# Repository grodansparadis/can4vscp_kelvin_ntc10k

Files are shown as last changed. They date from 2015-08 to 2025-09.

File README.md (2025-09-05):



-----

This project is part of the <a href="http://www.vscp.org">VSCP (Very Simple Control Protocol) project</a>. 

<hr>

# Kelvin NTC10K

This module is part of the [VSCP project](https://www.vscp.org).  It is free to use, modify and sell. The only thing we kindly ask is that improvements and extensions are contributed back to the project (at your will). This to make the project better for everyone. All design files is licensed under the [MIT license](https://en.wikipedia.org/wiki/MIT_License).

The full documentation for the module can be found [here](http://grodansparadis.github.io/can4vscp_kelvin_ntc10k/#/).



In this repository you find all development files for the Kelvin NTC10K module. The project together with the [Paris Relay Module](https://github.com/grodansparadis/can4vscp_paris) is the main examples for a VSCP implemention on a Microchip 18F PIC device.

## Abstract

Kelvin NTC10K is a temperature module that can handle six temperature sensors. One internal and five external.

The Kelvin NTC10KA module measures temperature. It measures temperatures in a wide range (depending on what sensors are used) and can achieve 0.1C accuracy with calibration. It does so by allowing connection of up to five external NTC temperature sensors and by measuring the temperature on the surface of the module itself. The measured temperature can be reported to other CAN4VSCP modules or to one or several servers so it can be collected in a database or visualized and analyzed in a diagram. The accuracy of the sensors can be increase further by calibration.

Temperature data can be presented by the module in Kelvin, Celsius or Fahrenheit.

Temperatures is reported automatically and it is possible to set alarms for high/low levels. Absolute low and high temperatures are collected and it is easy to construct autonomous and reliable temperature regulation systems.

NTC sensors has the advantage of being low cost, possible to get high accuracy from and ease of use with long cable runs. No calibration is usually needed if +-1 degree accuracy is OK.

The module fully adopts to the CAN4VSCP specification and can be powered directly over the bus with a 9-28V DC power source. It has a rich register set for configuration and any information events defined. It also have a decision matrix for easy dynamic event handling.

VSCP CAN modules are designed to work on a CAN4CAN bus which use ordinary RJ-45 connectors and is powered with 9-28V DC over the same cable. This means there is no need for a separate power cable. All that is needed is a CAT5 or better twisted pair cable. Buss length can be a maximum of 500 meters with drops of maximum 24 meters length (up to a total of 120 meters). As for all CAN4VSCP modules the communication speed is fixed at 125 kbps.

All VSCP modules contains information of there own setup, manual, hardware version, manufacturer etc. You just ask the module for the information you need and you will get it. When they are started up they have a default functionality that often is all that is needed to get a working setup. If the module have something to report it will send you an event and if it is setup to react on a certain type of event it will do it's work when you send event(s) to it. 

---

## Project files

### User manual
  * [User Manual](https://grodansparadis.github.io/can4vscp_kelvin_ntc10k/#)

### Schematic, PCB, 3D files etc
  * [Schematics reversion A](https://raw.githubusercontent.com/grodansparadis/can4vscp_accra/refs/heads/master/eagle/accra_sch_rev_A.png)
 * Hardware design files is made in [KiCad](https://kicad.org) and can be found in the `kicad` directory. Valid from reversion B of the hardware.
   * Gerber files for PCB production can be found in the `gerber` directory (in the `kicad` folder).
 * Eagle schema and board files for reversion A and B can be found in the `eagle` directory. They are no longer actively updated.

 ### Firmware

 The firmware is developed in [MPLAB X IDE](https://www.microchip.com/mplab/mplab-x-ide) using the [XC8 compiler](https://www.microchip.com/mplab/compilers).

  * Binary release files is available [here](https://github.com/grodansparadis/can4vscp_kelvin_ntc10k/releases)

### MDF - Module Description File(s)
  * [MDF file version: 1.2.0 Release date: 2015-02-18](http://www.eurosource.se/ntc10KA_3.xml)
  * [MDF file version: 1.1.0 Release date: 2014-12-24](http://www.eurosource.se/ntc10KA_2.xml)
  * [MDF file version: 1.0.0 Release date: 2012-02-24](http://www.eurosource.se/ntc10KA_1.xml)

### Support
If you need support, please open an issue in the [GitHub repository](https://github.com/grodansparadis/can4vscp_kelvin_ntc10k/issues).

### Buy a ready made modules
You can buy a ready made module from [Grodans Paradis](http://www.grodansparadis.com).

### Project related links
  * [VSCP project](https://www.vscp.org)
  * [VSCP Documentation site](https://docs.vscp.org/)
  * [VSCP Wiki](https://github.com/grodansparadis/vscp/wiki)

## Steps you should go through to adopt this file for your own VSCP project.

  * The frequency for your system may be different. This will affect the CAN bit rate settings which are defined in the biginning of the can18f.c file. Here you also find the filter/mask  defines if you need to change these. Timer0 is used as a 1 ms timer for the VSCP functionality. You should adopt the timer reload value in the main.h file to your system.

  * The GUID (Glocal Unique ID) is defined in the beginning of vscp.c This number should be different for each piece of equiment you produce. Regard it is as the device serial number. It can be moved to EEPROM if that is found more convinient. In that case the vscp_rcv_readreg  procedure in vscp.c also has to be changed.

  * The device URL is defined in the beginning of the vscp.c file. This is an URL without the initial "http://" that should point to a XML file that give information about your piece of equipment.

  * The manufacturer id is also defined in the beginning of the vscp.c file. You can use this id in any way you like.

In addition to this you may use different pins for the INIT button (RC0 today) and the status LED (RC1) today. Changes affect the main interrupt vector.

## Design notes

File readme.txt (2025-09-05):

This is the readme file for the Kelvin NTC10KA project. This project is also the base for a VSCP 
implementation on a Microchip 18F PIC device. This is a commercial module that can bought from 
Grodans Paradis ( see http://www.auto.grodansparadis.com/kelvinntc10k/kelvin_ntc10ka.html)

The processor used is the Microchip PIC18F2580 or PIC18F25K80

MPLAB X is used to build the project. Some files

eprom.h - VSCP root/firmware/pic/common)
eprom.c - (VSCP root/firmware/pic/common)
vscp_firmware.h - (VSCP root/firmware/common)
vscp_firmware.c - (VSCP root/firmware/common)
vscp_class.h - (VSCP root/src/vscp/common)
vscp_type.h - (VSCP root/src/vscp/common)

Where "VSCP Root" is the location where you installed the VSCP source tree.  Go to project page for the 
VSCP project (http://www,vscp,org) and download the sourcetree to get access to the file. 

"_reloc" projects are built for use with the bootloader. The bootloader occupies space between 0x000 and 0x1ff. 
Vectors are relocated to 0x200. This is managed in the linker scripts. Also the C initialization code has 
been changed to start code at the relocated vector. This also means that the bootloader has to be programmed
into the chip before the working with the project. It also means that the environment must be configured 
*not* to erase the chip before programming it.

If no bootloader is required it is OK to use the standard C startup code, a standard linker description. In this 
case the absolute vector address for the low priority interrupt in main.c  must be changed back from 0x218 to 0x18.

Steps you should go through to adopt this file for your own VSCP project.
=========================================================================

1.) The frequency for your system may be different. This will affect the CAN bit rate settings
which are defined in the beginning of the can18f.c file. Here you also find the filter/mask 
defines if you need to change these.

Timer0 is used as a 1 ms timer for the VSCP functionality. You should adopt the timer reload value 
in the main.h file to your system.

2.) The GUID (Global Unique ID) is defined in the beginning of vscp.c This number should be 
different for each piece of equipment you produce. Regard it is as the device serial number. It
can be moved to EEPROM if that is found more convenient. In that case the vscp_rcv_readreg 
procedure in vscp.c also has to be changed.

3.) The device URL is defined in the beginning of the vscp.c file. This is an URL without the
initial "http://" that should point to a XML file that give information about your piece of 
equipment.

4.) The manufacturer id is also defined in the beginning of the vscp.c file. You can use this
id in any way you like.

In addition to this you may use different pins for the INIT button (RC0 today) and the 
status LED (RC1) today. Changes affect the main interrupt vector.

Ake Hedman
Grodans Paradis AB
info@grodansparadis.com
http://www.grodansparadis.com

VSCP (Very Simple Control Protocol) 
http://www.vscp.org

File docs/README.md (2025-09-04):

# Manual for the Kelvin NTC10K module

**Document version:** ${/var/document-version} - ${/var/creation-time}
[HISTORY](./history.md)

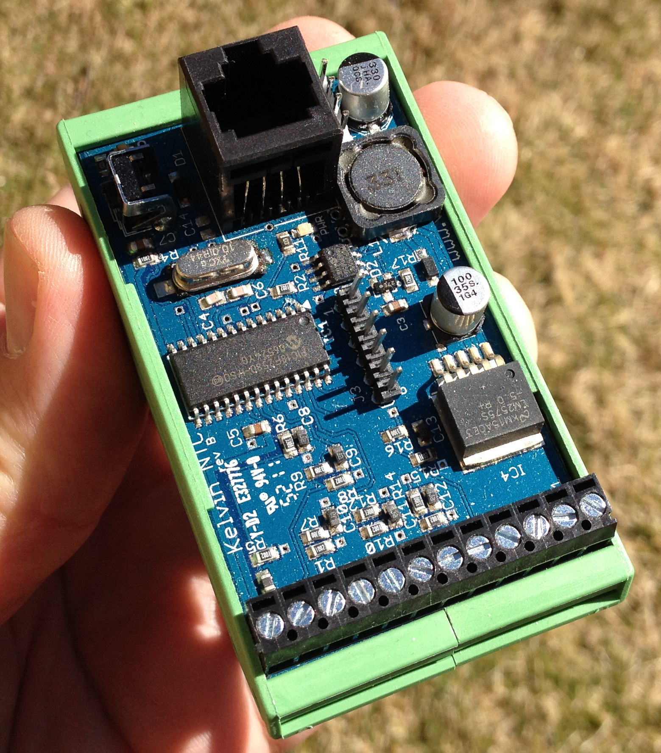
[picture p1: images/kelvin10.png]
Paris


The Kelvin NTC10KA module measures temperature. It measures temperatures in a wide range (depending on what sensors are used) and can achieve 0.1C accuracy with calibration. It does so by allowing connection of up to five external NTC temperature sensors and by measuring the temperature on the surface of the module itself. The measured temperature can be reported to other CAN4VSCP modules or to one or several servers so it can be collected in a database or visualized and analyzed in a diagram. The accuracy of the sensors can be increase further by calibration.

Temperature data can be presented by the module in Kelvin, Celsius or Fahrenheit.

Temperatures is reported automatically and it is possible to set alarms for high/low levels. Absolute low and high temperatures are collected and it is easy to construct autonomous and reliable temperature regulation systems.

NTC sensors has the advantage of being low cost, possible to get high accuracy from and ease of use with long cable runs. No calibration is usually needed if +-1 degree accuracy is OK.

The module fully adopts to the CAN4VSCP specification and can be powered directly over the bus with a 9-28V DC power source. It has a rich register set for configuration and any information events defined. It also have a decision matrix for easy dynamic event handling.

VSCP CAN modules are designed to work on a CAN4CAN bus which use ordinary RJ-45 connectors and is powered with 9-28V DC over the same cable. This means there is no need for a separate power cable. All that is needed is a CAT5 or better twisted pair cable. Buss length can be a maximum of 500 meters with drops of maximum 24 meters length (up to a total of 120 meters). As for all CAN4VSCP modules the communication speed is fixed at 125 kbps.

All VSCP modules contains information of there own setup, manual, hardware version, manufacturer etc. You just ask the module for the information you need and you will get it. When they are started up they have a default functionality that often is all that is needed to get a working setup. If the module have something to report it will send you an event and if it is setup to react on a certain type of event it will do it's work when you send event(s) to it. 

  * [GitHub repository for the module](https://github.com/grodansparadis/can4vscp_kelvin_ntc10k)
  * This manual is available [here](https://grodansparadis.github.io/can4vscp_kelvin_ntc10k/)
  * Latest KiCad schema for the module is available [here](https://github.com/grodansparadis/can4vscp_kelvin_ntc10k/tree/master/kicad)
  * Latest firmware for the module is available [here](https://github.com/grodansparadis/can4vscp_kelvin_ntc10k/tree/master/firmware)
  * [MDF for the module](https://github.com/grodansparadis/can4vscp_kelvin_ntc10k/tree/master/mdf)

## VSCP

VSCP logo

VSCP is a free and open automation protocol for IoT and m2m devices. Visit [the VSCP site](https://www.vscp.org) for more information.

**VSCP is free.** Placed in the **public domain**. Free to use. Free to change. Free to do whatever you want to do with it. VSCP is not owned by anyone. VSCP will stay free and gratis forever.

The specification for the VSCP protocol is [here](https://docs.vscp.org) 

VSCP documentation for various parts can be found [here](https://docs.vscp.org/).

If you use VSCP please consider contributing resources or time to the project ([https://vscp.org/support.php](https://vscp.org/support.php)).

## Document license

This document is licensed under [Creative Commons BY 4.0](https://creativecommons.org/licenses/by/4.0/) and can be freely copied, redistributed, remixed, transformed, built upon as long as you give credits to the author.

[filename](./bottom-copyright.md ':include')

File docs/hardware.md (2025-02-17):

# Hardware

## Most current information

You can find the most current information about the Kelvin NTC10K module [here](https://github.com/grodansparadis/can4vscp_kelvin_ntc10k). On the site you can also find links to the latest firmware, drivers and schematics etc for its use.

## Installing the module

Connect the module to the CAN4VSCP bus. The red LED on the module should light up indicating that the device is powered. If this is the first time you start up the module the green lamp next to the initializing button will start to blink. This means that the module is trying to negotiate a nickname address with the rest of the modules on the bus. When it found a free nickname the green LED will light steady. If the green led does not start to blink press the initialization button until it does.

Remember that you need at least two devices (a CAN interface count as one) on the bus for it to work. If you only have one device on the bus it will not work. A single device can't talk to itself on a bus. It's an error.

Now your module is ready to use. 

## The raw facts

| Parameter | Value |
| --- | ----- |
| Current hardware reversion | B |
| Current firmware version | 1.2.7 |
| Supply voltage | +9-+28 VDC |
| PCB Size | 42mm x 72mm |
| Mounting options | DIN or wall |
| Power requirements | 0.1W |
| Communication: CAN4VSCP (CAN) | 125 kbps |
| Number of sensors supported | 6 (one internal) |

## Schematics

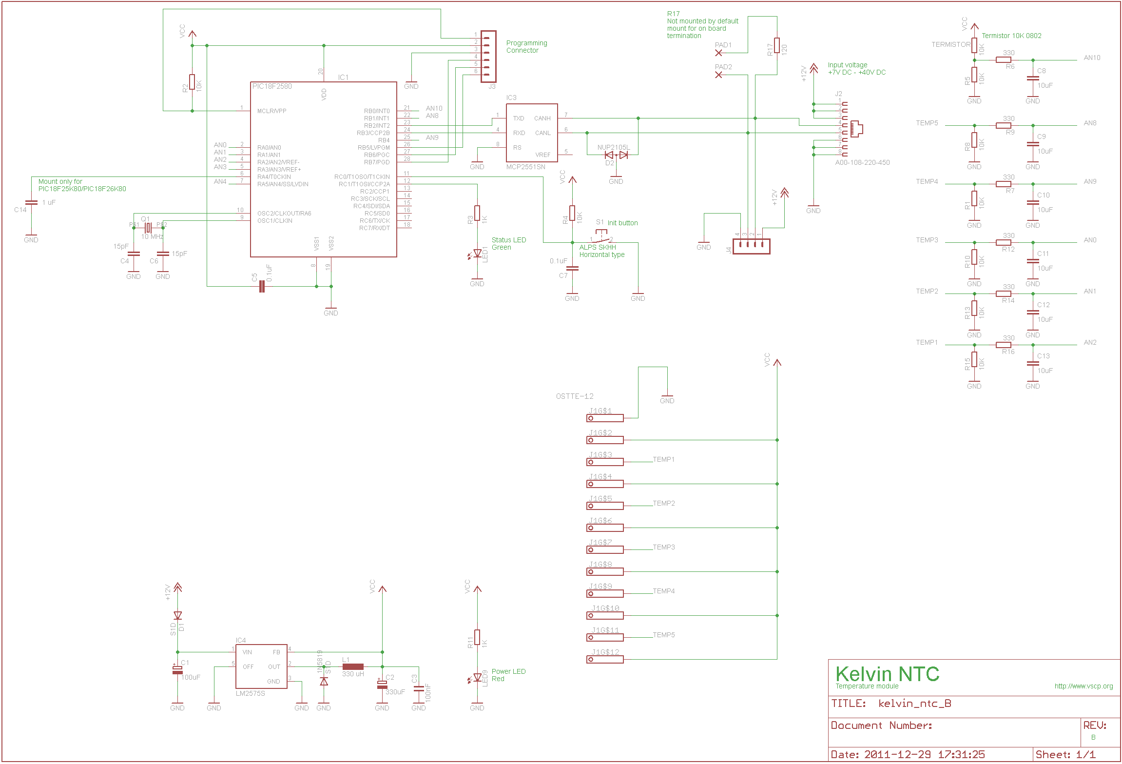
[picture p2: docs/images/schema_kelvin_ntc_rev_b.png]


Schematics: Rev B  (right click and select view image to see it in full size)

## Components

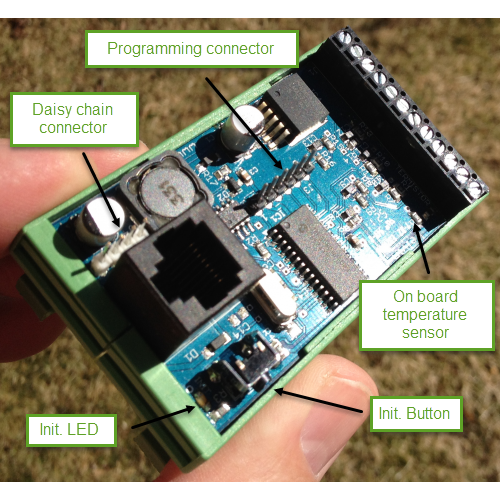
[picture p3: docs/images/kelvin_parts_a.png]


The green **Init LED** show operational status. It blinks during initialization process and lights steady under normal operation.

Press the **init. button** to initiate the node id discovery process. The green led will start to blink and do so until a new nickname id is found. If the LED never stops blinking that is an indication of some bus fault of some kind. Typically the module does not get an answer from another module on the bus.

The **daisy chain** connector is described below.

The firmware of a circuit equipped with a Microchip microprocessor usually can be programmed in circuit. That is when it is mounted on a printed circuit board. This is also true for the Paris relay module which have the programming connector on-board (J3). The **programming
connector** is used to reprogram the module. This is more convenient to do using the bootloader software but in debugging or if the bootloader has gotten corrupt connecting a standard Microchip PIC programmer to this connector is the only way to reprogram the module. If you have a programmer for Microchip processors (Real ICE, ICD-2, ICD-3, PICKIT-2, PICKIT3 or other) you can program your own firmware or the latest official firmware into the module using MPLABX or similar tools. You can always find a link to the latest firmware on the [Kelvin NTC10K module
home page](https://www.grodansparadis.com/kelvinntc10k/kelvin_ntc10ka.html).

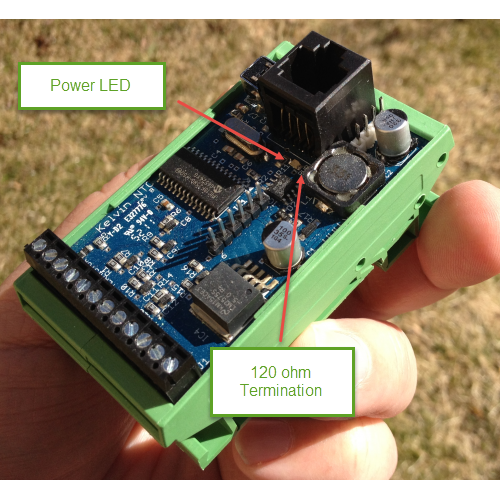
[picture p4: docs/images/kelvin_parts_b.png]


The **power LED** (red) will light when the board is powered.

The **termination jumper** is used to activate the 120 ohm termination resistor between CANH and CANL if present. This is convenient if the module is the first or last module on a bus.

## Connectors

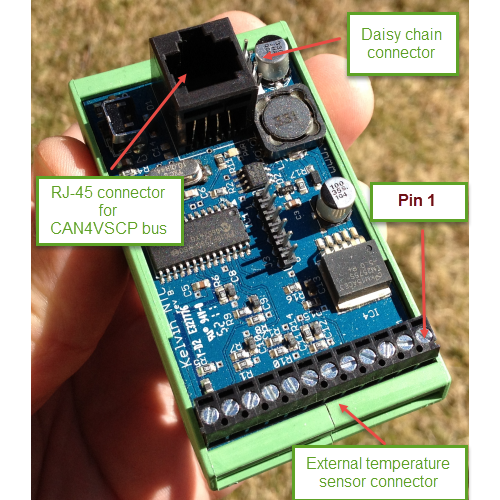
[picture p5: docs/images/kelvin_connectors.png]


To activate the **termination** solder a cable between holes. This will activate the 120 ohm resistor between CANH and CANL.

### Terminal block

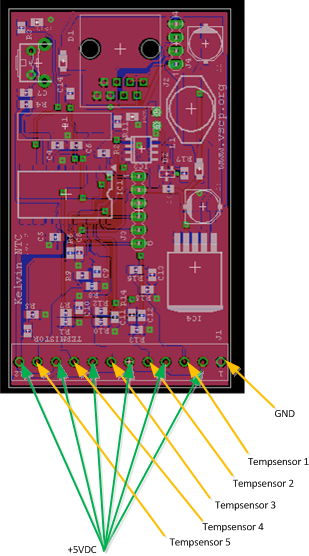
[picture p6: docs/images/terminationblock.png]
  

The individual positions for the twelve position termination block is numbered from the right (looking into it) as in the figure below.



| Pin | Description |
| --- | --- |
| 1 | Ground (GND) |
| 2 | +5V |
| 3 | Temperature sensor 1 |
| 4 | +5V|
| 5 | Temperature sensor 2|
| 6 | +5V|
| 7 | Temperature sensor 3 |
| 8 | +5V |
| 9 | Temperature sensor 4 |
| 10 | +5V |
| 11 | Temperature sensor 5 |
| 12 | +5V |

where all temperature sensor inputs looks like this

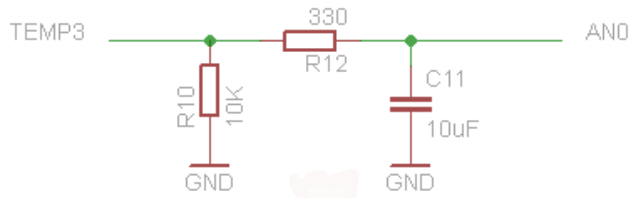
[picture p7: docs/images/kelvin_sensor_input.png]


## Internal temperature sensor

The internal temperature sensor used on the Kelvin NTC10KA is the [Murata NCP21XV103J03RA](https://www.google.se/url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). Data for this sensor is as follows

| Description | Value |
| --- | ----- |
| Time constant | 10 s |
| B[25/100]- value | 3944K |
| Temperature range |-40...+125ºC |
| Resistance tolerance | 5% |
| Resistance @ 25ºC | 10 Kohm |
| Max effect | 210 @ 25ºC mW |
| B[25/50]- value | 3900 |
| B[25/85]- value | 3934 |
| B[25/100]- value | 3944K 3% |
| Max error (B[25/100])	| 2.8 (%/C) |

As stated elsewhere this sensor will show a temperature value that is to high due to the fact that it is heated by the processor and other components on the board. You can calibrate this away if you want. The sensor is used to show the temperature of the board and is not intended to be used for high precision measurements.

### RJ-XX pin-out

The unit is powered over the CAN4VSCP bus. The CAN4VSCP normally uses CAT5 or better twisted pair cable. You can use other cables if you which. The important thing is that the CANH and CANL signals uses a twisted cable. For connectors you can use RJ10, RJ11, RJ12 or the most common RJ45 connectors.

Recommended connector is RJ-34/RJ-12 or RJ-11 with pin out as in this table.

| Pin | Used for  | RJ-11  | RJ-12 | RJ-45 |  Patch Cable wire color T568B |
|:---:|:---:|:---:|:-----:|:-----:| --- |
|  1 | +9-28V DC | | | RJ-45 | Orange/White |
|  2 1 | +9-28V DC | | RJ-12 | RJ-45 | Orange |
|  3 2 1  | +9-28V DC | RJ-11  | RJ-12 | RJ-45 | Green/White |
|  4 3 2  | CANH | RJ-11  | RJ-12 | RJ-45 | Blue |
|  5 4 3  | CANL | RJ-11  | RJ-12 | RJ-45 | Blue/White |
|  6 5 4  | GND | RJ-11  | RJ-12 | RJ-45 | Green |
|  7 6 | GND | | RJ-12 | RJ-45 | Brown/White |
|  8 | GND | | | RJ-45 | Brown |

RJ-11/12/45 pin-out

Always use a pair of twisted wires for CANH/CANL for best noise immunity. If the EIA/TIA 56B standard is used this condition will be satisfied. This is good as most Ethernet networks already is wired this way.

### Inter module connector

The inter module connector can be used to connect modules that are physically close to each other together in an easy way. Remember that the minimum length of a connection cable is 30 cm.

The **daisy chain connector** is an alternative to the RJ-45 connector and can be a very convenient way to connect boards together that are mounter close to each other, in the same cabinet for example. The [power injector board](http://www.grodansparadis.com/pwrinjectcan/pwrinjectcan.html) is a perfect companion for this use.

| Pin | Description |
| :---: | --- |
| 1 | Power from CAN4VSCP bus (+9V-24V) |
| 2 | CANH |
| 3 | CANL |
| 4 | GND |

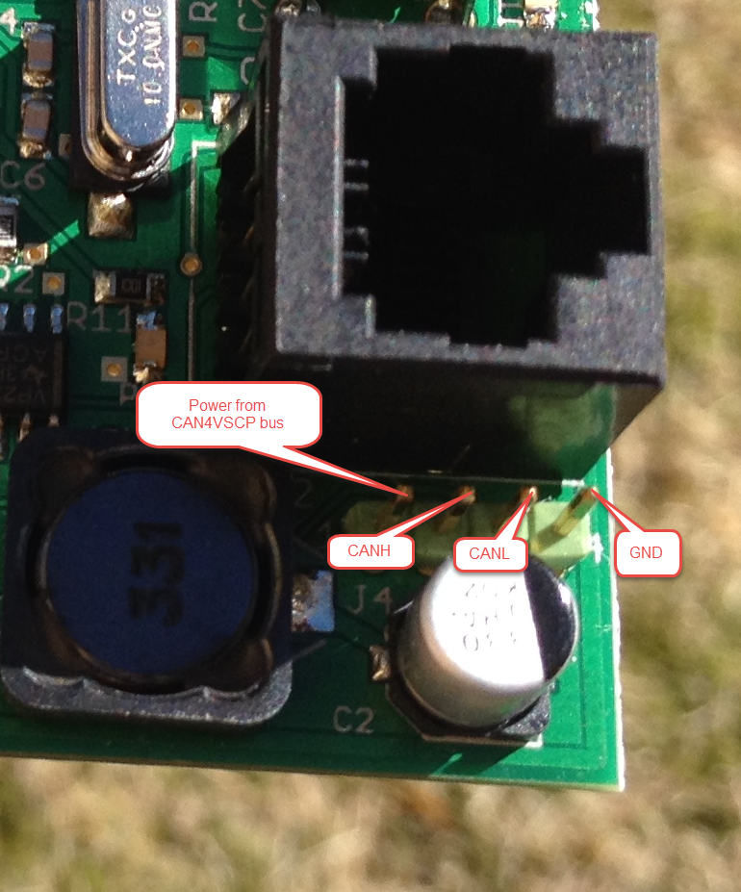
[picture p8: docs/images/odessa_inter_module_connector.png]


### PIC programming Connector

| pin | Description |
| :---: | --- |
| 1 | Reset |
| 2 | VCC |
| 3 | GND |
| 4 | PGD (RX of second serial port is here to) |
| 5 | PGC (TX of second serial port is here to) |
| 6 | LWPGM |

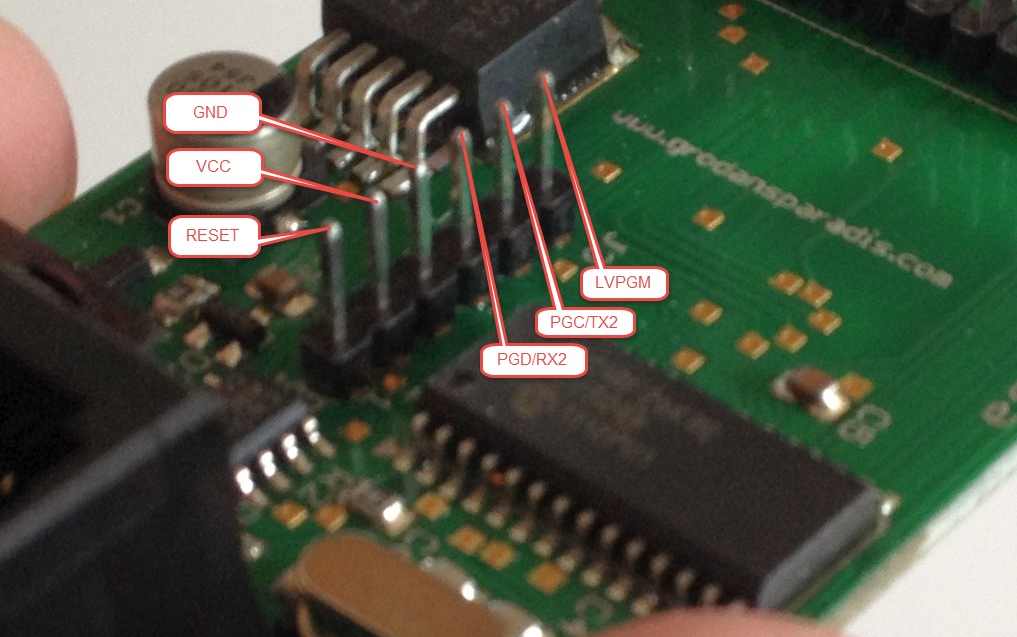
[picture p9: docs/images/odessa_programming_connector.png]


### Functionality of the status LED

The LED is used to indicate the status of the module. It will light steady when the firmware is running and will blink when the module is in the nickname discovery process.

| LED | Description |
| :---: | --- |
| Steady | No error. Firmware running. |
| Blinking | Module is going through the [nickname discovery process](https://grodansparadis.github.io/vscp-doc-spec/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). |

### CAN

CAN4VSCP is a CAN based bus running at 125 kbps with the addition of DC power. If you are interested in how CAN works you have a pretty good intro [here](http://www.eeherald.com/section/design-guide/esmod9.html).

CAN is known to be robust and is there for used in vehicles and in the industry for that reason.

[filename](./bottom-copyright.md ':include')

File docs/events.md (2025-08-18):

# Events

Here the events sent by the module is described.

 ====== Events ======

Here the events sent by the module is described.

===== Temperature Event =====

^ Event ^ Description ^
|  [[http://www.vscp.org/docs/vscpspec/doku.php?id=class1.measurement#type_6_0x06_temperature|CLASS1.MEASUREMENT (10) Type=6, Temperature]]  | If enabled this event is sent periodically for each sensor. The temperature is reported as a normalized integer value by this event. The event frequency is set in register 20-25 (default is one event per 30 seconds) and must be set to a non zero value for it to be sent.\\ \\ Temperature can be reported in one of three units. Kelvin, Celsius (default) or Fahrenheit as set in register 2-7. \\ \\ __**Data**__\\ **Byte 0** - Data coding byte. See description below.\\ **Byte 1** - Always 130 (0x82). Decimal point should be shifted two steps to the left = divide with hundred.\\ **Byte 2** - MSB of normalized integer. Two complement number.\\ **Byte 3** - LSB of normalized integer. Two complement number.\\ \\  |

The data coding byte is the measurement data coding format described in [[http://www.vscp.org/docs/vscpspec/doku.php?id=data_coding|the VSCP specification]].

The normalized integer is stored as a two complement 16-bit integer. To convert

1. Calculate the 16-bit twos complement as MSB byte * 256 + LSB byte.

2. If the most significant bit is not set (Equal or less then 32767) this is a positive temperature. Divide by 100 and you have the temperature. 

3. If the most significant bit is set (Greater than 32767) this is a negative temperature. Now invert the result (the bits are inverted; 0 becomes 1, and 1 becomes 0) and add one to the result. Dive by 100 and you have the temperature.

==== Example: A negative temperature in Celsius from sensor 1 ====

The data part of the event will be

^ Byte ^ Description ^
| Byte 0 | 130 (0x82) |
| Byte 1 | 2 (0x02) |
| Byte 2 | 255 (0xF0) |
| Byte 3 | 216 (0x60) |

  - **Byte 0**: Normalized integer, Celsius, Sensor 1
  - **Byte 1**: Decimal point should be shifted two steps to the left.
  - **Byte 2/3**: Bit 16 is a one meaning it's a negative number. Temperature is a two complement number. 0xF060 = 0b1111000001100000. Invert which give 0b0000111110011111 add one which give 0b0000111110100000 = 4000. Divide by 100 gives 40.00 The read temperature is -40.00 ºC.

==== Example: A positive temperature in Celsius from sensor 1 ====

The data part of the event will be

^ Byte ^ Description ^
| Byte 0 | 130 (0x82) |
| Byte 1 | 2 (0x02) |
| Byte 2 | 46 (0x2E) |
| Byte 3 | 224 (0xE0) |

  - **Byte 0**: Normalized integer, Celsius, Sensor 1
  - **Byte 1**: Decimal point should be shifted two steps to the left.
  - **Byte 2/3**: Bit 16 is zero meaning it's a positive number. 0x2EE0 = 12000. Divide by 100 gives 120.00. The temperature is 120.00 ºC. 

==== Example: A negative temperature in Fahrenheit from sensor 5 ====

The data part of the event will be

^ Byte ^ Description ^
| Byte 0 | 249 (0xF9) |
| Byte 1 | 2 (0x02) |
| Byte 2 | 255 (0xFF) |
| Byte 3 | 118 (0x76) |

  - **Byte 0**: Normalized integer, Fahrenheit, Sensor 5
  - **Byte 1**: Decimal point should be shifted two steps to the left.
  - **Byte 2/3**: Bit 16 is a one meaning it's a negative number. Temperature is a two complement number. 0xFF76 = 0b1111111101110110. Invert which give 0b0000000010001001 add one which give 0b0000000010001010 = 138. Divide by 100 gives 1.38 The read temperature is -1.38 ºF.

==== Data coding byte for Kelvin ====

^ Bits ^ Description ^
| 5,6,7	| Always set to 4 (0b100) - Normalized integer format. |
| 3,4 | __**Unit**:__\\ **0 (0b00)** - Kelvin.\\  **1 (0b01)** – Celsius.\\  **2 (0b10)** – Fahrenheit. |
| 0,1,2	| __**Sensor Index**:__\\ **0 (0b000)** - Sensor 0.\\ **1 (0b001)** - Sensor 1.\\ **2 (0b010)** - Sensor 2.\\ **3 (0b011)** - Sensor 3.\\ **4 (0b100)** - Sensor 4.\\ **5 (0b101)** - Sensor 5. |

To help to interpret data the three tables below list the datacoding bytes for Kelvin, Celsius and Fahrenheit temperature presentation.

=== Kelvin data coding table ===

^ Sensor ^ Value for data coding byte ^
| Sensor 0 | 129 (0x81) |
| Sensor 1 | 130(0x82) |
| Sensor 2 | 131(0x83) |
| Sensor 3 | 132(0x84) |
| Sensor 4 | 133(0x85) |
| Sensor 5 | 134(0x86) |

=== Celsius data coding table ===

^ Sensor ^ Value for data coding byte ^
| Sensor 0 | 136(0x88) |
| Sensor 1 | 137(0x89) |
| Sensor 2 | 138(0x8A) |
| Sensor 3 | 139(0x8B) |
| Sensor 4 | 140(0x8C) |
| Sensor 5 | 141(0x8D) |

=== Fahrenheit Vdata coding table ===
^ Sensor ^ Value for data coding byte ^
| Sensor 0 | 244 (0xF4) |
| Sensor 1 | 245 (0xF5) |
| Sensor 2 | 246 (0xF6) |
| Sensor 3 | 247 (0xF7) |
| Sensor 4 | 248 (0xF8) |
| Sensor 5 | 249 (0xF9) |

===== Alarm Event =====

If enabled the event is sent when a temperature sensor goes below a low alarm set point (see [[http://www.grodansparadis.com/kelvinntc10k/manual/doku.php?id=registers|Low-alarm-registers]]) or above a high alarm set point (see [[http://www.grodansparadis.com/kelvinntc10k/manual/doku.php?id=registers|High-alarm-registers]]). The hysteresis registers is used so that after an alarm event has been sent a new alarm event is not sent until the temperature goes below/above the value set in the set point plus(low)/minus(high) signed content of hysteresis register. 

A read of the alarm register will reset the alarm status and alarm events will not be sent out again until the the temperature changed with the hysteresis amount.

^ Event ^ Description ^
|  [[http://www.vscp.org/docs/vscpspec/doku.php?id=class1.alarm#type_2_0x02_alarm_occurred|CLASS1.ALARM, Type=2, Alarm occurred]]  | __**Data**__\\ **Byte 0** - Index. Index is 0 for Sensor 0. 1 for Sensor 1, 2 for Sensor 2. 3 for Sensor 3. 4 for Sensor 4. 5 for Sensor 5. \\ **Byte 1** - Zone.\\ **Byte 2** - Sub zone. |

Zone and sub-zone are the modules settings for the sensor generating the alarm. See [[http://www.grodansparadis.com/kelvinntc10k/manual/doku.php?id=registers|register 74-85]]

===== TurnOn/TurnOff Event =====

If enabled, the event [[http://www.vscp.org/docs/vscpspec/doku.php?id=class1.control#type_5_0x05_turnon|CLASS1.CONTROL, Type=5, TurnOn]] or [[http://www.vscp.org/docs/vscpspec/doku.php?id=class1.control#type_6_0x06_turnoff|CLASS1.CONTROL, Type=6, TurnOff]] (Bit 5 in control register must be set (see [[registers#sensor_control_ registers|Control-registers]]])) is sent when the temperature goes below or above the low(see [[registers#low_ alarm_registers|Low-alarm-registers]]/high(see [[registers#high_ alarm_registers|High-alarm-registers]] alarm set points. Settings in the control register bit 6 (see [sub:Control-registers]) decides which of the **TurnOn/TurnOff** event that is sent. The hysteresis setting (see [sub:Sensor-hysteresis-registers]) tells how much a temperature must raise or fall below the alarm set point before a new event will be sent.

^ Event ^ Description ^
|  [[http://www.vscp.org/docs/vscpspec/doku.php?id=class1.control#type_5_0x05_turnon|CLASS1.CONTROL, Type=5, TurnOn]]  | __**Data**:__\\ **0** Index,\\ **1** Zone.\\ **2** Sub zone. |

^ Event ^ Description ^
|  [[http://www.vscp.org/docs/vscpspec/doku.php?id=class1.control#type_6_0x06_turnoff|CLASS1.CONTROL, Type=6, TurnOff]] | __**Data**:__\\ **0** Index,\\ **1** Zone.\\ **2** Sub zone. |

__**Index**__ is 0 for Sensor 0, 1 for Sensor 1, 2 for Sensor 2. 3 for Sensor 3. 4 for Sensor 4. 5 for Sensor 5. 

__**Zone**__ information is fetched from sensor zone register (see [[http://www.grodansparadis.com/kelvinntc10k/manual/doku.php?id=registers#sensor_zone_information_registers|sensor zone information registers]]). 

__**Sub zone**__ information is fetched from sensor sub-zone register (see [[http://www.grodansparadis.com/kelvinntc10k/manual/doku.php?id=registers#sensor_zone_information_registers|sensor zone information registers]]).

===== Sync. Event (incoming) =====

If a SYNC event is received by the module it will check the zone/subzone parameters of the event and send out [[http://www.grodansparadis.com/kelvinntc10k/manual/doku.php?id=events#temperature_event|temperature measurement event(s)]] for all sensors that match. This can be a handy feature to use of one want synchronized data from several sources.

^ Event ^ Description ^
|  [[http://www.vscp.org/docs/vscpspec/doku.php?id=class1.control#type_26_0x1a_sync|CLASS1.CONTROL, Type=26, Sync]]  | __**Data**:__\\ **0** Index,\\ **1** Zone.\\ **2** Sub zone. |

[filename](./bottom-copyright.md ':include')

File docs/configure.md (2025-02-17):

# Configure the module

You configure a VSCP module by writing content into the modules registers. You can do this manually or with the wizard available in VSCP works. Using the wizard is absolutely the easiest way to accomplish different things.

## Sensor calibration

Thermistors are very accurate but non linear devices. Still you may find that Kelvin NTC10K show you the wrong value of the measured temperature. This is because the sensor often need calibration or that registers need to be set to correct values. With calibration you can get very accurate results. For the best result you typically calibrate at three points, in ice + water mix, at 25 degrees Celsius and in boiling water. For most cases one calibration point will do but it all depends on what needs you have.

There is several registers that affect the reported temperature value. First of all there is the(Beta value registers)[registers.md?id=B2_constant_registers]. The value in these registers should be the Beta value for the sensor (and the range you use). Alternatively a value you get form calibration as of above.

The next value is the [[registers#voltage_calibration_registers|voltage calibration value]]. This value is ten thousand times the voltage of the Kelvin NTC board. This is thus normally 50000 (for 5V) which is 0xC350 in hexadecimal. If the voltage of your board is not 5.00 volts you can enter the correct value here. This value seldom need a change.

The last and most important place are the  [[registers#sensor_calibration_registers|sensor calibration registers]] which can be used to set up a calibration value for each sensor that will be added or subtracted from the read value before it is reported. 

Values are stored as [twos complement numbers](https://www.cs.cornell.edu/~tomf/notes/cps104/twoscomp.html) and is as usual 100 times the actual value.

For example your sensor shows a temperature that is 1.4 degrees to low. 1.4 time 100 is 140 which is 0x008C in hexadecimal. So store 0x00 in the MSB byte and 0x8C in the LSB byte of the calibration value for that sensor. Now 1.4 degrees will be added to the measured value before it is reported and used in calculations.

Another sample is if your sensor measure a value that is 1.9 degrees to high. We therefore need to subtract 1.9. 100 * -1.9 = -190. This is  0xFF42 as a twos complement number  (190 =   0x00BE (0000 0000 1011 1110), Invert which give 0xFF41 (1111 1111 0100 0001), add one which gives 0cxFF42).

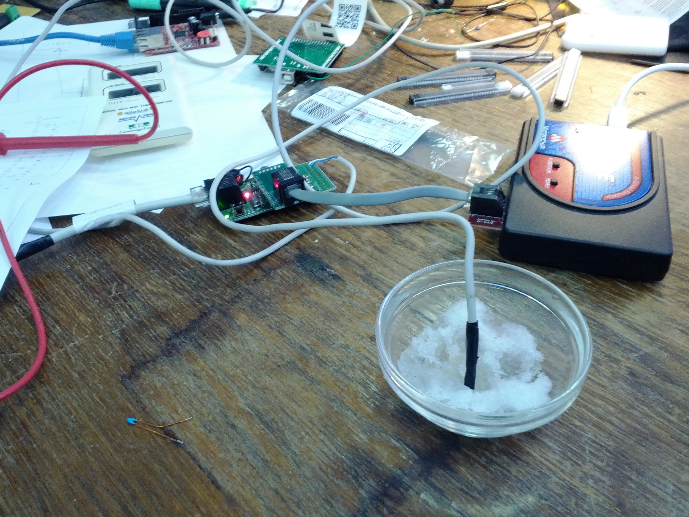
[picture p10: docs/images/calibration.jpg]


A good method to use to calibrate sensors is to mix ice and water and put the sensor in the mix. This will be zero degrees Celsius. To get another point boil some water and measure the temperature in the middle of the container without touching the walls.

A good tool for calibration is available on [this page](http://www.thinksrs.com/downloads/programs/Therm%20Calc/NTCCalibrator/NTCcalculator.htm) where you can calculate the Beta value for a sensor from two calibration points.

## Zones and sub zones

Zones and sub zones are used to group things together. Normally you don't address events to a certain receiver in VSCP ([CLASS1.PROTOCOL](http://www.vscp.org/docs/vscpspec/doku.php?id=class1.protocol) being the exception that prove this rule). Instead you report/send things to a group of modules defined by a zone and a sub zone. The sender have no knowledge of how many units this zone/sub zone consist of. Well it does not even care.

Zone and sub zone for the module can be set in the  (module zone registers)[./registers?id=module-zone-registers]. But more useful than the module zone sub zone is the zone information for each individual sensor that is available in the (sensor zone registers)[./registers?id=sensor-zone-information-registers]. Here you can specify the zone/sub zone units you think is interested in this event. You can also set them both (or one of them) to 0xff meaning all zones, sub zones.

Think of a zone as a house, floor plan or similar and sub-zone as a room or a location.  Or let the MSB bits of the zone be the floor plan, the LSB bits of the zone be the room on that floor plan and the sub zone be a group of functionality for that room. Note again that this is not an address. It's just a way to group functionality together.

It is good to think this through before you start to configure a system with VSCP modules.

## β constants 

In registers (β constants)[./registers?id=β-constant-registers] you have registers that hold β (beta) values for each sensor. To get correct temperature readings it is important that you enter the correct value here for the sensor you use. You find this information in the data sheet for the sensor.

## Sensor Control Registers 
In registers [[registers#description_of_control_register_bits|0:2 - 0:7]] you can configure how sensor data is reported and acted up on. You can set the unit you want temperatures to be reported in. You can enable alarms. You can define that TurnOn/TurnOff events should be sent when levels have been reached or data has been found to be below a certain level. And other things. 

## Temperature measurements 
If you have gone through the steps above you can now read temperature data in [[registers#temperature_registers|registers 0:8 - 0:19]]. The temperature is shown in the selected unit as an integer which is temperature * 100. 

The temperature registers is located in pairs (Most significant byte followed my the least significant byte) and they can be read to get the current temperature for each sensor. The temperature is stored as a 16-bit two complement of a normalized temperature. This means you have to divide the read temperature by 100 to get the temperature value. 

To get the temperature and calculate the temperature for a specific sensor. 

* Read MSB register. Read LSB register.
* Calculate the 16-bit twos complement as MSB reading * 256 + LSB reading.
* If the most significant bit is not set (Equal or less then 32767) this is a positive temperature. Divide by 100 and you have the temperature. 
* If the most significant bit is set (Greater than 32767) this is a negative temperature. Now invert the result (the bits are inverted; 0 becomes 1, and 1 becomes 0) and add one to the result. Dive by 100 and you have the temperature.

However usually this is not the way to get temperature readings. Instead you set a report interval for a sensor expressed in seconds in the [report interval register](./registers#report_interval_registers) (or set to zero to turn of reporting) and get temperature readings automatically delivered/reported.

After entering a value here [temperature events](./events#temperature_event) will be sent with the configured interval. The receiver of this information can be another module, a routine that writes them to a database or a websocket widget that diagram them live on a screen or on a web page.

## Alarms

In the [low alarm register](registers#low_alarm_registers) and in the [high alarm registers](registers#high_alarm_registers) registers you can set the levels at which [alarm events](events#alarm_event) are sent.

An activated low alarm event (activated by setting bit 3 in the [control register](registers#description_of_control_register_bits)) is sent when the temperature is going below the low alarm value. When this happens the low alarm bit in the `standard alarm register` is set. This bit will only be rested by reading the alarm register. The alarm is considered active as long as the temperature is below the low alarm set point + the hysteresis value set in [sensor hysteresis registers](registers#sensor_hysteresis_registers). So if temperature moves above this point a new alarm event will be sent again when temperature again is moving below the set point.

An activated high alarm event (activated by setting bit 4 in the [control register](registers#description_of_control_register_bits)) is sent when the temperature is going above the high alarm value. When this happens the high alarm bit in the `standard alarm register` is set. This bit will only be rested by reading the alarm register. The alarm is considered active as long as the temperature is above the low alarm set point - the hysteresis value set in [sensor hysteresis registers](registers#sensor_hysteresis_registers). So if temperature moves below this point a new alarm event will be sent again when temperature again is moving above the set point.

It is possible to have continuous alarms events sent by setting bit 7 in the [control register](registers#description_of_control_register_bits). An alarm event will be sent every second while the alarm condition persist.

## Controlling things 

Instead of alarms [CLASS1.CONTROL, TurnOn](https://grodansparadis.github.io/vscp-doc-spec/#/./class1.control?id=type5) and [CLASS1.CONTROL, TurnOff](https://grodansparadis.github.io/vscp-doc-spec/#/./class1.control?id=type6) events can be sent.  This functionality is activated by setting **bit 5** in the [control registers](./registers?id=sensor-control-registers). 

Another bit, bit 6, in the control register decides when the TurnOff/TurnOn events are sent. If set to zero TurnOff is sent when the high point is reached and TurnOn when the low point is reached. Suitable for control of a heating system for example. If the bit is set the TurnOn event is sent at the high set point and the TurnOff is sent on the low set point. Suitable for a cooling system.

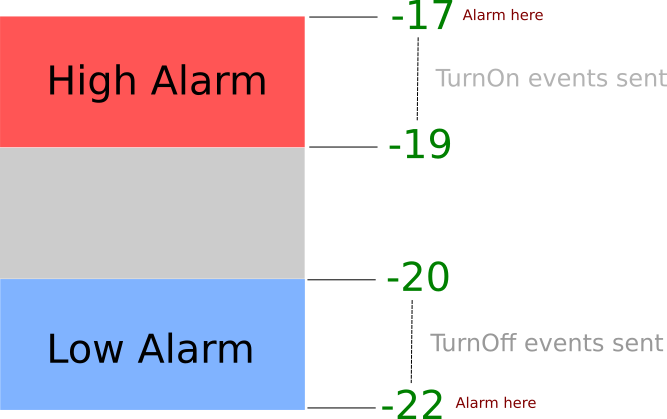
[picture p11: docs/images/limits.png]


The picture shows a real world example where a Kelvin NTC10K module measures temperature in a fridge which have its compressor controlled by a [[http://www.grodansparadis.com/paris/paris.html|Paris relay module]]. The [Paris decision matrix](http://grodansparadis.github.io/can4vscp_paris/#/./decisionmatrix) is programmed to turn on the compressor when TurnOn events is received from the the zone/subzone programmed into the Kelvin NTC10K module sensor that measure the fridge temperature.

So here TurnOff events are sent by the Kelvin NTC10K module when the temperature go below -22 degrees Celsius. This event is received by the Paris module and it turn of the relay that controls the fridge compressor. Continuous mode is activated so the TurnOff events are sent until the temperature reach -20 degrees Celsius. A function to protect against events not being delivered.

When the temperature goes up above -20 degrees Celsius no events will be sent until the temperature go above -17 degrees Celsius. At this point TurnOn events will be sent which are received by the Paris module which turn on the relay that control the Fridge compressor. TurnOn events are sent continuously until the temperature go down to -19 degrees Celsius and again there will be a dead zone until the temperature falls to -22 degrees Celsius.

## Some samples

<html>
<iframe width="420" height="315" src="https://www.youtube.com/embed/37PQomplUVE" frameborder="0" allowfullscreen></iframe>
</html>

<html>
<iframe width="420" height="315" src="https://www.youtube.com/embed/L17d1SSyBc0" frameborder="0" allowfullscreen></iframe>
</html>

<html>
<iframe width="560" height="315" src="https://www.youtube.com/embed/qV41vWt5toE" frameborder="0" allowfullscreen></iframe>
</html>

[filename](./bottom-copyright.md ':include')

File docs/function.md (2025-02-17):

# Functional Description 

## Configure the module

You configure a VSCP module by writing content into the modules
registers. You can do this manually or with the wizard available in
[VSCP Works+](https://grodansparadis.github.io/vscp-works-qt/#/).
Using the wizard is absolutely the easiest way to set up functionality.

## Zone/sub-zone

You should always plan your overall structure. The zone and the sub-zone registers found in the first two register positions can help you here. Think of a zone as a (logical) house,floor plan or similar and sub-zone as a room or a location.

Note that this is not an address. It\'s a way to group functionality together.

Each temperature sensor can belong to it\'s own sub-zone or to a common sub-zone.

## Logging temperature

The module can automatically log temperature data and send it to other modules or to a remote server for further processing. This is easy to setup, you just set the interval you want and temperature eventes will be delevered periodically from the module. See the [register section](./registers.md?id=report-interval-registers).

## Alarm when temperature is out of range
To protect sensitive equipment or to control heating or cooling you can set up alarms for high and low temperature. When a temperature sensor goes above or below a set value an alarm event is sent. You can set the alarm limits in the [low alarm registers](./registers.md?id=low-alarm-registers) and in the [high alarm registers](./registers.md?id=high-alarm-registers).

Now activating high or low or both in the [control register](http://localhost:3000/#/./registers?id=sensor-control-registers) for the sensor will make the module send out alarm events when the temperature goes above or below the set value.

The [hysteresis](./registers?id=sensor-hysteresis-registers) registers can be used to set a hysteresis value for the alarm. This is the value the temperature must go below or above the set value before the alarm is cleared.

The module can even send events that turn och heatingcontrollers instead of alarm events. Just set bit 5 of the [control register](./registers?id=sensor-control-registers) and CLASS1_CONTROL, Turn ON  will be sent when the low set point is reached (minus hysteresis) and CLASS1_CONTROL, Turn OFF events will be sent when the high setpoint is reached. Setting bit 7 will make theese events continious.

## Cooling

If you want to control a cooling system. Just set the cooling bit in the [control register](./registers?id=sensor-control-registers) and the module will send out [CLASS1_CONTROL, Turn ON events](https://grodansparadis.github.io/vscp-doc-spec/#/./class1.control?id=type5) when the high setpoint is reached and [CLASS1_CONTROL, Turn OFF events](https://grodansparadis.github.io/vscp-doc-spec/#/./class1.control?id=type6) when the low setpoint is reached. Setting bit 7 will make theese events continious, and events will be sent out every second.

Typically the sent events are feed to the [decision matrix](https://grodansparadis.github.io/vscp-doc-spec/#/./vscp_decision_matrix) of another module (or several) that do the action of turning on or off cooling equipment and thereby creating a self contained control system.

## Alarm

The module can send alarm events if the temperatur for a sensor goes above or below a set temperature value. When an alarm occurs a bit is set in the alarm register which is located in standard register position 128/0x80. You can read this register to see if the module have sent out any alarm events. When you read the register the alarm bits in the alarm register will be cleared.

[filename](./bottom-copyright.md ':include')

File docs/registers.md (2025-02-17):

# Introduction

All VSCP modules have a set of 8-bit registers defined to export it's functionality in a common way. Some of them (register 128-255) are predefined and the information in them are the same for all VSCP modules. See the [VSCP specification](https://grodansparadis.github.io/vscp-doc-spec/#/./vscp_register_abstraction_model) for a description of their content.

The lower 128 register space is used for module specific registers. It is also here you find registers with which you configure your module. Also registers where you typically can read status information such as measurement data from the module is here.

The lower register space is further expanded in register pages (0-65535).

The registers of the Kelvin NTC10K module control the behaviour of the module. You write to the registers to configure the module and read from the registers to get status information from the module.

With the registers you can set the unit in which the temperature measureent will be reported. You can read sensor values. Set periods for sensor value reporting. set high and low alarm points. Set hysteresis for the alarms. Set the B value for the NTC sensor. Set the zone and subzone for the sensor. Set absolute high and low values for the sensor. Set calibration values for the sensor. Set the voltage used for the sensor. Read raw A/D values from the sensor. An more.

Below is a description of the registers available for the Kelvin NTC10KA module.

# Register page 0

## Module zone registers

| Register | Page | Description |
| :---: | :----: | --- |
|  0  |  0  | The zone this module belongs to. |
|  1  |  0  | The sub zone this module belongs to. |

## Sensor Control Registers

It is possible to configure which data is reported in the sensor control registers and how the data is reported.

| Register | Page | Description |
| :---: | :----: | --- |
|  2  |  0  | Control byte for sensor 0. |
|  3  |  0  | Control byte for sensor 1. |
|  4  |  0  | Control byte for sensor 2. |
|  5  |  0  | Control byte for sensor 3. |
|  6  |  0  | Control byte for sensor 4. |
|  7  |  0  | Control byte for sensor 5. |

### Description of control register bits

| Bit | Description |
| :--: | --- |
|  0,1  | Temperature `unit` to use <br />  **00** - Kelvin. <br /> **01** - Celsius (default). <br />  **10** - Fahrenheit. <br /> **11** - Reserved. |
|  2  | Reserved. |
|  3  | Set to one to enable `low alarm`. |
|  4  | Set to one to enable `high alarm`. |
|  5  | Send `**TurnOn/TurnOff` events instead of `Alarm` if set to one. |
|  6  | Controls when `**TurnOn/TurnOff` events will be sent. <br /><br /> **If set to zero**:<br />  **TurnOn** event is sent when low temperature is reached as set in `low temperature alarm register`.<br />  **TurnOff** event is sent when high temperature is reached as set in `high temperature alarm register`.<br /> <br />**If set to one**:<br />  **TurnOff** event is sent when low temperature is reached a temperature as set in `low temperature alarm register`.<br />  **TurnOn** event is sent when high temperature is reached as set in `high temperature alarm register`.<br /> <br /> The hysteresis value in the [`see sensor hysteresis registers`](./registers?id=sensor-hysteresis-registers) will effect `**TurnOn/TurnOff` events. The temperature must go above or below the hysteresis value before a new event will be sent out. |
|  7  | **If this bit is set** `Alarm events` (or TurnOff/TurnOn events) will be sent continuous with a one second interval until the alarm register is read or the temperature goes to a non alarm state (with hysteresis taken into account) [`see low alarm registers`](#low-alarm-registers). `TurnOn/TurnOff` events will not be affected by a cleared [alarm register (0x80)](https://grodansparadis.github.io/vscp-doc-spec/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) (alarm events will) and will be sent until this bit is cleared or the temperature goes to a non alarm state (with hysteresis taken into account). |

  * `ClASS1.ALARM, Alarm occured event` is documented [here](https://grodansparadis.github.io/vscp-doc-spec/#/./class1.alarm?id=type2).
  * `CLASS1.CONTROL, TurnOff event` is documented [here](https://grodansparadis.github.io/vscp-doc-spec/#/./class1.control?id=type6).
  * `CLASS1.CONTROL, TurnOn event` is documented [here](https://grodansparadis.github.io/vscp-doc-spec/#/./class1.control?id=type5).

## Temperature registers

| Register | Page | Description |
| :---: | :----: | --- |
|  8  |  0  | Temperature sensor 0 MSB (on board sensor). |
|  9  |  0  | Temperature sensor 0 LSB (on board sensor). |
|  10  |  0  | Temperature sensor 1 MSB. |
|  11  |  0  | Temperature sensor 1 LSB. |
|  12  |  0  | Temperature sensor 2 MSB. |
|  13  |  0  | Temperature sensor 2 LSB. |
|  14  |  0  | Temperature sensor 3 MSB. |
|  15  |  0  | Temperature sensor 3 LSB. |
|  16  |  0  | Temperature sensor 4 MSB. |
|  17  |  0  | Temperature sensor 4 LSB. |
|  18  |  0  | Temperature sensor 5 MSB. |
|  19  |  0  | Temperature sensor 5 LSB. |

All values stored as a twos complement number as temperature * 100.

## Report interval registers

| Register | Page | Description |
| :---: | :----: | --- |
|  20  |  0  | Report interval for sensor 0 in seconds (Set to zero for no report). |
|  21  |  0  | Report interval for sensor 1 in seconds (Set to zero for no report). |
|  22  |  0  | Report interval for sensor 2 in seconds (Set to zero for no report). |
|  23  |  0  | Report interval for sensor 3 in seconds (Set to zero for no report). |
|  24  |  0  | Report interval for sensor 4 in seconds (Set to zero for no report). |
|  25  |  0  | Report interval for sensor 5 in seconds (Set to zero for no report). |

## β constant registers

| Register | Page | Description |
| :---: | :----: | --- |
|  38  |  0  | B constant for sensor 0 MSB. |
|  39  |  0  | B constant for sensor 0 LSB. |
|  40  |  1  | B constant for sensor 1 MSB. |
|  41  |  1  | B constant for sensor 1 LSB. |
|  42  |  2  | B constant for sensor 2 MSB. |
|  43  |  2  | B constant for sensor 2 LSB. |
|  44  |  3  | B constant for sensor 3 MSB. |
|  45  |  3  | B constant for sensor 3 LSB. |
|  46  |  4  | B constant for sensor 4 MSB. |
|  47  |  4  | B constant for sensor 4 LSB. |
|  48  |  5  | B constant for sensor 5 MSB. |
|  49  |  5  | B constant for sensor 5 LSB. |

You find the B value for a specific NTC temperature sensor in it's datasheet. The correct B value set here is essential for the temperature calculations to be correct.

You can us [this web-page](http://www.thinksrs.com/downloads/programs/Therm%20Calc/NTCCalibrator/NTCcalculator.htm) for a 10K thermistor if you have a sensor with an unknown beta value. The tool is also useful if yuu want to calibrate your sensor over a sspecific temperature range.

## Low alarm registers

| Register | Page | Description |
| :---: | :----: | --- |
|  50  |  0  | Low alarm set point for sensor 0 MSB. |
|  51  |  0  | Low alarm set point for sensor 0 LSB. |
|  52  |  0  | Low alarm set point for sensor 1 MSB. |
|  53  |  0  | Low alarm set point for sensor 1 LSB. |
|  54  |  0  | Low alarm set point for sensor 2 MSB. |
|  55  |  0  | Low alarm set point for sensor 2 LSB. |
|  56  |  0  | Low alarm set point for sensor 3 MSB. |
|  57  |  0  | Low alarm set point for sensor 3 LSB. |
|  58  |  0  | Low alarm set point for sensor 4 MSB. |
|  59  |  0  | Low alarm set point for sensor 4 LSB. |
|  60  |  0  | Low alarm set point for sensor 5 MSB. |
|  61  |  0  | Low alarm set point for sensor 5 LSB. |

Writing any of these registers will reset high/low alarm conditions for that sensor.

The value is stored as a twos complement number representing the temperature. **Note** note that the value is not stored as temperature times 100 as for some other registers.

The hysteresis value affects the low alarm after a low alarm condition has been set. The temperature must increase with `hysteresis degrees` before the low alarm condition is resetted.

## High alarm registers

| Register | Page | Description |
| :---: | :----: | --- |
|  62  |  0  | High alarm set point for sensor 0 MSB. |
|  63  |  0  | High alarm set point for sensor 0 LSB. |
|  64  |  0  | High alarm set point for sensor 1 MSB. |
|  65  |  0  | High alarm set point for sensor 1 LSB. |
|  66  |  0  | High alarm set point for sensor 2 MSB. |
|  67  |  0  | High alarm set point for sensor 2 LSB. |
|  68  |  0  | High alarm set point for sensor 3 MSB. |
|  69  |  0  | High alarm set point for sensor 3 LSB. |
|  70  |  0  | High alarm set point for sensor 4 MSB. |
|  71  |  0  | High alarm set point for sensor 4 LSB. |
|  72  |  0  | High alarm set point for sensor 5 MSB. |
|  73  |  0  | High alarm set point for sensor 5 LSB. |

Writing any of these registers will reset high/low alarm conditions for that sensor.

The value is stored as a twos complement number representing the temperature. **Note** note that the value is not stored as temperature times 100 as for some other registers.

The hysteresis value affects the high alarm after a high alarm condition has been set. The temperature must decrease with `hysteresis degrees` before the high alarm condition is resetted.

## Sensor zone information registers

Zone and subzone is used to identify the sensor that originated an event. For measurements the [senoridex](https://grodansparadis.github.io/vscp-doc-spec/#/./vscp_measurements?id=datacoding) is used to identify the sensor. The zone and subzone can also be used to identify the location of the sensor.

| Register | Page | Description |
| :---: | :--: | --- |
|  74  |  0  | Zone for sensor 0 alarms. |
|  75  |  0  | Sub zone for sensor 0 alarms. |
|  76  |  0  | Zone for sensor 1 alarms. |
|  77  |  0  | Sub zone for sensor 1 alarms. |
|  78  |  0  | Zone for sensor 2 alarms. |
|  79  |  0  | Sub zone for sensor 2 alarms. |
|  80  |  0  | Zone for sensor 3 alarms. |
|  81  |  0  | Sub zone for sensor 3 alarms. |
|  82  |  0  | Zone for sensor 4 alarms. |
|  83  |  0  | Sub zone for sensor 4 alarms. |
|  84  |  0  | Zone for sensor 5 alarms. |
|  85  |  0  | Sub zone for sensor 5 alarms. |

## Sensor absolute low temperature registers

| Register | Page | Description |
| :---: | :--: | --- |
|  86  |  0  | Absolute low for sensor 0 MSB (Write to reset). |
|  87  |  0  | Absolute low for sensor 0 LSB (Write to reset). |
|  88  |  0  | Absolute low for sensor 1 MSB (Write to reset). |
|  89  |  0  | Absolute low for sensor 1 LSB (Write to reset). |
|  90  |  0  | Absolute low for sensor 2 MSB (Write to reset). |
|  91  |  0  | Absolute low for sensor 2 LSB (Write to reset). |
|  92  |  0  | Absolute low for sensor 3 MSB (Write to reset). |
|  93  |  0  | Absolute low for sensor 3 LSB (Write to reset). |
|  94  |  0  | Absolute low for sensor 4 MSB (Write to reset). |
|  95  |  0  | Absolute low for sensor 4 LSB (Write to reset). |
|  96  |  0  | Absolute low for sensor 5 MSB (Write to reset). |
|  97  |  0  | Absolute low for sensor 5 LSB (Write to reset). |

The value is stored as a twos complement number as temperature * 100.  Writing any of the registers will reset the value.

## Sensor absolute high temperature registers

| Register | Page | Description |
| :---: | :--: | --- |
|  98  |  0  | Absolute high for sensor 0 MSB (Write to reset). |
|  99  |  0  | Absolute high for sensor 0 LSB (Write to reset). |
|  100  |  0  | Absolute high for sensor 1 MSB (Write to reset). |
|  101  |  0  | Absolute high for sensor 1 LSB (Write to reset). |
|  102  |  0  | Absolute high for sensor 2 MSB (Write to reset). |
|  103  |  0  | Absolute high for sensor 2 LSB (Write to reset). |
|  104  |  0  | Absolute high for sensor 3 MSB (Write to reset). |
|  105  |  0  | Absolute high for sensor 3 LSB (Write to reset). |
|  106  |  0  | Absolute high for sensor 4 MSB (Write to reset). |
|  107  |  0  | Absolute high for sensor 4 LSB (Write to reset). |
|  108  |  0  | Absolute high for sensor 5 MSB (Write to reset). |
|  109  |  0  | Absolute high for sensor 5 LSB (Write to reset). |

The value is stored as a twos complement number as temperature * 100.  Writing any of the registers will reset the stored value.

## Sensor hysteresis registers

| Register | Page | Description |
| :---: | :--: | --- |
|  110  |  0  | Hysteresis in degrees Celsius for sensor 0 (default is 5 degrees). |
|  111  |  0  | Hysteresis in degrees Celsius for sensor 1 (default is 5 degrees). |
|  112  |  0  | Hysteresis in degrees Celsius for sensor 2 (default is 5 degrees). |
|  113  |  0  | Hysteresis in degrees Celsius for sensor 3 (default is 5 degrees). |
|  114  |  0  | Hysteresis in degrees Celsius for sensor 4 (default is 5 degrees). |
|  115  |  0  | Hysteresis in degrees Celsius for sensor 5 (default is 5 degrees). |

The value here will affect the high and low alarms

### Voltage calibration registers

The Voltage used to calculate the temperature for a sensor have effect on the error. The voltage is theoretically 5V but will in reality be something else but still close to 5V. These register can be used to set a calibrated voltage obtained from actual measurements. The value stored in the two registers is the voltage times 10000 so 5V for example should be stored as 50000.

| Register | Page | Description |
| :---: | :--: | --- |
|  118  |  0  | MSB of Voltage (Default is 0xC3). |
|  119  |  0  | MSB of Voltage (Default is 0x50). |

# Register page 1

## Raw A/D values

Raw A/D values from the temperature sensor network can be read if it is a need for that. This can be useful for special nonstandard setups. The A/D converter is a 10-bit converter so the value can be 0-1023 and is stored MSB first in the registers (not in the converter itself though) as all values are stored in VSCP. The registers can only be read, a write is ignored.

| Register | Page | Description |
| :---: | :--: | --- |
|  72  |  1  | MSB of A/D converter value for sensor 0. |
|  73  |  1  | LSB of A/D converter value for sensor 0. |
|  74  |  1  | MSB of A/D converter value for sensor 1. |
|  75  |  1  | LSB of A/D converter value for sensor 1. |
|  76  |  1  | MSB of A/D converter value for sensor 2. |
|  77  |  1  | LSB of A/D converter value for sensor 2. |
|  78  |  1  | MSB of A/D converter value for sensor 3. |
|  79  |  1  | LSB of A/D converter value for sensor 3. |
|  80  |  1  | MSB of A/D converter value for sensor 4. |
|  81  |  1  | LSB of A/D converter value for sensor 4. |
|  82  |  1  | MSB of A/D converter value for sensor 5. |
|  83  |  1  | LSB of A/D converter value for sensor 5. |

## Sensor calibration registers

The value in the calibration register is added to the measured sensor value before it's reported. The calibration value is stored as a two's complement temperature * 100 to allow for both positive and negative numbers. So 24.23 degrees is stored as 2423 and so on. This means that 100 will add one degree to the measured value while 65436 (0xFF9c) is -100 and will subtract one degree form the measured value. If you are unsecure on how two complement numbers work there is a guide [here](https://www.cs.cornell.edu/~tomf/notes/cps104/twoscomp.html)

| Register | Page | Description |
| :---: | :--: | --- |
|  84  |  1  | MSB of calibration value for sensor 0. |
|  85  |  1  | LSB of calibration value for sensor 0. |
|  86  |  1  | MSB of calibration value for sensor 1. |
|  87  |  1  | LSB of calibration value for sensor 1. |
|  88  |  1  | MSB of calibration value for sensor 2. |
|  89  |  1  | LSB of calibration value for sensor 2. |
|  90  |  1  | MSB of calibration value for sensor 3. |
|  91  |  1  | LSB of calibration value for sensor 3. |
|  92  |  1  | MSB of calibration value for sensor 4. |
|  93  |  1  | LSB of calibration value for sensor 4. |
|  94  |  1  | MSB of calibration value for sensor 5. |
|  95  |  1  | LSB of calibration value for sensor 5. |

[filename](./bottom-copyright.md ':include')

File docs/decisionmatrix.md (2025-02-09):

# Decision Matrix

The full functionality of the decision matrix is explained [in the
specification](https://grodansparadis.github.io/vscp-doc-spec/#/./vscp_decision_matrix).

Paris have a decision matrix consisting of eight entries. This matrix
can be used to control the relays. Possible actions are listed in the
table below.

| Action | Action code | Parameter | Description |
| --- | --- | --- | --- |
| **NOOP** | 0 (0x00) | Not used | No operation. Will do absolutely nothing.| 
| **ACTIVATE** | 1 (0x01) | Relays to activate (bit array) | Activate relay(s) given by argument. The argument is a bit array where bit 0 is relay 1 and so on. That is a position with a set bit will activate the corresponding relay. Byte 1 is Zone and byte 2 is sub-zone and must be equal to register content to trigger action. | 
| **DEACTICATE** | 2 (0x02) | Relays to deactivate (bit array) | Deactivate relay(s) given by argument. The argument is a bit array where bit 0 is relay 1 and so on. That is a position with a set bit will inactivate the corresponding relay. Byte 1 is Zone and byte 2 is sub-zone and must be equal to register content to trigger action.| 
| **PULSEON** | 3 (0x03) | Relays to pulse (bit array) | Pulse relay(s) given by argument. The argument is a bit array where bit 0 is relay 1 and so on. That is a position with a set bit will toggle the corresponding relay. Byte 1 is Zone and byte 2 is sub-zone and must be equal to register content to trigger action.| 
| |  4 (0x04) | | Reserved.| 
| | 5 (0x05) | | Reserved.| 
| |  6 (0x06) | | Reserved.| 
| | 7 (0x07) | | Reserved.| 
| | 8 (0x08) | | Reserved.| 
| | 9 (0x09) | | Reserved.| 
| **STATUS** | 10 (0x0a) | Relays to send status for (bit array) |  Send relay status. The argument is a bit array where bit 0 is relay 1 and so on. That is a position with a set bit will have a status event sent for the corresponding relay.| 
| | 11 (0x0b) | | Reserved.| 
| | 12 (0x0c) | | Reserved.| 
| | 13 (0x0d) | | Reserved.| 
| | 14 (0x0e) | | Reserved.| 
| | 15 (0x0f) | | Reserved.| 
| **DISABLE** | 16 (0x10)  | Relays to disable (bit array) | Disable relay(s) given by argument. The argument is a bit array where bit 0 is relay 1 and so on. That is a position with a set bit will disable the corresponding relay. Byte 1 is Zone and byte 2 is zone page and must be equal to register content to trigger action. | 

[filename](./bottom-copyright.md ':include')

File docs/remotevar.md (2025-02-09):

# Remote variables

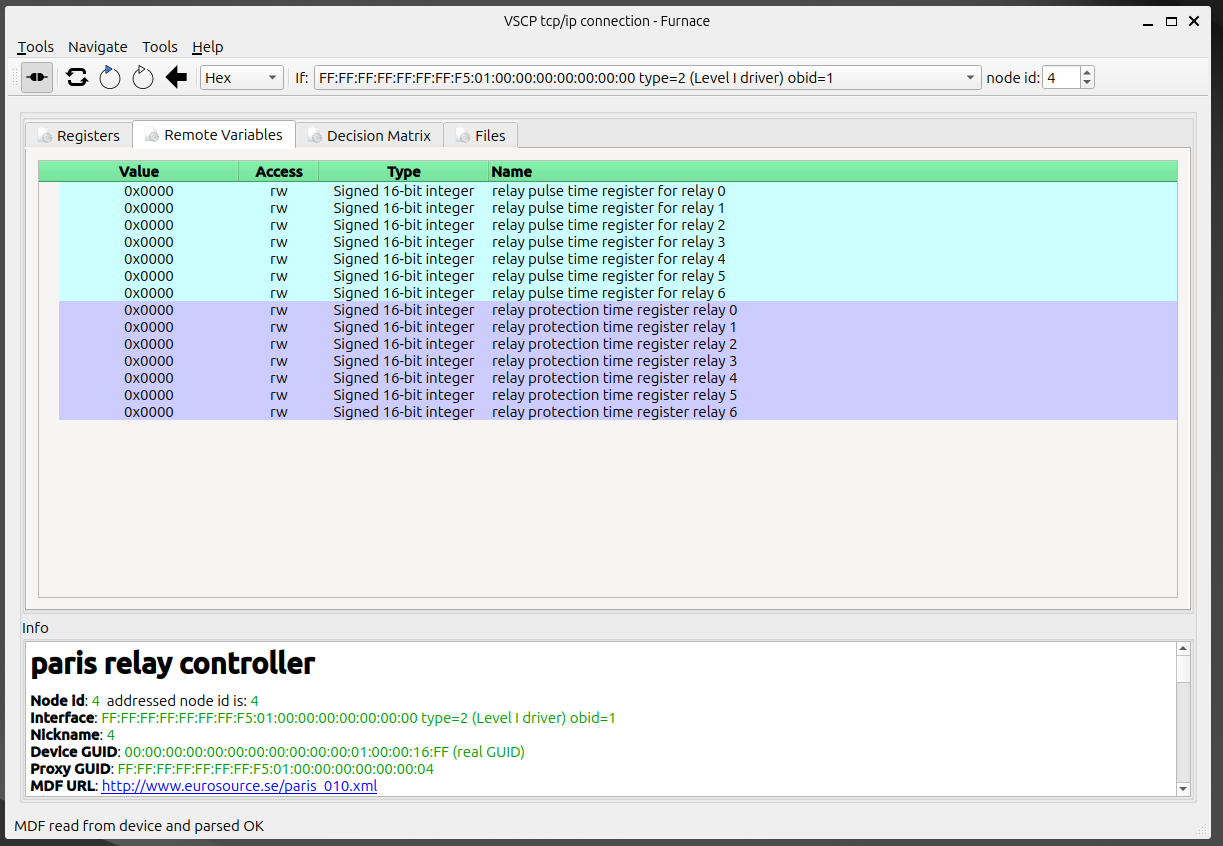
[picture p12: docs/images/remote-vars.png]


Remote variables are used - just as registers - to read and write data from a remote device.  The remote device can be a sensor, an actuator, or any other device that can be read from or written to. You can read mote about remote variables in the [VSCP specification](https://grodansparadis.github.io/vscp-doc-spec/#/./vscp_register_abstraction_model?id=remote-variables). Remote variables relay on registers bit present content in registers on a higher abstraction level.

The following remote variables are available for the Paris module:
| Variable | Access | Type | Note |
| --- | :---: | :----: | --- |
| relay pulse time register for relay 0 | r/w |  Signed 16-bit integer | Time in seconds. |
| relay pulse time register for relay 1 | r/w |  Signed 16-bit integer | Time in seconds. |
| relay pulse time register for relay 2 | r/w |  Signed 16-bit integer | Time in seconds. |
| relay pulse time register for relay 3 | r/w |  Signed 16-bit integer | Time in seconds. |
| relay pulse time register for relay 4 | r/w |  Signed 16-bit integer | Time in seconds. |
| relay pulse time register for relay 5 | r/w |  Signed 16-bit integer | Time in seconds. |
| relay pulse time register for relay 6 | r/w |  Signed 16-bit integer | Time in seconds. |
| relay protection time for relay 0 | r/w |  Signed 16-bit integer | Active relay will be turned off if not commanded to do so before time set here. Time in seconds. |
| relay protection time for relay 1 | r/w |  Signed 16-bit integer | Active relay will be turned off if not commanded to do so before time set here. Time in seconds.  |
| relay protection time for relay 2 | r/w |  Signed 16-bit integer | Active relay will be turned off if not commanded to do so before time set here. Time in seconds. |
| relay protection time for relay 3 | r/w |  Signed 16-bit integer | Active relay will be turned off if not commanded to do so before time set here. Time in seconds. |
| relay protection time for relay 4 | r/w |  Signed 16-bit integer | Active relay will be turned off if not commanded to do so before time set here. Time in seconds. |
| relay protection time for relay 5 | r/w |  Signed 16-bit integer | Active relay will be turned off if not commanded to do so before time set here. Time in seconds. |
| relay protection time for relay 6 | r/w |  Signed 16-bit integer | Active relay will be turned off if not commanded to do so before time set here. Time in seconds.|

[filename](./bottom-copyright.md ':include')

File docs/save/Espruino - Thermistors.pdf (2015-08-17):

## ESPRUINO

About (http://www.espruino.com/About)
Video (http://www.espruino.com/Video)
Blog (http://www.espruino.com/Blog)

Get it (http://www.espruino.com/Get+it)
Tutorials & Projects (http://www.espruino.com/Tutorials)
Code Examples (http://www.espruino.com/Code+Examples)
Reference (http://www.espruino.com/Reference)
Search (http://www.espruino.com/Search)

FAQ (http://www.espruino.com/FAQ)
Forum (http://www.espruino.com/Forum)
Contact Us (http://www.espruino.com/Contact+Us)

Press (http://www.espruino.com/Press)

Sponsored by:

Like Share 146

Share:

Or follow us on (http://twitter.com/Espruino) or
for new s and
updates!

## THERMISTORS

This Tutorial assumes that you are able to enter code in Espruino. If you can't do that yet, please follow the steps on the Quick Start (http://www.espruino.com/Quick+Start) page.

## INTRODUCTION

One of the most useful parts of modern Microcontrollers is the analog input. On the STM32 chips that Espruino uses you have 12 bit analog inputs on some pins and I'll show you how to use these to w ork out the temperature using a Thermistor. (http://en.wikipedia.org/wiki/Thermistor)

Thermistors are relatively cheap electronic components. They have 2 w ires, and a resistance that changes depending on their Temperature. These are available as small components, but they are also used in virtually all cars in order to determine air pressure and w ater temperature and w hen used in cars they are packaged up in to strong, w eatherproof modules. I'll be using one of these that I got froma scrap heap.

There are several different types of thermistor, and their resistance varies in different w ays. Most manufacturers provide tables of values (linking temperature to resistance) but you can also w ork out temperature fromresistance using a formula called the Steinharthart (http://en.wikipedia.org/wiki/Thermistor#Steinhart.E2.80.93Hart_equation) equation.

To w ork out w hich type of thermistor you have, the first step is to measure the resistance of it, and guess w hat temperature it is currently at. Then simply search online for 'thermistor table' and figure out w hich thermistor type most closely matches (thermistor types are generally named by their resistance at 25 degrees C). It should be really obvious mine measured 6k Ohms at around 20 degrees C so it w as rated as a 5k Ohmthermistor at 25 degrees C.

Once you know that, search online for the equation, for instance "5k thermistor equation". For mine, I got the steinhart equation and coefficients:

W = log(R)
T = 1 / (A + B*W + C*W3)
A: 1.2874E-03
B: 2.3573E-04
C: 9.5052E-08

Note that T is in Kelvin, so w e have to subtract 273.15 fromit to get degrees C!

## WIRING UP

Disclaimer: This is not the most accurate w ay to w ire a thermistor up how ever it w orks, and is very simple!

Try and find a resistor that is roughly the same resistance as your thermistor's rating. I chose 5.6 kOhms as this is a standard value (and my thermistor is 5 kOhms).

Choose 3 pins next to each other, the middle one of the pins must be able to read analog values. Just type analogRead() in to Espruino to get a list of pins that support analog inputs. I'll be using an Olimexino, so amusing D0,D1 and D2 if you use different pins, change the names in the softw are below .

Then, connect the pins up as follow s:

Pin Name | Connection
C0 | One of the 2 thermistor w ires
C1 | The other thermistor w ire, AND one of the resistor's w ires
C2 | The other resistor w ire

We'll be making the first pin 0v, the third pin 3.3v (the chip's voltage), and reading the voltage off of the middle pin.

## SOFTWARE

Now our w iring is done, to the softw are! First off, w e'll make the tw o pins either side of the middle 0 and 3.3v volts respectively:

digitalWrite(C0, 0);
digitalWrite(C2, 0);

And w e can read off the voltage:

analogRead(C1)

This should display something a bit like 0.543 (it is a value betw een 0 and 1)

We can use this to w ork out the resistance in Ohms. Because w e have made a potential divider, the value w e expect is | V = Rt /
(Rt + Rr)(Where Rt is our thermistor's resistance, and Rr is our resistor's resistance). Fiddling around w ith the algebra gives | Rt

# Espruino

Thermistors

= Rr*V / (1-V).

So now , let's put this all into a function:

function getTemp() {
digitalWrite(C0,0); // set voltage either side digitalWrite(C2,1);
var val = analogRead(C1); // read voltage var ohms = 5600*val/(1-val); // work out ohms var A = 0.0012874; // Steinhart equation var B = 0.00023573;
var C = 0.000000095052;
var W = Math.log(ohms);
var temp = 1 / (A + W * (B+C * W*W)) 273.15; return temp; // and return the temperature
}

All you have to do now is type:

getTemp()

And the temperature in degrees C w ill be displayed!

So now , maybe you w ant to make a fan that comes on w hen it gets too hot. I w on't cover w iring up a fan here, so let's just light an LED up.

All w e'll do, is every second w e w ill check the temperature, and if it is above 25 degrees C (it is England here...) w e'll light the LED!

function checkTemp() {
var temp = getTemp();
digitalWrite(LED1, temp > 25); }
setInterval(checkTemp, 1000);

Sorted!

## EXTRA SOFTWARE

Maybe that's not enough... You might w ant to display the temperature on a display. For this, w e'll use the LCD Driver code fromthis w ebsite.

Just go to the LCD Driver page, and copy in the first section of code. See the documentation on the page for how to w ire up the LCD.

After that, initialise the LCD, and print some text to make sure it's w orking!

var lcd = new LCD(A4,A5,A0,A1,A2,A3);
lcd.print("Hello World");

Now , if that w orks, w e can print the temperature every second. Note that w e're just overw riting the function that w e made before:

function checkTemp() {
var temp = getTemp();
digitalWrite(LED1, temp > 25); lcd.clear();
lcd.print("Temp is "+temp);
}

But that's a bit small so let's add big numbers. Go back to the LCD Driver page, and copy and pase the code immediately under the title 'Big Number Library'.

We need to initialise it:

lcd.bigInit();

And now w e can modify our function to draw big characters. This time, w e can only draw the numbers 0-9, so w e need to use a bit of maths to extract these and then draw themone at a time. Finally, w e just print a decimal point and a 'degrees C' mark.

function checkTemp() {
var temp = getTemp();
digitalWrite(LED1, temp > 25);

lcd.clear();
lcd.bigNum(0, Math.floor(temp/10)%10); lcd.bigNum(3, Math.floor(temp)%10); lcd.bigNum(9, Math.floor(temp*10)%10); lcd.bigNum(12,Math.floor(temp*100)%10); lcd.setCursor(7,3);lcd.print("2"); lcd.setCursor(16,0);lcd.print("'C"); }

That's it!

Note, if you w ant to save this and have it start automatically, you need to initialise the LCD and set up the special characters needed for the large numbers. To do this, add:

function onInit() {
var lcd = new LCD(A4,A5,A0,A1,A2,A3); lcd.bigInit();
}

You can now type save(), and w hen the pow er goes off and back on, onInit w ill be called and the LCD w ill be initialised.

This page is autogenerated f rom GitHub. (https://github.com/espruino/EspruinoDocs/blob/master/tutorials/Thermistors.md) If y ou see any mistakes or hav e suggestions, please let us know. (https://github.com/espruino/EspruinoDocs/issues/new?title=./tutorials/Thermistors.md)

© 2012 Pur3 Ltd π (http://www.espruino.com/edit.php?page=Thermistors)

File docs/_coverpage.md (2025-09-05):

VSCP logo

# Manual for the Kelvin NTC10K module

Scroll down to view docs.

[Homepage](https://www.vscp.org)
[Docs](https://docs.vscp.org/)
[Get Started](./README)

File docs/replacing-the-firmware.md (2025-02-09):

New firmware is released from time to time for all our modules. We
expect this to be true also for the module as it is an active
project. The process of updating the firmware of the module is a simple
one. Just follow the steps outlined in the [VSCP Works
documentation](https://grodansparadis.github.io/vscp-works-qt/#/bootload_window).

## Where is the firmware?

Firmware is available in the Github repository
<https://github.com/grodansparadis/can4vscp_paris/releases> and the [MDF of the module](https://github.com/grodansparadis/can4vscp_paris/tree/master/mdf) contains a list of available firmware files and a pointer to there location. This file is loaded by the firmware updating software of VSCP Works+ and you can select the file you need from there.

### Device firmware code
The standard registers of a module contains a register that holds the firmware code for the module. This is a 16-bit value that can be read by the VSCP firmware update software. The value is a code for the specific hardware the board uses. Typically hardware has been changed and processors have been updated to later versions as time goes. The VSCP firmware update software can use this code to find the correct firmware for the module. It is **VERY** important that the correct firmware is used for the module. If the wrong firmware is used the module will not work as expected and may even be damaged. So make sure this code is the same as the code in the firmware file you use.

Older firmware files may not have this code in the standard registers as it is a pretty late addition to the standard. In that case you should use the latest firmware file for the module for the type of processor you have.

## Where is the source for the firmware?

You can find the latest source for the firmware
[here](https://github.com/grodansparadis/can4vscp_paris).

## Replacing/updating the bootloader on the module

If you need to update the bootloader on this module you can find firmware files for it [here](https://github.com/grodansparadis/vscp-pic1-bootloader/releases). Select the hex files for your board and use the bootloader application to update the bootloader. When the bootloader is loaded you can use [VSCP Works+](https://grodansparadis.github.io/vscp-works-qt/#/bootload_window) to update the application firmware of the module.

You will need a PICkit3 or similar programmer to update the bootloader.

[filename](./bottom-copyright.md ':include')

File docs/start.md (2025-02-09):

# Accra - General counter module

**Document reversion**: 1.0.0 2015-07-07

Copyright © 2000-2020 Åke Hedman, [Grodans Paradis
AB](http://www.grodansparadis.com),
\<[akhe@grodansparadis.com](akhe@grodansparadis.com)\>

Accra

This documentation is for the [Accra
module](http://www.grodansparadis.com/accra/accra.html). The module is
available for international purchase from the
[FrogShop](http://www.frogshop.se).

  - [Introduction](Introduction)
  - [Getting Started](Getting%20Started)
  - [Hardware](Hardware)
  - [CAN4VSCP cabling](CAN4VSCP%20cabling)
  - [Updating the firmware](Replacing%20the%20firmware)
  - [Registers](registers)
  - [Abstractions](Abstractions)
  - [Alarms](Alarms)
  - [Decision Matrix](decisionmatrix)
  - [Events](Events)
  - [Recipes](Recipes)
  - [faq](faq)

//**Disclaimer:** © 2011-2015 Grodans Paradis AB. All rights reserved.
Grodans Paradis AB®, logo and combinations thereof, are registered
trademarks of Grodans Paradis AB. Other terms and product names may be
trademarks of others. The information in this document is provided in
connection with Grodans Paradis AB products. No license, express or
implied or otherwise, to any intellectual property right is granted by
this document or in connection with the sale of Grodans Paradis AB
products. Neither the whole nor any part of the information contained in
or the product described in this document may be adapted or reproduced
in any material from except with the prior written permission of the
copyright holder. The product described in this document is subject to
continuous development and improvements. All particulars of the product
and its use contained in this document are given by Grodans Paradis AB
in good faith. However all warranties implied or expressed including but
not limited to implied warranties of merchantability or fitness for
purpose are excluded. This document is intended only to assist the
reader in the use of the product. Grodans Paradis AB. shall not be
liable for any loss or damage arising from the use of any information in
this document or any error or omission in such information or any
incorrect use of the product. //

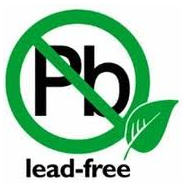
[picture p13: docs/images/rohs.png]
 All boards produced by Grodans Paradis AB are ROHS
compliant.

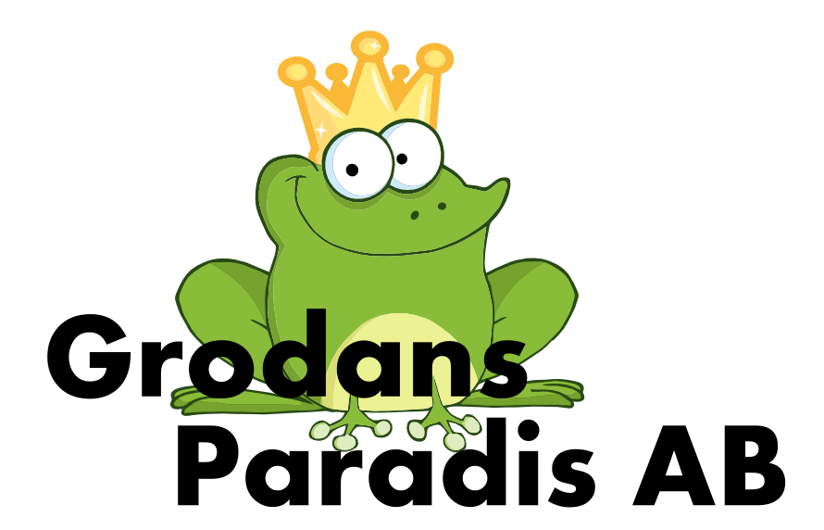
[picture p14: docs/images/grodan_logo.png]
\----   
<center> **Grodans Paradis AB** Brattbergavägen 17, 827 70 LOS SWEDEN  
**email:** [info@grodansparadis.com](info@grodansparadis.com) **phone:**
+46 (0)8 40011835  
**web:**<https://www.grodansparadis.com>  
</center>

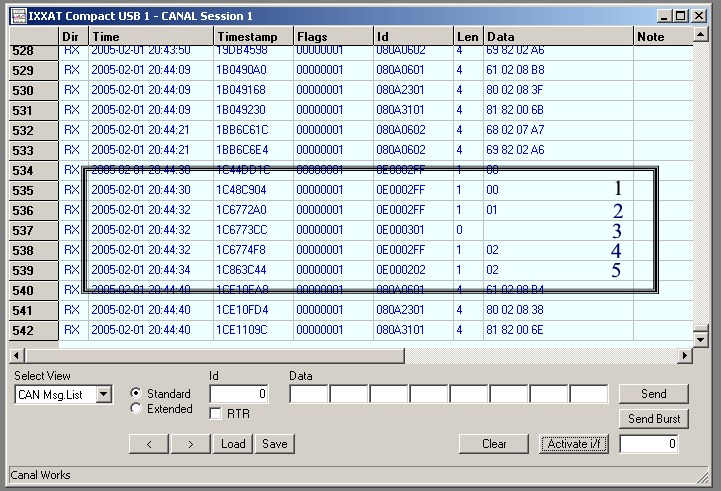
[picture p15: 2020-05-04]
docs/images/1_home_akhe_vscp_spec_images_nickname_seq.jpg

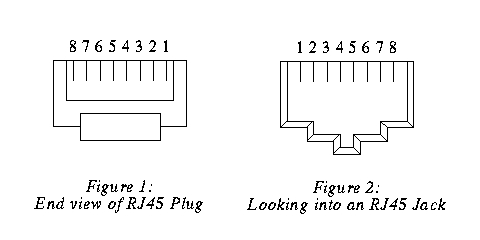
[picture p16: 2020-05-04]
docs/images/0_home_akhe_vscp_spec_images_rj45.jpg

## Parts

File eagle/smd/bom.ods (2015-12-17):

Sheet: eagle
Part | Value | Device | Package | Description | Description | Supplier | Partnumber | Price
C1 | 100uF | CPOL-EUD | PANASONIC_D | POLARIZED CAPACITOR, European symbol | Elektrolytkondensator | Digikey | PCE3951CT-ND | 5,04
C2 | 330uF | CPOL-EUD | PANASONIC_D | POLARIZED CAPACITOR, European symbol | Elektrolytkondensator | Digikey | PCE4164CT-ND | 4,4
C3 | 0.1uF | CNP-0805 | C0805 | NON-POLARIZED CAP | Avstörningskondensator | Bejoken | 522526 | 0,07
C4 | 15pF | C-EUC0805 | C0805 | CAPACITOR, European symbol | Kondensator | Bejoken | 522419 | 0,11
C5 | 0.1uF | C-EUC0805 | C0805 | CAPACITOR, European symbol | Avstörningskondensator | Bejoken | 522526 | 0,07
C6 | 15pF | C-EUC0805 | C0805 | CAPACITOR, European symbol | Kondensator | Bejoken | 522419 | 0,11
C7 | 0.1uF | C-EUC0805 | C0805 | CAPACITOR, European symbol | Avstörningskondensator | Bejoken | 522526 | 0,07
C8 | 10uF | C-EUC0805 | C0805 | CAPACITOR, European symbol
C9 | 10uF | C-EUC0805 | C0805 | CAPACITOR, European symbol
C10 | 10uF | C-EUC0805 | C0805 | CAPACITOR, European symbol
C11 | 10uF | C-EUC0805 | C0805 | CAPACITOR, European symbol
C12 | 10uF | C-EUC0805 | C0805 | CAPACITOR, European symbol
C13 | 10uF | C-EUC0805 | C0805 | CAPACITOR, European symbol
D1 | S1D | DIODE-SMB | SMB | DIODE | Protection diod | Digikey | 1N5819HW-FDICT-ND | 3,84
D2 | NUP2105L | DIODE-2CA|ACSOT23 | SOT23 | Dual DIODE Cathode-Anode|Anode-Cathode | Tansient protection | Digikey | NUP2105LT1GOSCT-ND | 4
1N5819 | S1D | DIODE-SMB | SMB | DIODE | Protection diod | Digikey | 1N5819HW-FDICT-ND | 3,84
LED1 |  | LEDCHIP-LED0805 | CHIP-LED0805 | LED | Green LED | Digikey | 475-1410-1-nd | 0,88
LED9 |  | LEDCHIP-LED0805 | CHIP-LED0805 | LED | Green LED | Digikey | 475-1410-1-nd | 0,88
IC1 | PIC18F2580 | PIC18LF252-I/SO | SO28 | 18F252, 28 pin, 32Kb prog, 1536 data, 256 EEPROM | Processor | Digikey | PIC18F2580-I/SO-ND | 15,77 | 100
IC3 | MCP2551SN | MCP2551SN | SO-08 | High Speed CAN tranceiver | CAN tranceiver | Digikey | MCP2551-I/SN-ND | 8,96
IC4 | LM2575S | LM2575S | TO263-5 | National Semiconductor 1.0A "Simple Switcher"(c) | Simpleswitcher | Digikey | LM2575S-3.3/NOPB-ND | 23,76
J1 | OSTTE-12 | OSTTE-12 | PINHEAD-12 |  | Terminal Block ' 12 | Digikey | ED2737-nd | 11,68
J2 | A00-108-220-450 | A00-108-220-450 | RJ-45 |  | RJ-45 connector | Digikey | 151-1099-nd | 5,6
J3 |  | MA06-1 | MA06-1 | PIN HEADER | Enkel stiftlist | Digikey | SAM1035-50-ND | 0,33
J4 |  | MA04-1 | MA04-1 | PIN HEADER | Enkel stiftlist | Digikey | SAM1035-50-ND | 0,33
L1 | 330 uH | DO3316P | DO3316P | COILCRAFT | Drossel 330u | Digikey | SRR1240-331KCT-ND | 7,3
Q1 | 10 MHz | HC-49S | 9C | Digikey 887-1050-1-nd | 10 MHz Crystal | Digikey | 887-1050-1-d | 4,24
R1 | 10K | R-EU_R0805 | R0805 | RESISTOR, European symbol | Resistor | Bejoken | 454676 | 0,01
R2 | 10K | R-EU_R0805 | R0805 | RESISTOR, European symbol | Resistor | Bejoken | 454676 | 0,01
R3 | 1K | R-EU_R0805 | R0805 | RESISTOR, European symbol | Resistor | Bejoken | 454650 | 0,01
R4 | 10K | R-EU_R0805 | R0805 | RESISTOR, European symbol | Resistor | Bejoken | 454676 | 0,01
R5 | 10K | R-EU_R0805 | R0805 | RESISTOR, European symbol | Resistor | Bejoken | 454676 | 0,01
R6 | 330 | R-EU_R0805 | R0805 | RESISTOR, European symbol | Resistor | Bejoken | 454636 | 0,01
R7 | 330 | R-EU_R0805 | R0805 | RESISTOR, European symbol | Resistor | Bejoken | 454636 | 0,01
R8 | 10K | R-EU_R0805 | R0805 | RESISTOR, European symbol | Resistor | Bejoken | 454676 | 0,01
R9 | 330 | R-EU_R0805 | R0805 | RESISTOR, European symbol | Resistor | Bejoken | 454636 | 0,01
R10 | 10K | R-EU_R0805 | R0805 | RESISTOR, European symbol | Resistor | Bejoken | 454676 | 0,01
R11 | 1K | R-EU_R0805 | R0805 | RESISTOR, European symbol | Resistor | Bejoken | 454650 | 0,01
R12 | 330 | R-EU_R0805 | R0805 | RESISTOR, European symbol | Resistor | Bejoken | 454636 | 0,01
R13 | 10K | R-EU_R0805 | R0805 | RESISTOR, European symbol | Resistor | Bejoken | 454676 | 0,01
R14 | 330 | R-EU_R0805 | R0805 | RESISTOR, European symbol | Resistor | Bejoken | 454636 | 0,01
R15 | 10K | R-EU_R0805 | R0805 | RESISTOR, European symbol | Resistor | Bejoken | 454676 | 0,01
R16 | 330 | R-EU_R0805 | R0805 | RESISTOR, European symbol | Resistor | Bejoken | 454636 | 0,01
S1 |  | 31-XX | B3F-31XX | OMRON SWITCH | Init switch | Elfa | 35-677-65 | 1,49 | 100
TERMISTOR | 10K | R-EU_R0805 | R0805 | RESISTOR, European symbol | Resistor | Bejoken | 454676 | 0,01
 |  |  |  |  |  |  |  | 102,94

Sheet: batch 1
Count | Part id's | Value | Package | Description | Supplier | supplier id | Price | Extended
1 | C1 | 100uF | PANASONIC_D | Capacitor | Digikey | PCE3951CT-ND | 0,87 kr | 0,87 kr | 900 minsta beställning
1 | C2 | 330uF | PANASONIC_D | Capacitor | Digikey | PCE4164TR-ND | 0,99 kr | 0,99 kr | 900 minsta beställning
3 | C3,C5,C7 | 100nF | C0805 | Capacitor | Bejoken | 522526 | 0,07 kr | 0,21 kr | 276,56 kr för rulle om 4000
2 | C4,C6 | 15pF | C0805 | Capacitor | Bejoken | 522419 | 0,11 kr | 0,22 kr | 447,76 för rulle om 4000
6 | C8,C9,C10,C11,C12,C13 | 10uF | C0805 | Capacitor | Digikey | ocksp | 0,18 kr | 1,07 kr | 357,1 kr för rulle om 2000
8 | R1,R2,R4,R5,R8,R10,R13,R15 | 10K | R0805 | Resistor | Bejoken | 454676 | 0,01 kr | 0,10 kr | 65,16 kr för rulle om 5000
2 | R3,R11 | 1K | R0805 | Resistor | Bejoken | 454650 | 0,01 kr | 0,03 kr | 65,16 kr för rulle om 5000
6 | R6,R7,R9,R12,R14,R16 | 330 | R0805 | Resistor | Bejoken | 454636 | 0,01 kr | 0,08 kr | 65,16 kr för rulle om 5000
1 | R17 | 120 | R0805 | Resistor | Bejoken | 454626 | 0,01 kr | 0,01 kr | 65,16 kr för rulle om 5000
1 | TERMISTOR | 10K | R0805 | Thermistor | Digikey | 490-2456-2-ND | 0,69 kr | 0,69 kr | 2.749,68 kr i rulle om 4000
2 | D1,D3 | 1N5819 | SMB | Diod | Digikey | 1N5819HW-FDICT-ND | 0,59 kr | 1,17 kr | 1.758,35 i rulle om 3000
1 | D2 | NUP2105L | SOT23 | Diod | Digikey | NUP2105LT1GOSTR-ND | 1,01 kr | 1,01 kr | 3.039,12 kr i rulle om 3000
1 | LED1 | Green LED | L0805 | LED | Digikey | 475-1410-1-nd | 0,52 kr | 0,52 kr | 2.061,10 kr i rulle om 4000
1 | LED2 | Red LED | L0805 | LED | Digikey | 475-1415-1-ND | 0,52 kr | 0,52 kr | 2.061,10 kr i rulle om 4000
1 | IC1 | PIC18F25K80 | SO28 | Microprocessor | Digikey | PIC18F25K80-I/SS-ND | 15,77 kr | 15,77 kr | 1577,45 för 100 st
1 | IC3 | MCP2551SN | SO-08 | CAN Tranceiver | Digikey | MCP2551-I/SN-ND | 6,21 kr | 6,21 kr | 18.625,54 för 3000 enheter
1 | IC4 | LM2575S | TO263-5 | Swicth regulator 5V | Digikey | LM2575S-3.3/NOPB-ND | 9,13 kr | 9,13 kr | 9.128,21 kr för 1000 enheter
1 | Q1 | 10 Mhz HC-49S | HC-49S/9C | Kristall 10MHz | Digikey | 887-1050-1-ND | 1,42 kr | 1,42 kr | 1.418,26 kr i rulle om 1000
1 | L1 | 330 uH | DO3316P | Inductance | Digikey | SRR1240-331KCT-ND | 3,36 kr | 3,36 kr | 2.691,79 i rullar om 800
1 | S1 | 31-XX | B3F-31XX | Omron Switch | Digikey | 35-677-65 | 1,49 kr | 1,49 kr
1 | J1 | OSTTE-12 | PINHEAD-12 | TERMINAL BLOCK 3.5MM 12POS PCB | Digikey | ED2737-nd | 6,46 kr | 6,46 kr
1 | J2 | A00-108-220-450 | A00-108-220-450 | RJ-45 connector (ej vinklad) | Digikey | 151-1099-ND | 3,93 kr | 3,93 kr
1 | J3 | MA06-1 | MA06-1 | Stiftlist 6 positioner | Digikey | SAM1035-50-ND | 0,97 kr | 0,97 kr | 8.056,17 kr för 50 pos i tusental
1 | J4 | MA04-1 | MA04-1 | Stiftlist 4 positioner | Digikey | SAM1035-50-ND | 0,64 kr | 0,64 kr
1 | Kretskort |  |  |  |  | PCB-CART | 4,82 kr | 4,82 kr
1 | C14 | 1uF
 |  |  |  |  |  |  |  | 0
 |  |  |  |  |  |  |  | 0
 |  |  |  |  |  |  |  | 0
 |  |  |  |  |  |  |  | 61,70 kr

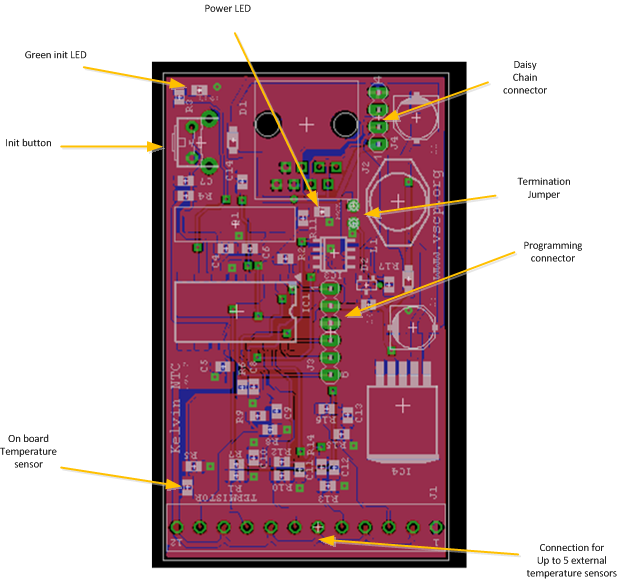
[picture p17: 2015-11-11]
docs/images/kelvin_components.png

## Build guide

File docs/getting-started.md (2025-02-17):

You need

  * RJ-45 patch cables or similar.
  * A stable +9V - +28V DC power source.
  * A host computer with a serial or USB interface.

The Kelvin module is powered from the CAN4VSCP bus. [This
article](https://github.com/grodansparadis/vscp/wiki/Connecting-CAN4VSCP-devices-together)
have information on how the bus is powered and set up. Follow it for a
reliable setup. Don't forget the 120 ohm terminators at each end of the
bus. `They are important` You can
activate the on board terminator on the Paris module if it is located at
one end of your bus.

When you power the module by inserting the RJ-45 cable the red LED on
the board should light up to indicate it is powered. This is just a
power indicator LED. When you power the board for the first time the
green led starts to blink to indicate that the module search for a
nickname. During normal operation this LED should light steady.

Remember that there should be `at least two` CAN4VSCP (or other CAN device set to 125kbps) devices (one additional). If you use the [Frankfurt RS-232](https://grodansparadis.github.io/can4vscp-frankfurt-rs232) or some other bus interface one additional module is needed. A single device can't talk by itself on a bus. It's an error.

# Connecting temperature sensor(s)

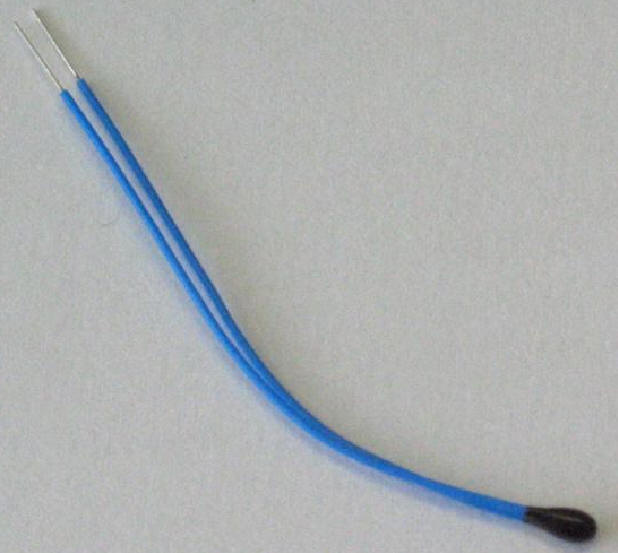
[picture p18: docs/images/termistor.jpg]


To just test that communication works you don't need to install any external temperature sensors. You can work with the internal sensor. By default it will send the board temperature in degrees Celsius every 30 seconds. You can view VSCP traffic on the CAN4VSCP bus with all CAN tools set to 125kbit/s but (VSCP Works+)(https://grodansparadis.github.io/vscp-works-qt/#/) makes handling, configuring, diagnosing VSCP stuff a lot more easy. So this may be the time to get to know this piece of software that works on both Linux and Window.

The internal temperature sensor does not show the room temperature, it is heated by the processor and other things on the PCB so it will always give a bit of a high value. You can calibrate away this error if you want. See the [configuration section](./configure.md).

Eventually you probably want to connect external temperature sensors to the module. You can connect any 10 Kohm NTC temperature sensor (thermistor) to the Kelvin NTC10K module. It helps if you know the β value of it for the temperature range you want to work in. You can get sensors and sensors on cables of different length from most electronics suppliers.

A maximum of five external NTC sensor can be connected to the Kelvin NTC10KA module. It is recommended to use NTC thermistors with 10K @ 25 °C types for best result. There are sensors available for all kinds of temperature measurement needs. As noted above you need the β constant value from the sensors datasheet or to be able to use it with the Kelvin NTC10KA module.You set this value in the [β-register for the sensor](./registers?id=%ce%b2-constant-registers).

The main advantage for a NTC sensor is that it is low cost and still is both fast and gives good readings. You can get it from anywhere and you can get it in any type and dimension. NTC resistor is also not sensitive to cable length. Using a CAT-5e cable (4 pairs with AWG 24) we will experience something like 9.38 ohms/100m which will not effect a 10K NTC thermistor that much.

Connect the thermistor to the Kelvin NTC10KA by connecting one end of it to +5VDC and the other end to one of the temperature inputs. A thermistor is not subject to polarity considerations so you can connect it in any way you want. You need to setup the β constant value for the sensor to get correct temperature measurements. The pinout for the terminal block is in the [hardware section](./hardware?id=terminal-block).

===== To measure temperature =====

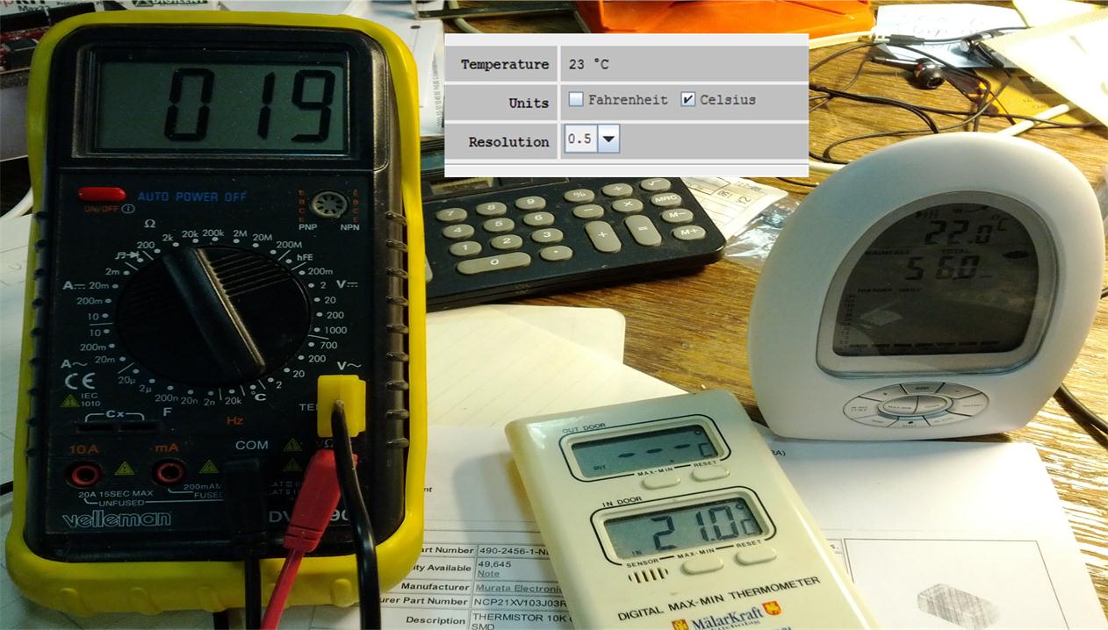
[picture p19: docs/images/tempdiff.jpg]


If you want to measure a temperature, for a room for example, you will soon realize that temperature measurements has more to it then just hook up a sensor and measure the temperature. Look at the picture above.

Each of the sensors shows a different temperature even when the sensor are on the same desk. If you walk around in the room things will be even more complex. Three sensors of the same type but on different height will show different results.

The readings from the sensors of the Kelvin NTC module is given with two decimals. Does that mean we have 0.01°C precision? Unfortunately not! The thermistor has error and the analog reading circuitry (ADC) has error.

We can approximate the expected error by first taking into account the thermistor resistance error. The thermistor is correct to 1%, which means that at 25°C it can read 10,100 to 9900 ohms. At around 25°C a difference of 450 ohms represents 1°C so 1% error means about +-0.25°C (you may be able to calibrate this away by determining the resistance of the thermistor in a 0°C ice bath and removing any offset). You can also go for a 0.1% thermistor which will reduce the possible resistance error down to +-0.03°C

Then there is the error of the ADC, for every bit that it is wrong the resistance (around 25°C) can be off by about 50 ohms. This isn't too bad, and is a smaller error than the thermistor error itself +-(0.1°C) but there is no way to calibrate it 'away' - just a higher precision ADC (12-16 bits instead of 10) will give you more precise readings

In general, we think thermistors are higher precision than thermocouples, or most low cost digital sensors, but you will not get better than +-0.1°C accuracy on it with a 1% thermistor and we would suggest assuming no better than +-0.5°C.

You will in addition to this notice that the on-board sensor (sensor 6) will show a temperature that is higher then what you should expect, The same is true if you connect a sensor directly to the board. This is due to the fact that the electronics on the board generate heat. This heat flows very well through the copper of the board giving faulty readings. The solution is to take away a degree or two from the reading.

[filename](./bottom-copyright.md ':include')

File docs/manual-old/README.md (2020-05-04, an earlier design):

# CAN4VSCP Kelvin NTC10K module

Document reversion: 2020-05-04
Copyright © 2000-2020 Grodans Paradis AB, <info@grodansparadis.com>

Kelvin NTC10K

This documentation is for the [Kelvin NTC10K module](https://www.grodansparadis.com/kelvinntc10k/kelvin_ntc10ka.html).

Disclaimer: © 2010-2020 Grodans Paradis AB. All rights reserved. Grodans Paradis AB®, logo and combinations thereof, are registered trademarks of Grodans Paradis AB. Other terms and product names may be trademarks of others. The information in this document is provided in connection with Grodans Paradis AB products. No license, express or implied or otherwise, to any intellectual property right is granted by this document or in connection with the sale of Grodans Paradis AB products. Neither the whole nor any part of the information contained in or the product described in this document may be adapted or reproduced in any material from except with the prior written permission of the copyright holder. The product described in this document is subject to continuous development and improvements. All particulars of the product and its use contained in this document are given by Grodans Paradis AB in good faith. However all warranties implied or expressed including but not limited to implied warranties of merchantability or fitness for purpose are excluded. This document is intended only to assist the reader in the use of the product. Grodans Paradis AB. shall not be liable for any loss or damage arising from the use of any information in this document or any error or omission in such information or any incorrect use of the product. 

# Introduction

Kelvin NTC10K

 Kelvin NTC10K is a temperature module that can handle six temperature sensing elements of which one is internal. The module can be attached to a standard DIN Rail or be mounted directly on a wall (ordered as separate versions).

The module fully adopts to the CAN4VSCP specification and can be powered directly over the bus with a 9-30V DC power source. It has a rich register set for configuration and any information events defined. It also have a decision matrix for easy dynamic event handling.

VSCP CAN modules are designed to work on a CAN4VSCP bus which use ordinary RJ-45 connectors and is powered with a 9 - 28VDC power source where power is provided over the communication cable. This means there is no need for a separate power cable. All that is needed is a CAT5 or better twisted pair cable. Buss length can be a maximum of 500 meters with drops of maximum 24 meters length (up to a total of 120 meters). As for all CAN4VSCP modules the communication speed is fixed at 125 kbps.

All VSCP modules contains information of there own setup, manual, hardware version, manufacturer etc. You just ask the module for the information you need and you will get it. When they are started up they have a default functionality that often is all that is needed to get a working setup. If the module have something to report it will send you an event and if it is setup to react on a certain type of event it will do it's work when you send event(s) to it.

The module comes with a GUID (global unique id) and is programmed with a bootloader and VSCP module functionality that works right out of the box.

You can control things with the module, such as intelligent relay control for heating and cooling that our Paris module have, or set channel individual high and low alarm levels to safely monitor temperatures, possibly in remote locations.

# Geting started

 You need

* RJ-45 patch cables or similar.
* A stable +9V - +28V DC power source.
* A host computer with a serial or USB interface.

The Kelvin NTC10K module is powered from the CAN4VSCP bus. This article have information on how the bus is powered and set up. Follow it for a reliable setup. Don't forget the two 120 ohm terminators at each end of the bus. They are important! You can activate the on board terminator on the module if it is located at one end of your bus (see the [hardware section](#Hardware)).

When you power the module by inserting the RJ-45 cable the red LED on the board should light up to indicate it is powered. This is just a power indicator LED. When you power the board for the first time the green led starts to blink to indicate that the module search for a nickname. During normal operation this LED should light steady.

Remember that there need to be at least two CAN4VSCP (or other CAN device set to 125kbps) devices (one additional if you have the [Frankfurt RS-232](http://www.grodansparadis.com/frankfurt/rs232/frankfurt-rs232.html)) on the bus to be able to communicate. A single device can't talk by itself on a bus. It's an error. 

Kelvin NTC10K

As an alternative to power the Kelvin NTC module from the CAN4VSCP bus you can power it over the daisy chain connector. The [CAN4VSCP Power Injector](http://www.grodansparadis.com/powerinjector/can4vscp_big/powerinjector.html) is needed (or similar) for this. 

## Installing the module

Connect the module to the CAN4VSCP bus. The red led led on the module should light up indicating that the device is powered. If this is the first time you start up the module the green lamp next to the initializing button will start to blink. This means that the module is trying to negotiate a nickname address with the rest of the modules on the bus. When it found a free nickname the green led will light steady. If the green led does not start to blink press the initialization button until it does. Now your module is ready to use.

If the green led never stops blinking you have a problem with your bus as the typically mean that the module dos not find any other module on the bus. Remember there must always be at least two active modules. Also check cables and that you have 120 ohm terminators installed on both ends of the bus.

When your module is installed it's time to configure it.

## Connecting temperature sensor(s)

Thermistor

To just test that communication works you don't need to install any external temperature sensors. You can work with the internal sensor. By default it will send the board temperature in degrees Celsius every 30 seconds. You can view VSCP traffic on the CAN4VSCP bus with all CAN tools set to 125kbit/s but VSCP Works makes handling, configuring, diagnosing VSCP stuff a lot more easy. So this may be the time to get to know this piece of software that works on both Linux and Window. 

The internal temperature sensor is heated by the processor and other things on the PCB so it will always give a bit of a high value. You can calibrate away this error if you want. See the [configuration section](#Configuration). 

 Eventually you probably want to connect external temperature sensors to the module. You can connect any 10 Kohm NTC temperature sensor to the Kelvin NTC10K module. It helps if you know the B value of it for the temperature range you want to work in. You can get sensors and sensors on cables of different length from the FrogShop.

Five external NTC sensor can be connected to the Kelvin NTC10KA module. It is recommended to use NTC thermistors with 10K @ 25 °C types for best result. There are sensors available for all kinds of temperature measurement needs. As noted above you need the B value from the sensors data sheet or to be able to use it with the Kelvin NTC10KA module.

The main advantage for a NTC sensor is that it is low cost. You can get it from anywhere and you can get it in any type and dimension. NTC resistor is also not sensitive to cable length. Using a CAT-5e cable (4 pairs with AWG 24) we will experience something like 9.38 ohms/100m which will not effect a 10K NTC thermistor that much.

Connect the thermistor to the Kelvin NTC10KA by connecting it to +5VDC and to one of the temperature inputs. A thermistor is not subject to polarity considerations so you can connect it in any way you want. You need to setup the B value for the sensor to get correct temperature measurements. The pin out for the terminal block is in the hardware section. 

## To measure temperature

Temperature measurements

 If you want to measure a temperature, for a room for example you will soon realize that temperature measurements has more to it then just hook up a sensor and measure the temperature. Look at the picture above.

Each of the sensors shows a different temperature even when the sensor are on the same desk. If you walk around in the room things will be even more complex. Three sensors of the same type but on different height will show different results.

The readings from the sensors of the Kelvin NTC module is given with two decimals. Does that mean we have 0.01°C precision? Unfortunately no! The thermistor has error and the analog reading circuitry (ADC) has error.

We can approximate the expected error by first taking into account the thermistor resistance error. The thermistor is correct to 1%, which means that at 25°C it can read 10,100 to 9900 ohms. At around 25°C a difference of 450 ohms represents 1°C so 1% error means about +-0.25°C (you may be able to calibrate this away by determining the resistance of the thermistor in a 0°C ice bath and removing any offset). You can also spring for a 0.1% thermistor which will reduce the possible resistance error down to +-0.03°C

Then there is the error of the ADC, for every bit that it is wrong the resistance (around 25°C) can be off by about 50 ohms. This isn't too bad, and is a smaller error than the thermistor error itself +-(0.1°C) but there is no way to calibrate it 'away' - just a higher precision ADC (12-16 bits instead of 10) will give you more precise readings

In general, we think thermistors are higher precision than thermocouples, or most low cost digital sensors, but you will not get better than +-0.1°C accuracy on with a 1% thermistor and we would suggest assuming no better than +-0.5°C.

You will in addition to this notice that the on-oard sensor will show a temperature that is higher then what you should expect, The same is if you connect a sensor directly to the board. This is due to the fact that the electronics on the board generate heat. This heat flows very well through the copper of the board giving faulty readings. The solution is to take away a degree or two from the reading. 

# Hardware

## Most current information
You can find the most current information about the Kelvin NTC10K module at
https://www.grodansparadis.com/products.html. On the site you can also find links to the latest firmware, drivers and schematics etc for its use. 

##   The raw facts
| Parameter | Value | 
| --- | ----- |
 | Current hardware reversion | B | 
 | Current firmware version | See [firmware release page](https///github.com/grodansparadis/can4vscp_kelvinntc10k/releases) | 
 | Supply voltage | +9-+28 VDC | 
 | PCB Size | 42mm x 72mm | 
 | Mounting | DIN or wall | 
 | Power requirements | 0.1W | 
 | Communication: CAN4VSCP (CAN) | 125 kbps | 
 | Number of sensors supported  | 6 | 

## Schematics

Schema for Kelvin NTC10K

Schematics: Rev B (click picture to enlarge) 

## Components

### Internal temperature sensor

The internal temperature sensor used on the Kelvin NTC10KA is the Murata [NCP21XV103J03RA](https///www.google.se/url?sa=t&rct=j&q=&esrc=s&source=web&cd=1&cad=rja&uact=8&ved=0ahUKEwiu-ujjlrnJAhWDjiwKHY9aCQQQFggiMAA&url=http%3A%2F%2Fwww.murata.com%2F~%2Fmedia%2Fwebrenewal%2Fsupport%2Flibrary%2Fcatalog%2Fproducts%2Fthermistor%2Fntc%2Fr44e.ashx&usg=AFQjCNE0U3R9tCH8Mm3JbRtiqhAN5yqOaQ&sig2=3Ga5yx9Fc6e15Gvr6YVbPg). Data for this sensor is as follows

 | Description | Value | 
 | ----------- | ----- | 
 | Time constant | 10 s | 
 | B[25/100]- value | 3944K | 
 | Temperature range | -40...+125ºC  | 
 | Resistance tolerance  | 5% | 
 | Resistance @ 25ºC | 10 Kohm | 
 | Max effect | 210 @ 25ºC mW | 
 | B[25/50]- value | 3900 | 
 | B[25/85]- value | 3934 | 
 | B[25/100]- value| 3944K 3% | 
 | Max error (B[25/100]) | 2.8 (%/C) | 





## Connectors



### Terminal block



 | Pin | Description  | 
 | --- | -----------  | 
 | 1   | Ground (GND) | 
 | 2   | I/O 9        | 
 | 3   | I/O 8        | 
 | 4   | I/O 7        | 
 | 5   | I/O 6        | 
 | 6   | I/O 5        | 
 | 7   | I/O 4        | 
 | 8   | I/O 3        | 
 | 9   | I/O 2        | 
 | 10  | I/O 1        | 
 | 11  | I/O 0        | 
 | 12  | +5V (VCC)    | 

### RJ-XX pin-out

The unit is powered over the CAN4VSCP bus. The CAN4VSCP normally uses CAT5 or better twisted pair cable. You can use other cables if you which. The important thing is that the CANH and CANL signals uses a twisted cable. For connectors you can use RJ10, RJ11, RJ12 or the most common RJ45 connectors.

Recommended connector is RJ-34/RJ-12 or RJ-11 with pin out as in this table.

 | Pin   | Use  | RJ-11 | RJ-12 | RJ-45 | Patch Cable wire color T568B | 
 | ---   | ---  | ----- | ----- | ----- | ---------------------------- | 
 | 1     | +9-28V DC |       |       | RJ-45 | Orange/White                 | 
 | 2 1   | +9-28V DC |       | RJ-12 | RJ-45 | Orange                       | 
 | 3 2 1 | +9-28V DC | RJ-11 | RJ-12 | RJ-45 | Green/White                  | 
 | 4 3 2 | CANH      | RJ-11 | RJ-12 | RJ-45 | Blue                         | 
 | 5 4 3 | CANL      | RJ-11 | RJ-12 | RJ-45 | Blue/White                   | 
 | 6 5 4 | GND       | RJ-11 | RJ-12 | RJ-45 | Green                        | 
 | 7 6   | GND       |       | RJ-12 | RJ-45 | Brown/White                  | 
 | 8     | GND       |       |       | RJ-45 | Brown                        | 

RJ-11/12/45 pin-out

**RJ-11/12/45 pin-out**

:!: Always use a pair of twisted wires for CANH/CANL for best noise immunity. If the EIA/TIA 56B standard is used this condition will be satisfied. This is good as most Ethernet networks already is wired this way. 

### Inter module connector

The inter module connector can be used to connect modules that are physically close to each other together in an easy way. Remember that the minimum length of a connection cable is 30 cm.

 | Pin | Description | 
 | --- | ----------- | 
 | 1   | Power from CAN4VSCP bus | 
 | 2   | CANH | 
 | 3   | CANL | 
 | 4   | GND  | 

Inter module connector

### PIC programming Connector

 | pin | Description | 
 | --- | ----------- | 
 | 1   | Reset       | 
 | 2   | VCC         | 
 | 3   | GND         | 
 | 4   | PGD (RX of second serial port is here to) | 
 | 5   | PGC (TX of second serial port is here to) | 
 | 6   | LWPGM  | 

Programming connector

### Functionality of the status LED

The LED is used to indicate the status of the module. It will light steady when the firmware is running and will blink when the module is in the nickname discovery process.

 | LED | Description | 
 | --- | ----------- | 
 | Steady  | No error. Firmware running. | 
 | Blinking | Module is going through the [nickname discovery process](http://www.vscp.org/docs/vscpspec/doku.php?id=vscp_level_i_specifics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). | 

### CAN

CAN4VSCP is a CAN based bus running at 125 kbps with the addition of DC power. If you are interested in how CAN works you have a pretty good intro [here](http://www.eeherald.com/section/design-guide/esmod9.html).

CAN is known to be robust and is there for used in vehicles and in the industry.

# Cabling

##   Cable length

CAN4VSCP always communicate with 125kbps. This means that if you use a good quality cable it can be up to a maximum of 500 meters using AWG24 or similar (CAT5) . Actual length depend on the environment and other parameters. Drops with a maximum length of 24 meters can be taken from this cable and the sum of all drops must not exceed a total of 120 meters. 

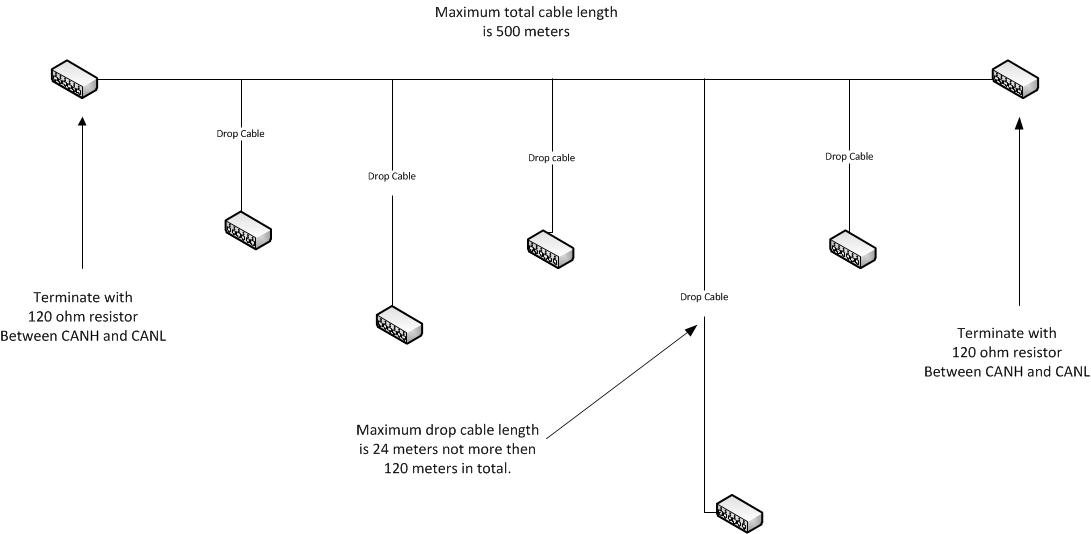
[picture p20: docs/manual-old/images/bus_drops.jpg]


CAN4VSCP bus with drops and terminations

## Termination

The CAN4VSCP bus, as all CAN based networks, should be terminated with a 120 ohms resistor between CANH and CANL at both ends of the cable. 

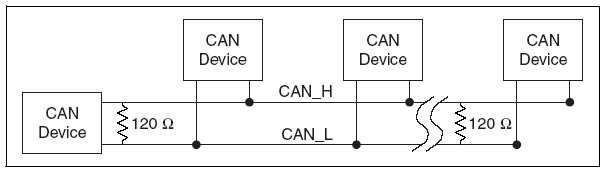
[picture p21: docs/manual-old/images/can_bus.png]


If you use CAT5 this termination should be placed between the blue - blue/white cables at both end of your bus.

On the board there is a jumper for an on-board terminator.

**Why is terminators required?**

Terminators are needed to cancel signal echos in the cable. In short you get less noise in the cable if you use them. It is recommended to use them even if at 125 kbit it is possible that your bus will work anyway as CAN is pretty forgiving at this transmission speed.

## Power the module

You normally power the module through the RJ45 connector over the CAN4VSCP bus. The voltage range is +9VDC - 28VDC.

It is possible to power the module on the TTL connector or to take power from this connector if power is available on the CAN4VSCP bus.  

## Best practice

Even if it is possible to have cable lengths up to 500 meters it is better to stay at shorter distances to have some margins. Here are some guidelines for a reliable set up

* Total cable length of 300m, stub cables count double their length in that total.

* Nodes count as 6m in that total. 

* Never less than 30cm of cable between nodes, nor between a stub connection and a node. 

* No more than 50 nodes connected.

Following this best practice you will have a setup that will work reliable even in harsh environments.

# Updating the firmware

New firmware is released from time to time for all our modules. We expect this to be true also for the Odessa module as it is an active project. The process of updating the firmware of the module is a simple one. Just follow the steps outlined in the [VSCP Works documentation](http://www.vscp.org/docs/vscpworks/doku.php?id=start).

## Where is the source for the firmware?

You can find the latest source for the firmware [here](https///github.com/grodansparadis/can4vscp_kelvin_ntc10k/releases). **You should use the relocated version of the firmware.**

## Step by step update process

Enter the bootloader in the menu



Select the interface the device is on





Select the nickname for the device to update firmware on. Make sure this is the correct id.  If this is the first time you update a node and only the bootloader is present use **0xfe**



On a node with working firmware the bootloader will be discovered automatically. If not select the algorithm (Microchip pic 1) for the device,



Load the firmware file using "local file". **You should use the relocated version of the firmware.**



Program the device





Due to a bug in VSCP Works restart VSCP works after the bootloader process is ready. 

Your device should now be available with the same id as you entered previously.

# Configure the module

You configure a VSCP module by writing content into the modules registers. You can do this manually or with the wizard available in VSCP works. Using the wizard is absolutely the easiest way to accomplish different things.

## Sensor calibration

Thermistors are very accurate but non linear devices. Still you may find that Kelvin NTC10K show you the wrong value of the measured temperature. This is because the sensor often need calibration or that registers need to be set to correct values. With calibration you can get very accurate results. For the best result you typically calibrate at three points, in ice + water mix, at 25 degrees Celsius and in boiling water. For most cases one calibration point will do but it all depends on what needs you have.

There is several registers that affect the reported temperature value. First of all there is the [Beta value registers](registers#%CE%B2_constant_registers). The value in these registers should be the Beta value for the sensor (and the range you use). Alternatively a value you get form calibration as of above.

The next value is the [voltage calibration value](registers#voltage_calibration_registers). This value is ten thousand times the voltage of the Kelvin NTC board. This is thus normally 50000 (for 5V) which is 0xC350 in hexadecimal. If the voltage of your board is not 5.00 volts you can enter the correct value here. This value seldom need a change.

The last and most important place are the  [sensor calibration registers](registers#sensor_calibration_registers) which can be used to set up a calibration value for each sensor that will be added or subtracted from the read value before it is reported. 

Values are stored as [twos complement numbers](https///www.cs.cornell.edu/~tomf/notes/cps104/twoscomp.html) and is as usual 100 times the actual value.

For example your sensor shows a temperature that is 1.4 degrees to low. 1.4 time 100 is 140 which is 0x008C in hexadecimal. So store 0x00 in the MSB byte and 0x8C in the LSB byte of the calibration value for that sensor. Now 1.4 degrees will be added to the measured value before it is reported and used in calculations.

Another sample is if your sensor measure a value that is 1.9 degrees to high. We therefore need to subtract 1.9. 100 * -1.9 = -190. This is  0xFF42 as a twos complement number  (190 =   0x00BE (0000 0000 1011 1110), Invert which give 0xFF41 (1111 1111 0100 0001), add one which gives 0cxFF42).



A good method to use to calibrate sensors is to mix ice and water and put the sensor in the mix. This will be zero degrees Celsius. To get another point boil some water and measure the temperature in the middle of the container without touching the walls.

A good tool for calibration is 

[http://www.thinksrs.com/downloads/programs/Therm%20Calc/NTCCalibrator/NTCcalculator.htm](http://www.thinksrs.com/downloads/programs/Therm%20Calc/NTCCalibrator/NTCcalculator.htm)

## Zones and sub zones

Zones and sub zones are used to group things together. Normally you don't address events to a certain receiver in VSCP ([CLASS1.PROTOCOL](http://www.vscp.org/docs/vscpspec/doku.php?id=class1.protocol) being the exception that prove this rule). Instead you report/send things to a group of modules defined by a zone and a sub zone. The sender have no knowledge of how many units this zone/sub zone consist of. Well it does not even care.

Zone and sub zone for the module can be set in register [0:0 (page:register) and register 0:1](http://www.grodansparadis.com/kelvinntc10k/manual/doku.php?id=registers#module_zone_registers). But more useful than the module zone sub zone is the zone information for each individual sensor that is available in register [0:74 - 0:85](http://www.grodansparadis.com/kelvinntc10k/manual/doku.php?id=registers#sensor_zone_information_registers). Here you can specify the zone/sub zone units you think is interested in this event. You can also set them both (or one of them) to 0xff meaning all zones or all sub zones.

Think of a zone as a house, floor plan or similar and sub-zone as a room or a location. Note again that this is not an address. It's just a way to group functionality together. Or let the MSB bits of the zone be the floor plan, the LSB bits of the zone be the room on that floor plan and the sub zone be a group of functionality for that room.

It is good to think this through before you start to configure a system with VSCP modules.

## β values

In registers [0:38 - 0:49](http://www.grodansparadis.com/kelvinntc10k/manual/doku.php?id=registers#%CE%B2_constant_registers) you have registers that hold β (beta) values for each sensor. To get correct temperature readings it is important that you enter the correct value here for the sensor you use. You find this information in the data sheet for the sensor.

## Sensor Control Registers

In registers [0:2 - 0:7](registers#description_of_control_register_bits) you can configure how sensor data is reported and acted up on. You can set the unit you want temperatures to be reported in. You can enable alarms. You can define that TurnOn/TurnOff events should be sent when levels have been reached or data has been found to be below a certain level. And other things. 

## Temperature measurements

If you have gone through the steps above you can now read temperature data in [registers 0:8 - 0:19](registers#temperature_registers). The temperature is shown in the selected unit as an integer which is temperature * 100. 

The temperature registers is located in pairs (Most significant byte followed my the least significant byte) and they can be read to get the current temperature for each sensor. The temperature is stored as a 16-bit two complement of a normalized temperature. This means you have to divide the read temperature by 100 to get the temperature value.

To get the temperature and calculate the temperature for a specific sensor.

 1.  Read MSB register. Read LSB register.
 2.  Calculate the 16-bit twos complement as MSB reading * 256 + LSB reading.
 3.  If the most significant bit is not set (Equal or less then 32767) this is a positive temperature. Divide by 100 and you have the temperature. 
 4.  If the most significant bit is set (Greater than 32767) this is a negative temperature. Now invert the result (the bits are inverted; 0 becomes 1, and 1 becomes 0) and add one to the result. Dive by 100 and you have the temperature.

However usually this is not the way to get temperature readings. Instead you set a report interval for a sensor expressed in seconds in [register 0:20 - 0:25](registers#report_interval_registers) (or set to zero to turn of reporting) and get temperature readings automatically delivered/reported.

After entering a value here [temperature events](events#temperature_event) will be sent with the configured interval. The receiver of this information can be another module, a routine that writes them to a database or a websocket widget that diagram them live on a screen or on a web page.

Some samples

* https://www.youtube.com/embed/37PQomplUVE`

* https://www.youtube.com/embed/L17d1SSyBc0`

* https://www.youtube.com/embed/qV41vWt5toE

## Alarms

In the [Low Alarm](registers#low_alarm_registers) and in the [High Alarm](registers#high_alarm_registers) registers you can set the level at which [alarm events](events#alarm_event) are sent.

An activated low alarm event (activated by setting bit 3 in the [control register](registers#description_of_control_register_bits)) is sent when the temperature is going below the low alarm value. When this happens the low alarm bit in the [standard alarm register](alarms) is set. This bit will only be rested by reading the alarm register. The alarm is considered active as long as the temperature is below the low alarm set point + the hysteresis value set in [register 0:110 - 0:115](registers#sensor_hysteresis_registers). So if temperature moves above this point a new alarm event will be sent again when temperature again is moving below the set point.

An activated high alarm event (activated by setting bit 4 in the [control register](registers#description_of_control_register_bits)) is sent when the temperature is going above the high alarm value. When this happens the high alarm bit in the [standard alarm register](alarms) is set. This bit will only be rested by reading the alarm register. The alarm is considered active as long as the temperature is above the low alarm set point - the hysteresis value set in [register 0:110 - 0:115](registers#sensor_hysteresis_registers). So if temperature moves below this point a new alarm event will be sent again when temperature again is moving above the set point.

It is possible to have continuous alarms events sent by setting bit 7 in the [control register](registers#description_of_control_register_bits). An alarm event will be sent every second while the alarm condition persist.

## Controlling things

Instead of alarms [CLASS1.CONTROL, Type=5, TurnOn events](http://www.vscp.org/docs/vscpspec/doku.php?id=class1.control#type_5_0x05_turnon) and [CLASS1.CONTROL, Type=6, TurnOn](http://www.vscp.org/docs/vscpspec/doku.php?id=class1.control#type_6_0x06_turnoff) events can be sent.  This functionality is activated by setting **bit 5** in the [control register](http://www.grodansparadis.com/kelvinntc10k/manual/doku.php?id=registers#description_of_control_register_bits). 

Another bit, bit 6, in the control register decides when the TurnOff/TurnOn events are sent. If set to zero TurnOff is sent when the high point is reached and TurnOn when the low point is reached. Suitable for control of a heating system for example. If the bit is set the TurnOn event is sent at the high set point and the TurnOff is sent on the low set point. Suitable for a cooling system.



The picture shows a real world example where a Kelvin NTC10K module measures temperature in a fridge which have its compressor controlled by a [Paris relay module](http://www.grodansparadis.com/paris/paris.html). The Paris [decision matrix](http://www.vscp.org/docs/vscpspec/doku.php?id=decision_matrix) is programmed to turn on the compressor when TurnOn events is received from the the zone/subzone programmed into the Kelvin NTC10K module sensor that measure the fridge temperature.

So here TurnOff events are sent by the Kelvin NTC10K module when the temperature go below -22 degrees Celsius. This event is received by the Paris module and it turn of the relay that controls the fridge compressor. Continuous mode is activated so the TurnOff events are sent until the temperature reach -20 degrees Celsius. A function to protect against events not being delivered.

When the temperature goes up above -20 degrees Celsius no events will be sent until the temperature go above -17 degrees Celsius. At this point TurnOn events will be sent which are received by the Paris module which turn on the relay that control the Fridge compressor. TurnOn events are sent continuously until the temperature go down to -19 degrees Celsius and again there will be a dead zone until the temperature falls to -22 degrees Celsius.

# Registers

All VSCP modules have a set of 8-bit registers defined to export it's functionality in a common way. Some of them (register 128-255) are predefined and the information in them are the same for all VSCP modules. See the [VSCP specification](http://www.vscp.org/docs/vscpspec/doku.php?id=register_abstraction_model) for a description of their content. 

The lower 128 register space is used for module specific registers. It is also here you find registers with which you configure your module. Also registers where you typically can read status information such as measurement data from the module is here.

The lower register space is further expanded in register pages.

Below is a description of the registers of the Kelvin NTC10KA module.

## Page 0

### Module zone registers

 | Register | Page | Description | 
 | -------- | ---- | ----------- | 
 | 0        | 0    | The zone this module belongs to. | 
 | 1        | 0    | The sub zone this module belongs to. | 

### Sensor Control Registers

Configure which data is reported here and how it is reported.

 | Register | Page | Description | 
 | -------- | ---- | ----------- | 
 | 2        | 0    | Control byte for sensor 0. | 
 | 3        | 0    | Control byte for sensor 1. | 
 | 4        | 0    | Control byte for sensor 2. | 
 | 5        | 0    | Control byte for sensor 3. | 
 | 6        | 0    | Control byte for sensor 4. | 
 | 7        | 0    | Control byte for sensor 5. | 

#### Description of control register bits

 | Bit | Description | 
 | --- | ----------- | 
 | 0,1 | Temperature unit \\ \\ **00** - Kelvin. \\ **01** - Celsius (default). \\  **10** - Fahrenheit. \\ **11** - Reserved. | 
 | 2   | Reserved. | 
 | 3   | Enable low alarm if set to one. | 
 | 4   | Enable high alarm if set to one. | 
 | 5   | Send **TurnOn/TurnOff** events instead of Alarm if set to one. | 
 | 6   | Controls when **TurnOn/TurnOff** events will be sent if activated. **0** - **TurnOn** event is sent when low temperature is reached as set in low temperature alarm register (see [sub:Low-alarm-registers]). **TurnOff** event is sent when high temperature is reached as set in high temperature alarm register (see [sub:High-alarm-registers]). **1** - **TurnOff** event is sent when low temperature is reached as set in low temperature alarm register (see [Registers]([registers)]). **TurnOn** event is sent when high temperature is reached as set in high temperature alarm register (see [sub:High-alarm-registers]). The hysteresis value (see [sub:Sensor-hysteresis-registers]) will effect **TurnOn/TurnOff** events The temperature must go above or below the hysteresis value before a new event will be sent out. | 
 | 7   | If this bit is set Alarm events will be sent continuous with a one second interval until the alarm register is read or the temperature goes to a non alarm state (with hysteresis taken into account see [[sub:Low-temperature-alarm]). **TurnOn/TurnOff** events will not be affected by a cleared alarm register and will be sent until this bit is cleared or the temperature goes to a non alarm state (with hysteresis taken into account. | 

###  Temperature registers

 | Register | Page | Description | 
 | -------- | ---- | -----------  | 
 | 8        | 0    | Temperature sensor 0 MSB (on board sensor). | 
 | 9        | 0    | Temperature sensor 0 LSB (on board sensor). | 
 | 10       | 0    | Temperature sensor 1 MSB.                   | 
 | 11       | 0    | Temperature sensor 1 LSB.                   | 
 | 12       | 0    | Temperature sensor 2 MSB.                   | 
 | 13       | 0    | Temperature sensor 2 LSB.                   | 
 | 14       | 0    | Temperature sensor 3 MSB.                   | 
 | 15       | 0    | Temperature sensor 3 LSB.                   | 
 | 16       | 0    | Temperature sensor 4 MSB.                   | 
 | 17       | 0    | Temperature sensor 4 LSB.                   | 
 | 18       | 0    | Temperature sensor 5 MSB.                   | 
 | 19       | 0    | Temperature sensor 5 LSB.                   | 

All values stored as a twos complement number as temperature * 100.

###  Report interval registers

 | Register | Page | Description | 
 | -------- | ---- | ----------- | 
 | 20       | 0    | Report interval for sensor 0 in seconds (Set to zero for no report). | 
 | 21       | 0    | Report interval for sensor 1 in seconds (Set to zero for no report). | 
 | 22       | 0    | Report interval for sensor 2 in seconds (Set to zero for no report). | 
 | 23       | 0    | Report interval for sensor 3 in seconds (Set to zero for no report). | 
 | 24       | 0    | Report interval for sensor 4 in seconds (Set to zero for no report). | 
 | 25       | 0    | Report interval for sensor 5 in seconds (Set to zero for no report). | 

###  β constant registers

 | Register | Page | Description | 
 | -------- | ---- | ----------- | 
 | 38       | 0    | B constant for sensor 0 MSB. | 
 | 39       | 0    | B constant for sensor 0 LSB. | 
 | 40       | 1    | B constant for sensor 1 MSB. | 
 | 41       | 1    | B constant for sensor 1 LSB. | 
 | 42       | 2    | B constant for sensor 2 MSB. | 
 | 43       | 2    | B constant for sensor 2 LSB. | 
 | 44       | 3    | B constant for sensor 3 MSB. | 
 | 45       | 3    | B constant for sensor 3 LSB. | 
 | 46       | 4    | B constant for sensor 4 MSB. | 
 | 47       | 4    | B constant for sensor 4 LSB. | 
 | 48       | 5    | B constant for sensor 5 MSB. | 
 | 49       | 5    | B constant for sensor 5 LSB. | 

You find the B value for a specific NTC temperature sensor in it's datasheet. The correct B value set here is essential for the temperature calculations to be correct.

You can us [this webpage](http://www.thinksrs.com/downloads/programs/Therm%20Calc/NTCCalibrator/NTCcalculator.htm) for a 10K thermistor with an unknown beta value.

###  Low alarm registers

 | Register | Page | Description | 
 | -------- | ---- | ----------- | 
 | 50       | 0    | Low alarm set point for sensor 0 MSB. | 
 | 51       | 0    | Low alarm set point for sensor 0 LSB. | 
 | 52       | 0    | Low alarm set point for sensor 1 MSB. | 
 | 53       | 0    | Low alarm set point for sensor 1 LSB. | 
 | 54       | 0    | Low alarm set point for sensor 2 MSB. | 
 | 55       | 0    | Low alarm set point for sensor 2 LSB. | 
 | 56       | 0    | Low alarm set point for sensor 3 MSB. | 
 | 57       | 0    | Low alarm set point for sensor 3 LSB. | 
 | 58       | 0    | Low alarm set point for sensor 4 MSB. | 
 | 59       | 0    | Low alarm set point for sensor 4 LSB. | 
 | 60       | 0    | Low alarm set point for sensor 5 MSB. | 
 | 61       | 0    | Low alarm set point for sensor 5 LSB. | 

Writing any of these registers will reset high/low alarm conditions for that sensor.

The value is stored as a twos complement number representing the temperature. **Note note that the value is not *100**.

The hysteresis value affects the low alarm after a low alarm condition has been set. The temperature must increase with *hysteresis* degrees before the low alarm condition is resetted.

###  High alarm registers

 | Register | Page | Description | 
 | -------- | ---- | ----------- | 
 | 62       | 0    | High alarm set point for sensor 0 MSB. | 
 | 63       | 0    | High alarm set point for sensor 0 LSB. | 
 | 64       | 0    | High alarm set point for sensor 1 MSB. | 
 | 65       | 0    | High alarm set point for sensor 1 LSB. | 
 | 66       | 0    | High alarm set point for sensor 2 MSB. | 
 | 67       | 0    | High alarm set point for sensor 2 LSB. | 
 | 68       | 0    | High alarm set point for sensor 3 MSB. | 
 | 69       | 0    | High alarm set point for sensor 3 LSB. | 
 | 70       | 0    | High alarm set point for sensor 4 MSB. | 
 | 71       | 0    | High alarm set point for sensor 4 LSB. | 
 | 72       | 0    | High alarm set point for sensor 5 MSB. | 
 | 73       | 0    | High alarm set point for sensor 5 LSB. | 

Writing any of these registers will reset high/low alarm conditions for that sensor.

The value is stored as a twos complement number representing the temperature. **Note note that the value is not *100**.

The hysteresis value affects the high alarm after a high alarm condition has been set. The temperature must decrease with *hysteresis* degrees before the high alarm condition is resetted.

###  Sensor zone information registers

 | Register | Page | Description | 
 | -------- | ---- | ----------- | 
 | 74       | 0    | Zone for sensor 0 alarms.     | 
 | 75       | 0    | Sub zone for sensor 0 alarms. | 
 | 76       | 0    | Zone for sensor 1 alarms.     | 
 | 77       | 0    | Sub zone for sensor 1 alarms. | 
 | 78       | 0    | Zone for sensor 2 alarms.     | 
 | 79       | 0    | Sub zone for sensor 2 alarms. | 
 | 80       | 0    | Zone for sensor 3 alarms.     | 
 | 81       | 0    | Sub zone for sensor 3 alarms. | 
 | 82       | 0    | Zone for sensor 4 alarms.     | 
 | 83       | 0    | Sub zone for sensor 4 alarms. | 
 | 84       | 0    | Zone for sensor 5 alarms.     | 
 | 85       | 0    | Sub zone for sensor 5 alarms. | 

###  Sensor absolute low temperature registers

 | Register | Page | Description | 
 | -------- | ---- | ----------- | 
 | 86       | 0    | Absolute low for sensor 0 MSB (Write to reset). | 
 | 87       | 0    | Absolute low for sensor 0 LSB (Write to reset). | 
 | 88       | 0    | Absolute low for sensor 1 MSB (Write to reset). | 
 | 89       | 0    | Absolute low for sensor 1 LSB (Write to reset). | 
 | 90       | 0    | Absolute low for sensor 2 MSB (Write to reset). | 
 | 91       | 0    | Absolute low for sensor 2 LSB (Write to reset). | 
 | 92       | 0    | Absolute low for sensor 3 MSB (Write to reset). | 
 | 93       | 0    | Absolute low for sensor 3 LSB (Write to reset). | 
 | 94       | 0    | Absolute low for sensor 4 MSB (Write to reset). | 
 | 95       | 0    | Absolute low for sensor 4 LSB (Write to reset). | 
 | 96       | 0    | Absolute low for sensor 5 MSB (Write to reset). | 
 | 97       | 0    | Absolute low for sensor 5 LSB (Write to reset). | 

The value is stored as a twos complement number as temperature * 100.  Writing any of the registers will rest the value.

###  Sensor absolute high temperature registers

 | Register | Page | Description | 
 | -------- | ---- | ----------- | 
 | 98       | 0    | Absolute high for sensor 0 MSB (Write to reset). | 
 | 99       | 0    | Absolute high for sensor 0 LSB (Write to reset). | 
 | 100      | 0    | Absolute high for sensor 1 MSB (Write to reset). | 
 | 101      | 0    | Absolute high for sensor 1 LSB (Write to reset). | 
 | 102      | 0    | Absolute high for sensor 2 MSB (Write to reset). | 
 | 103      | 0    | Absolute high for sensor 2 LSB (Write to reset). | 
 | 104      | 0    | Absolute high for sensor 3 MSB (Write to reset). | 
 | 105      | 0    | Absolute high for sensor 3 LSB (Write to reset). | 
 | 106      | 0    | Absolute high for sensor 4 MSB (Write to reset). | 
 | 107      | 0    | Absolute high for sensor 4 LSB (Write to reset). | 
 | 108      | 0    | Absolute high for sensor 5 MSB (Write to reset). | 
 | 109      | 0    | Absolute high for sensor 5 LSB (Write to reset). | 

The value is stored as a twos complement number as temperature * 100.  Writing any of the registers will rest the value.

###  Sensor hysteresis registers

 | Register | Page | Description | 
 | -------- | ---- | ----------- | 
 | 110      | 0    | Hysteresis in degrees Celsius for sensor 0 (default is 5 degrees). | 
 | 111      | 0    | Hysteresis in degrees Celsius for sensor 1 (default is 5 degrees). | 
 | 112      | 0    | Hysteresis in degrees Celsius for sensor 2 (default is 5 degrees). | 
 | 113      | 0    | Hysteresis in degrees Celsius for sensor 3 (default is 5 degrees). | 
 | 114      | 0    | Hysteresis in degrees Celsius for sensor 4 (default is 5 degrees). | 
 | 115      | 0    | Hysteresis in degrees Celsius for sensor 5 (default is 5 degrees). | 

The value here will affect the high and low alarms 
### Voltage calibration registers

The Voltage used to calculate the temperature for a sensor have effect on the error. The voltage is theoretically 5V but will in reality be something else but still close to 5V. These register can be used to set a calibrated voltage obtained from actual measurements. The value stored in the two registers is the voltage times 10000 so 5V for example should be stored as 50000.

 | Register | Page | Description | 
 | -------- | ---- | ----------- | 
 | 118      | 0    | MSB of Voltage (Default is 0xC3). | 
 | 119      | 0    | MSB of Voltage (Default is 0x50). | 

## Page 1

### Raw A/D values

Raw A/D values from the temperature sensor network can be read if a user wants to. This can be useful for special nonstandard setups. The A/D converter is a 10-bit converter so the value can be 0-1023 and is stored MSB first in the registers (not in the converter) as all values are stored in VSCP. The registers can only be read, a write is ignored.

 | Register | Page | Description | 
 | -------- | ---- | ----------- | 
 | 72       | 1    | MSB of A/D converter value for sensor 0. | 
 | 73       | 1    | LSB of A/D converter value for sensor 0. | 
 | 74       | 1    | MSB of A/D converter value for sensor 1. | 
 | 75       | 1    | LSB of A/D converter value for sensor 1. | 
 | 76       | 1    | MSB of A/D converter value for sensor 2. | 
 | 77       | 1    | LSB of A/D converter value for sensor 2. | 
 | 78       | 1    | MSB of A/D converter value for sensor 3. | 
 | 79       | 1    | LSB of A/D converter value for sensor 3. | 
 | 80       | 1    | MSB of A/D converter value for sensor 4. | 
 | 81       | 1    | LSB of A/D converter value for sensor 4. | 
 | 82       | 1    | MSB of A/D converter value for sensor 5. | 
 | 83       | 1    | LSB of A/D converter value for sensor 5. | 

###  Sensor calibration registers

The value in the calibration register is added to the measured sensor value before it's reported. The calibration value is stored as a two's complement temperature * 100 to allow for both positive and negative numbers. So 24.23 degrees is stored as 2423 and so on. This means that 100 will add one degree to the measured value while 65436 (0xFF9c) is -100 and will subtract one degree form the measured value. If you are unsecyre on how two complement umbers work there is an introduction here https://www.cs.cornell.edu/~tomf/notes/cps104/twoscomp.html

 | Register | Page | Description | 
 | -------- | ---- | ----------- | 
 | 84       | 1    | MSB of calibration value for sensor 0. | 
 | 85       | 1    | LSB of calibration value for sensor 0. | 
 | 86       | 1    | MSB of calibration value for sensor 1. | 
 | 87       | 1    | LSB of calibration value for sensor 1. | 
 | 88       | 1    | MSB of calibration value for sensor 2. | 
 | 89       | 1    | LSB of calibration value for sensor 2. | 
 | 90       | 1    | MSB of calibration value for sensor 3. | 
 | 91       | 1    | LSB of calibration value for sensor 3. | 
 | 92       | 1    | MSB of calibration value for sensor 4. | 
 | 93       | 1    | LSB of calibration value for sensor 4. | 
 | 94       | 1    | MSB of calibration value for sensor 5. | 
 | 95       | 1    | LSB of calibration value for sensor 5. | 

# Alarms

 | Bit | Description | 
 | --- | ----------- | 
 | 0   | Low Alarm from one or more sensor.  | 
 | 1   | High Alarm from one or more sensor. | 
 | 2   | Reserved.                           | 
 | 3   | Reserved                            | 
 | 4   | Reserved                            | 
 | 5   | Reserved                            | 
 | 6   | Reserved                            | 
 | 7   | Reserved                            | 

Remember that alarm bits are cleared when read. So read the register to clear alarm bits. Alarm bits will be set until this register is cleared even if the actual alarm condition is not active anymore.

# Decision Matrix

This module have no decision matrix.

# Events

Here the events sent by the module is described.

## Temperature Event

 | Event | Description | 
 | ----- | ----------- | 
 | [CLASS1.MEASUREMENT (10) Type=6, Temperature](http://www.vscp.org/docs/vscpspec/doku.php?id=class1.measurement#type_6_0x06_temperature) | If enabled this event is sent periodically for each sensor. The temperature is reported as a normalized integer value by this event. The event frequency is set in register 20-25 (default is one event per 30 seconds) and must be set to a non zero value for it to be sent.\\ \\ Temperature can be reported in one of three units. Kelvin, Celsius (default) or Fahrenheit as set in register 2-7. \\ \\ __**Data**__\\ **Byte 0** - Data coding byte. See description below.\\ **Byte 1** - Always 130 (0x82). Decimal point should be shifted two steps to the left = divide with hundred.\\ **Byte 2** - MSB of normalized integer. Two complement number.\\ **Byte 3** - LSB of normalized integer. Two complement number.\\ \\ | 

The data coding byte is the measurement data coding format described in [the VSCP specification](http://www.vscp.org/docs/vscpspec/doku.php?id=data_coding).

The normalized integer is stored as a two complement 16-bit integer. To convert

1. Calculate the 16-bit twos complement as MSB byte * 256 + LSB byte.

2. If the most significant bit is not set (Equal or less then 32767) this is a positive temperature. Divide by 100 and you have the temperature. 

3. If the most significant bit is set (Greater than 32767) this is a negative temperature. Now invert the result (the bits are inverted; 0 becomes 1, and 1 becomes 0) and add one to the result. Dive by 100 and you have the temperature.

### Example: A negative temperature in Celsius from sensor 1

The data part of the event will be

 | Byte   | Description | 
 | ----   | ----------- | 
 | Byte 0 | 130 (0x82)  | 
 | Byte 1 | 2 (0x02)    | 
 | Byte 2 | 255 (0xF0)  | 
 | Byte 3 | 216 (0x60)  | 

 1.  **Byte 0**: Normalized integer, Celsius, Sensor 1
 2.  **Byte 1**: Decimal point should be shifted two steps to the left.
 3.  **Byte 2/3**: Bit 16 is a one meaning it's a negative number. Temperature is a two complement number. 0xF060 = 0b1111000001100000. Invert which give 0b0000111110011111 add one which give 0b0000111110100000 = 4000. Divide by 100 gives 40.00 The read temperature is -40.00 ºC.

### Example: A positive temperature in Celsius from sensor 1

The data part of the event will be

 | Byte   | Description | 
 | ----   | ----------- | 
 | Byte 0 | 130 (0x82)  | 
 | Byte 1 | 2 (0x02)    | 
 | Byte 2 | 46 (0x2E)   | 
 | Byte 3 | 224 (0xE0)  | 

 1.  **Byte 0**: Normalized integer, Celsius, Sensor 1
 2.  **Byte 1**: Decimal point should be shifted two steps to the left.
 3.  **Byte 2/3**: Bit 16 is zero meaning it's a positive number. 0x2EE0 = 12000. Divide by 100 gives 120.00. The temperature is 120.00 ºC. 

### Example: A negative temperature in Fahrenheit from sensor 5

The data part of the event will be

 | Byte   | Description | 
 | ----   | ----------- | 
 | Byte 0 | 249 (0xF9)  | 
 | Byte 1 | 2 (0x02)    | 
 | Byte 2 | 255 (0xFF)  | 
 | Byte 3 | 118 (0x76)  | 

 1.  **Byte 0**: Normalized integer, Fahrenheit, Sensor 5
 2.  **Byte 1**: Decimal point should be shifted two steps to the left.
 3.  **Byte 2/3**: Bit 16 is a one meaning it's a negative number. Temperature is a two complement number. 0xFF76 = 0b1111111101110110. Invert which give 0b0000000010001001 add one which give 0b0000000010001010 = 138. Divide by 100 gives 1.38 The read temperature is -1.38 ºF.

### Data coding byte for Kelvin

 | Bits  | Description | 
 | ----  | ----------- | 
 | 5,6,7 | Always set to 4 (0b100) - Normalized integer format. | 
 | 3,4   | __**Unit**:__\\ **0 (0b00)** - Kelvin.\\  **1 (0b01)** – Celsius.\\  **2 (0b10)** – Fahrenheit. | 
 | 0,1,2 | __**Sensor Index**:__\\ **0 (0b000)** - Sensor 0.\\ **1 (0b001)** - Sensor 1.\\ **2 (0b010)** - Sensor 2.\\ **3 (0b011)** - Sensor 3.\\ **4 (0b100)** - Sensor 4.\\ **5 (0b101)** - Sensor 5. | 

To help to interpret data the three tables below list the datacoding bytes for Kelvin, Celsius and Fahrenheit temperature presentation.

#### Kelvin data coding table

 | Sensor   | Value for data coding byte | 
 | ------   | -------------------------- | 
 | Sensor 0 | 129 (0x81)                 | 
 | Sensor 1 | 130(0x82)                  | 
 | Sensor 2 | 131(0x83)                  | 
 | Sensor 3 | 132(0x84)                  | 
 | Sensor 4 | 133(0x85)                  | 
 | Sensor 5 | 134(0x86)                  | 

#### Celsius data coding table

 | Sensor   | Value for data coding byte | 
 | ------   | -------------------------- | 
 | Sensor 0 | 136(0x88)                  | 
 | Sensor 1 | 137(0x89)                  | 
 | Sensor 2 | 138(0x8A)                  | 
 | Sensor 3 | 139(0x8B)                  | 
 | Sensor 4 | 140(0x8C)                  | 
 | Sensor 5 | 141(0x8D)                  | 

#### Fahrenheit Vdata coding table

 | Sensor   | Value for data coding byte | 
 | ------   | -------------------------- | 
 | Sensor 0 | 244 (0xF4)                 | 
 | Sensor 1 | 245 (0xF5)                 | 
 | Sensor 2 | 246 (0xF6)                 | 
 | Sensor 3 | 247 (0xF7)                 | 
 | Sensor 4 | 248 (0xF8)                 | 
 | Sensor 5 | 249 (0xF9)                 | 

## Alarm Event

If enabled the event is sent when a temperature sensor goes below a low alarm set point (see [Low-alarm-registers](#registers)) or above a high alarm set point (see [High-alarm-registers](#registers)). The hysteresis registers is used so that after an alarm event has been sent a new alarm event is not sent until the temperature goes below/above the value set in the set point plus(low)/minus(high) signed content of hysteresis register. 

A read of the alarm register will reset the alarm status and alarm events will not be sent out again until the the temperature changed with the hysteresis amount.

 | Event | Description | 
 | -----  | ----------- | 
 | [CLASS1.ALARM, Type=2, Alarm occurred](http://www.vscp.org/docs/vscpspec/doku.php?id=class1.alarm#type_2_0x02_alarm_occurred) | __**Data**__\\ **Byte 0** - Index. Index is 0 for Sensor 0. 1 for Sensor 1, 2 for Sensor 2. 3 for Sensor 3. 4 for Sensor 4. 5 for Sensor 5. \\ **Byte 1** - Zone.\\ **Byte 2** - Sub zone. | 

Zone and sub-zone are the modules settings for the sensor generating the alarm. See [register 74-85](#registers)

## TurnOn/TurnOff Event

If enabled, the event [CLASS1.CONTROL, Type=5, TurnOn](http://www.vscp.org/docs/vscpspec/doku.php?id=class1.control#type_5_0x05_turnon) or [CLASS1.CONTROL, Type=6, TurnOff](http://www.vscp.org/docs/vscpspec/doku.php?id=class1.control#type_6_0x06_turnoff) (Bit 5 in control register must be set (see [Control-registers](registers#sensor_control_ registers)])) is sent when the temperature goes below or above the low(see [Low-alarm-registers](registers#low_ alarm_registers)/high(see [High-alarm-registers](registers#high_ alarm_registers) alarm set points. Settings in the control register bit 6 (see [sub:Control-registers]) decides which of the **TurnOn/TurnOff** event that is sent. The hysteresis setting (see [sub:Sensor-hysteresis-registers]) tells how much a temperature must raise or fall below the alarm set point before a new event will be sent.

 | Event | Description | 
 | ----- | ----------- | 
 | [CLASS1.CONTROL, Type=5, TurnOn](http://www.vscp.org/docs/vscpspec/doku.php?id=class1.control#type_5_0x05_turnon) | __**Data**:__\\ **0** Index,\\ **1** Zone.\\ **2** Sub zone. | 

 | Event | Description | 
 | ----- | ----------- | 
 | [CLASS1.CONTROL, Type=6, TurnOff](http://www.vscp.org/docs/vscpspec/doku.php?id=class1.control#type_6_0x06_turnoff) | __**Data**:__\\ **0** Index,\\ **1** Zone.\\ **2** Sub zone. | 

__**Index**__ is 0 for Sensor 0, 1 for Sensor 1, 2 for Sensor 2. 3 for Sensor 3. 4 for Sensor 4. 5 for Sensor 5. 

__**Zone**__ information is fetched from sensor zone register (see [sensor zone information registers](http://www.grodansparadis.com/kelvinntc10k/manual/doku.php?id=registers#sensor_zone_information_registers)). 

__**Sub zone**__ information is fetched from sensor sub-zone register (see [sensor zone information registers](http://www.grodansparadis.com/kelvinntc10k/manual/doku.php?id=registers#sensor_zone_information_registers)).

## Sync. Event (incoming)

If a SYNC event is received by the module it will check the zone/subzone parameters of the event and send out [temperature measurement event(s)](http://www.grodansparadis.com/kelvinntc10k/manual/doku.php?id=events#temperature_event) for all sensors that match. This can be a handy feature to use of one want synchronized data from several sources.

 | Event | Description | 
 | ----- | ----------- | 
 | [CLASS1.CONTROL, Type=26, Sync](http://www.vscp.org/docs/vscpspec/doku.php?id=class1.control#type_26_0x1a_sync) | __**Data**:__\\ **0** Index,\\ **1** Zone.\\ **2** Sub zone. | 

 # Recipes

*  **The story about an old Fridge**: [http://grodansparadis.com/wordpress/?p=1384](https://www.grodansparadis.com/wordpress/?p=1384)

# faq - Frequently Asked Questions

*Not many of those yet!*

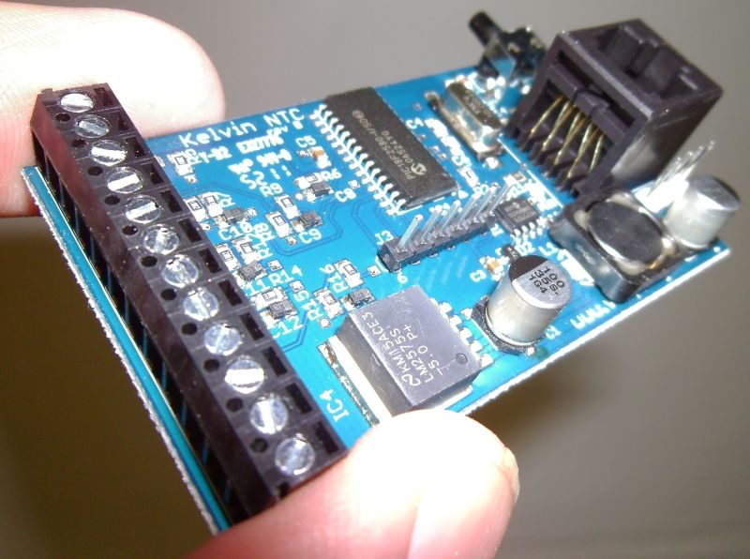
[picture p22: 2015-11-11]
docs/images/2_home_akhe_vscp_hardware_can4vscp_kelvin_kelvi___les_Kelvin_NTC_manual_images_kelvinntc10ka1.jpg

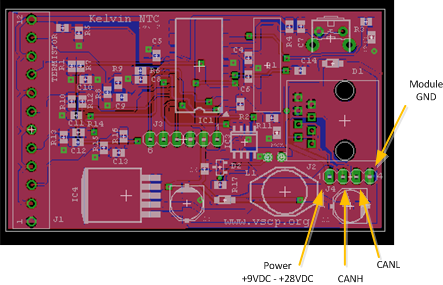
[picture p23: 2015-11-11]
docs/images/8_home_akhe_vscp_hardware_can4vscp_kelvin_kelvi___les_Kelvin_NTC_manual_images_Daisyconnector.png

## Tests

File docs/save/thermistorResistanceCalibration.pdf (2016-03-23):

EAS 199B | Thermistor Calibration: T = F(R)
Spring 2010 | Gerald Recktenwald
| gerry@me.pdx.edu

## Introduction

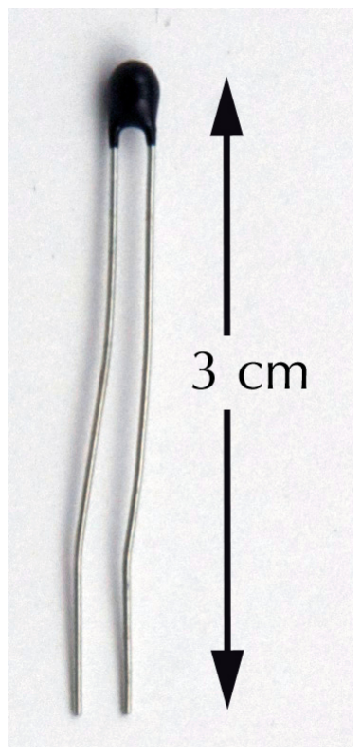
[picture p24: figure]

Figure 1: Bare thermistor element used in the fish tank exercise.

Thermistors are ceramic or polymer-based devices used to measure temperature. The resistance of a thermistor varies with temperature, so by measuring resistance, one can infer the temperature of the environment or object in thermal contact with the thermistor. Thermistors are relatively inexpensive and are available in a variety of physical configurations, from tiny surface mount IC packages, to two-wire sensing elements used in EAS 199B. Figure 1 is a photograph of the thermistor element used in the fish tank exercise in EAS 199B.
Thermistors are characterized by whether their resistance increases with temperature – positive temperature coefficient or PTC – or whether their temperature decreases with temperature – negative temperature coefficient or NTC. The temperature response is nonlinear, but the response can be characterized by a fairly simple calibration equation. The sensor in Figure 1 is a NTC thermistor with a nominal resistance of 10 kΩ at 21 ◦C.
A resistance temperature detector or RTD is another type of
sensor that uses the variation of electrical resistance with temperature. RTDs are made of metal – the standard metal is platinum –
and are used in applications where precision and long term stability are important. RTDs usually cost more than thermistors.

## Calibration

Calibration is the process of matching the output of a sensor to a set of known reference values. For a thermistor, the calibration equation relates the resistance to the temperature. The procedure discussed here assumes that a sufficiently accurate device for measuring resistance is available. The relationship between resistance and temperature of a thermistor can be very closely approximated by the empirical function

T =

1
c1 + c2 ln(R) + c3(ln(R))³
. | (1)

which is called the Steinhart-Hart Equation [1]. The values of the constants, c1, c2, and c3 are constant for a given thermistor. The primary goal of the calibration experiment is to obtain at set of T and R values that allow c1, c2 and c3 to be computed. The remainder of this document is concerned with two basic steps in the calibration of a thermistor. First we describe the configuration of the experiment to measure temperature as a function of resistance. Next we discuss the mathematical procedure for obtaining a calibration equation from the temperature versus resistance data.

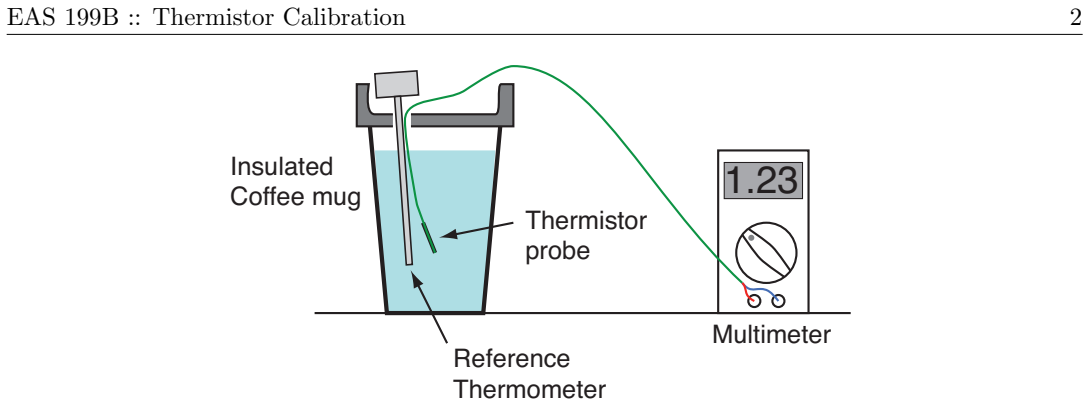
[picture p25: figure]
EAS 199B :: Thermistor Calibration; Multimeter; Insulated Coffee mug; Thermistor probe; Reference Thermometer

Figure 2: Sketch of hardware used for the thermistor calibration.

Calibration Measurements

Figure 2 is a schematic representation of the equipment used in the calibration measurements. An insulated coffee mug provides a stable and adjustable temperature environment for the reference thermometer and the thermistor probe. The thermistor resistance is recorded with a multimeter. Figure 3 has photos of the reference thermometer and the thermistor probe. The reference thermometer is a CDN ProAccurate Quick-Read DTQ450X Thermometer, which is available at on-line stores and kitchen supply stores. The thermistor probe is fabricated from a thermistor sensing element following the directions at http://web.cecs.pdx.edu/~gerry/class/EAS199B/howto/thermistorProbe.
Once the equipment is assembled and ready to use, perform the following steps to obtain the calibration data.
1. Fill the coffee mug with water at a desired temperature.
2. Insert the reference thermometer and the thermistor probe into the water in the mug.
3. Wait for the thermistor probe signal and the reading of the reference temperature to stabilize.
4. Record the temperature and the thermistor resistance. See Table 2 for the recommended layout of the data table.
5. Return to step 1

Table 1: Equipment required for the thermistor calibration experiment.

Equipment | Provided by
Thermistor probe | Student
At least one insulated coffee mug per group | Student
Multimeter capable of reading resistance | Student
Spreadsheet or notebook paper for recording measurements | Student
Digital thermometer | Instructor
Supply of hot and cold water | Instructor

EAS 199B :: Thermistor Calibration | 3

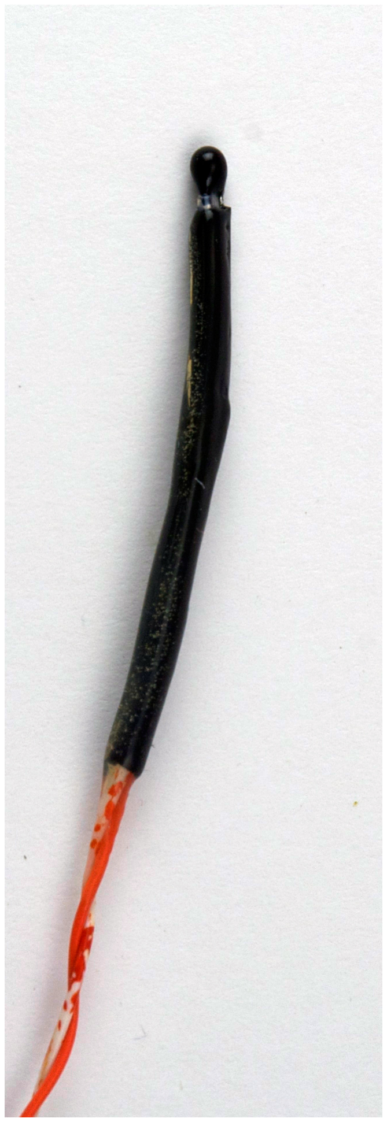
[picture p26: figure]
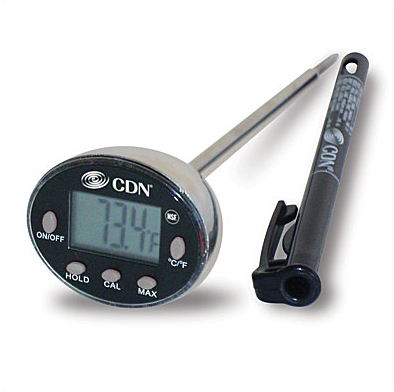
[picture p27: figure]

Figure 3: Digital thermometer and thermistor probe used in the calibration.

A source of hot water is provided in the laboratory. If your group has two mugs, you can be refilling one mug while you wait for the reference thermometer and thermistor probe to come into equilibrium with the water in the other mug.

Table 2: Calibration data and transformed calibration data.

T (

◦C) R (Ω)

−→

1/T (K⁻¹
) ln(R)

EAS 199B :: Thermistor Calibration | 4

Obtaining the Calibration Equation

Equation 1 is a non-linear relationship between the temperature and resistance of a thermistor. Figure 4 shows a set of calibration data for a thermistor probe when the resistance is recorded by a multimeter. The calibration data in Figure 4 reveal several important features

- The temperature decreases non-linearly with resistance. This is an NTC thermistor.
- The Steinhart-Hart equation does a good job of fitting the data
- The polynomial does a poor job of fitting the data. Using polynomials of different degree does not result in a substantially improved polynomial fit.

A direct curve fit with Equation (1) would require a non-linear least squares procedure. Those procedures exist and are not too difficult to implement, but a simpler procedure can be obtained with an algebraic rearrangement that begins by inverting both sides of Equation (1)

1
T

= c1 + c2 ln(R) + c3(ln(R))³
. | (2)

This equation is almost a polynomial of the form T = f(ln(R)). Adding the missing quadratic term gives
1
T

= a1 + a2 ln(R) + a3(ln(R))² + a4(ln(R))³
. | (3)

Equation 3 is now in the format of a polynomial where the independent variable is ln(R). An additional transformation is required to obtain good results in the calibration equation. The left hand side of Equation (3) will take on large values as T → 0. To improve the numerical behavior of the least squares curve fit, use T in absolute temperature, e.g., kelvin, instead of temperature in Celsius or Fahrenheit.

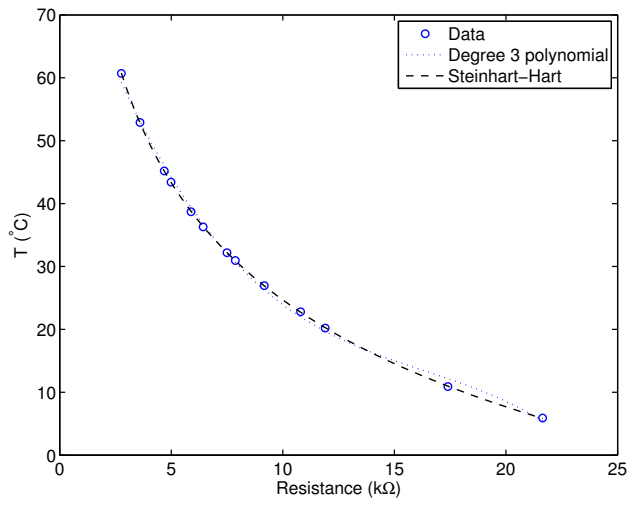
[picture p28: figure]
Resistance (kΩ); Data Degree 3 polynomial Steinhart−Hart

Figure 4: Typical calibration data recorded with a multimeter. Raw data is in Appendix A.

EAS 199B :: Thermistor Calibration | 5

Procedure for Obtaining the Calibration Equation

The following steps yield a calibration equation for the thermistor.

1. Record the temperature and resistance output in the two columns on the left sided of Table 2.
2. Convert the temperature values to 1/T, where T is on an absolute scale such as kelvin.
3. Convert the R values to ln(R).
4. Obtain the polynomial curve fit to the transformed data. The curve fit coefficients are the value of the ai

in Equation (3).

After the curve fit coefficients are obtained, the calibration equation is evaluated with

T(

◦C) = | 1
a1 + a2 ln(R) + a3(ln(R))² + a4(ln(R))³
− 273.15 | (4)

where T is in kelvin. If the curve fit is obtained in ◦R, then the constant at then end of Equation (4) is 459.67, not 237.15.

Inverse Calibration: R = f(T)

In some situations, we may want to predict the thermistor resistance R when the temperature is known. Let’s call this the inverse calibration. How can we design the curve fit for R = F(T)? Although Equation (1) or Equation (4) are the desired final forms of the calibration equation, the least squares curve fit to obtain the coefficients a1 . . . a4 was obtained with the transformation in Equation (3). Therefore, since a good curve fit to the calibration data is obtained with (1/T) = F(ln(R)), it is reasonable to expect that an inverse curve fit can be obtained with ln(R) = G(1/T). Experience shows that the inverse relationship can be fit with

ln(R) = b1 + b2

1
T
+ b3
1
T

2
. | (5)

Procedure for Obtaining the Inverse Calibration Equation

The following steps yield a calibration equation for the thermistor.

1. Convert the temperature values to 1/T, where T is on an absolute scale such as kelvin.
2. Convert R to ln(R).
3. Use the least squares procedure to obtain the coefficients b1, b2, and b3 in Equation (5).

After the curve fit coefficients are obtained, the inverse calibration equation is evaluated with

R = exp "
b1 + b2
1
T
+ b3
1
T

2

. | (6)

where T is absolute temperature.

## References

[1] John S. Steinhart and R. Hart, Stanley. Calibration curves for thermistors. Deep-Sea Research, 15:497–503, 1968.

EAS 199B :: Thermistor Calibration | 6

## Appendix: Sample calibration data

Calibration data for a MF52A103J3470 NTC thermistor with a nominal resistance of 10 kΩ at 21 ◦C. Data recorded 25 May 2010 with a Fluke 77 multimeter and a CDN ProAccurate Quick-Read DTQ450X Thermometer.

T(C) | R(kOhm)
43.40 | 4.99
52.90 | 3.60
5.90 | 21.64
60.70 | 2.77
10.90 | 17.40
45.20 | 4.69
20.20 | 11.90
36.30 | 6.43
26.95 | 9.17
30.95 | 7.87
32.20 | 7.50
22.80 | 10.80
38.70 | 5.89

## Appendix: Matlab code for obtaining calibration equations

EAS 199B :: Thermistor Calibration | 7

function thermistorResistanceCalibration(n,ni,datadump)
% thermistorResistanceCalibration | Curve fit thermistor calibration data T = f(R)
% | where R is the resistance of the thermistor
%
% Synopsis: | thermistorResistanceCalibration
% | thermistorResistanceCalibration(n)
% | thermistorResistanceCalibration(n,ni)
% | thermistorResistanceCalibration(n,ni,datadump)
%
% Input: | n = degree of attempted polynomial fit R = f(T), Default: | n = 3;
% | ni = degree of polynomial used in the inverse curve fit R = g(T)
% | Default: | ni = 2;
% | datadump = flag (true or false) determining whether T = f(R) data
% | is written to a text file. | Default: | datadump = false
if nargin<1, n=3; | | end
if nargin<2, ni=2; | end
if nargin<3, datadump=false; | end

% --- Store data for thermistor 1 and perform the curve fit
% | Data taken at home with Fluke 77 multimeter. | R is resistance in Ohm
% | Reference temperature measured with CDN Pro Quick-read digital thermometer
R = [ 4.99 3.60 21.64 2.767 17.40 4.69 11.90 6.43 | 9.17 | 7.87 | 7.50 10.80 5.89]*1000;
T = [43.4 52.9 | 5.9 60.7 | 10.9 45.2 | 20.2 | 36.3 26.95 30.95 32.2 | 22.8 38.7];

% --- Save the raw data in a text file
if datadump
fout = fopen(’thermistor_RT_data.txt’,’wt’); for i=1:length(R)
fprintf(fout,’%f\t%f\n’,R(i),T(i));
end
fclose(fout);
end
f = figure; | set(f,’Name’,’Thermistor Curve Fit’);
c1 = thermistorFit(R(:),T(:),n); | % R(:) and T(:) guarantees that data sent
% to thermistorFit are column vectors % --- Evaluate the curve fit
Rfit = linspace( min(R), max(R) );
Tfit1 = (1./ (c1(1) + c1(2)*log(Rfit) + c1(3)*(log(Rfit)).^3 ) ) - 273.15;
% --- Plot the curve fit and data on the same axes. | R in kOhm
f = figure; | set(f,’Name’,’Thermistor curve fits’);
plot(R/1000,T,’o’,Rfit/1000,Tfit1,’r:’);
xlabel(’Resistance (k\Omega)’); ylabel(’T (^{\circ}C)’); legend(’Thermistor 1 data’,’SHH fit for thermistor 1’);

% --- Add the nominal (R10,T10) point, where R10 = 10 kOhm
R10 = 10e3;
TR10 = 1./ (c1(1) + c1(2)*log(R10) + c1(3)*(log(R10)).^3 ) - 273.15; hold(’on’);
plot(R10*[1 1]/1000,[0 TR10],’k:’,[0 R10]/1000,TR10*[1 1],’k:’); hold(’off’);
% --- Inverse calibration: | R = g(T). | g(T) is a polynomial of degree ni
ci = polyfit(1./(T+273.15),log(R),ni);
Tifit = linspace(min(T),max(T));
Rifit = exp( polyval(ci,1./(Tifit+273.15)) );
fprintf(’\nInverse fit coefficients:\n’); fprintf(’%18.7e’,ci); fprintf(’\n’);

figure(’Name’,’Inverse fit’); plot(T,R,’o’,Tifit,Rifit,’r--’);
xlabel(’T (C)’); | ylabel(’R | (k\Omega)’);
legend(’Thermistor 1 data’,’Thermistor 1 fit’);

EAS 199B :: Thermistor Calibration | 8

function c = thermistorFit(R,T,n)
% thermistorFit | Curve fit the Steinhart-Hart equation and a degree n polynomial
% | to the thermistor data
%
% Synopsis: | c = thermistorFit(R,T)
% | c = thermistorFit(R,T,n)
%
% Input: | R = column vector of delay times returned by the RCTIME command
% | R is proportional to the resistance of the thermistor
% | T = column vector of temperatures in C | (degrees C because the
% | curve fit coeficients will be obtained with T in kelvin
% | n = optional degree of the polynomial used in the alternative fit
%
% Output: c = vector of coefficients in the Steinhart-Hart equation
if nargin<3, n=3; | end | % Provide defalt value for n
% --- Assemble the m-by-3 design matrix. | m rows of data. | Each column
% | is a basis function for the fit. | The first column is ones, which
% | corresponds the constant in the curve fit.
% | Solve the overdetermined system with the backslash operator, which
% | uses a QR factorization to obtain the least squares fit. | The right
% | hand side vector for the overdetermined system is a column of 1/Tk
% | values, where Tk is the temperature in kelvin.
A = [ones(size(R(:))) log(R(:)) | (log(R(:))).^3];
TKinv = 1 ./ (T(:) + 273.15);
c = A\TKinv;
fprintf(’Steinhart-Hart coefficients\n’);
fprintf(’%17.9e\n’,c)
% --- Use a polynomial fit T = f(R). | Converting the temperature scale
% | to kelvin does not improve the fit.
cp = polyfit(R,T,n);

% --- Evaluate and plot the curve fits over the range of R data Rfit = linspace(min(R),max(R))’;
Tfit = polyval(cp,Rfit);
TfitSH = 1./ (c(1) + c(2)*log(Rfit) + c(3)*(log(Rfit)).^3 );

plot(R/1000,T,’o’,Rfit/1000,Tfit,’b:’,Rfit/1000,TfitSH-273.15,’k--’); xlabel(’Resistance (k\Omega)’); ylabel(’T (^{\circ}C)’); legend(’Data’,sprintf(’Degree %d polynomial’,n),’Steinhart-Hart’);

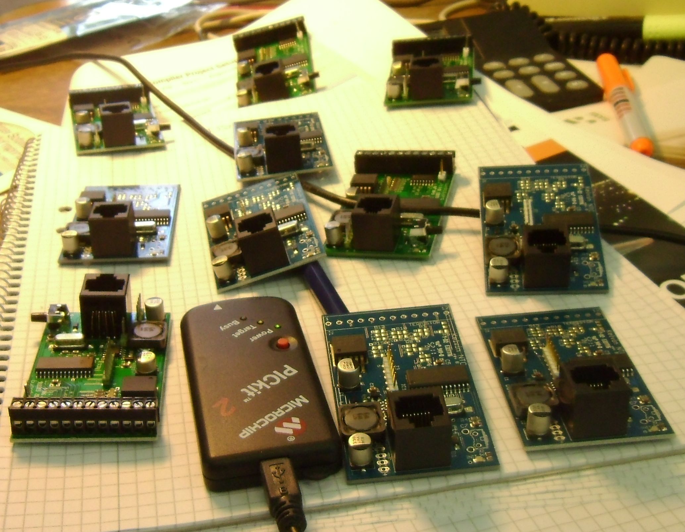
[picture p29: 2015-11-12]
docs/images/testing1.jpg

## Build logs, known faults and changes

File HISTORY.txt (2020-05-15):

Kelvin NTC
==========

2020-05-15 AKHE - Version 1.2.7  VSCP core firmware 1.6.3
2020-05-15 AKHE - Init. timer set to 2500 ms instead of 250 ms
2020-05-15 AKHE - Fixed seconds timer

--------------------------------------------------------------------------------

2016-04-19 AKHE - RA4 set to input to prevent collision with VCAP circuits in
                  PIC18F2580. Brown out raised to maximum (3V & 4.6V). Valuable                    
                  input from Anders Forsgren, AJE Electronics AB.
2016-03-23 AKHE - Version 1.2.6 -------------------------------------------------
2016-03-30 AKHE - Made code work for PIC18F26K80
2016-03-29 AKHE - Raw A/D register values was displayed in wrong order. Fixed.
--------------------------------------------------------------------------------

2016-03-23 AKHE - Version 1.2.5 -------------------------------------------------
2016-03-23 AKHE - Adopted for VSCP firmware 1.6.1
--------------------------------------------------------------------------------

2016-03-23 AKHE - Version 1.2.4 -------------------------------------------------
2016-03-08 AKHE - Adopted to 1.6.0 firmware. Adopted for PIC18F26K80.
2016-02-04 AKHE - Temperature calibration value calculated wrongly.
2015-11-26 AKHE - Fixed problem with low/high limits with negative values. Also
                    limits now are in degrees as is hysteresis as well.
2015-11-25 AKHE - Fixed problem with overwritten calibration value on bootload
2015-11-24 AKHE - Moved limit and alarm tests to one second work where they belong.
2015-09-28 AKHE - Temperature register 5 was not read correctly. Temperature 
                    register 4 was returned erronius instead.
--------------------------------------------------------------------------------

----- Version 1.2.2
2015-09-13 AKHE - Sensor zones/subzones was written correctly but not read correctly
2015-09-13 AKHE - Fixed sync command.
2015-09-13 AKHE - Fixed send overrun problem when send buffer was fill
2014-08-13 AKHE - Added missing fuse config pragmas.
2014-03-22 AKHE - Added mean calculations on temperatures
2014-03-22 AKHE - Added Calibrated voltage variable
2012-10-18 AKHE - Fixed paths so code compiles again.
2012-03-20-AKHE - 10uF C8,C9,C10,C11,C12,C13 Changed from Digikey 493-2328-1-ND to Digikey 445-1371-2-ND 
				Elfa 65-768-30 is alternativ. 
				Digikey 445-1371-1-ND is alternativ.
2012-01-29 AKHE - Started development from old Kelvin SHT

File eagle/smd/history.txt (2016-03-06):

Kelvin NTC
==========
Kelvin NTC
==========
2016-03-06 - AKHE C14 should be 10u for 26K80
2015-06-16 - AKHE Power lines to thin - fixed.
2011-12-20 - AKHE Added termination resistor. Leave unpopulated.
2011-11-17 - AKHE Added 1uF capacitor on uP pin 6 forPIC18F66K80 compability
2011-11-15 - AKHE Move L1 so it fits on the board.
2011-11-10 - AKHE Packages for D1/D2 updatet to SOD123 from SMDB
2011-11-10 - AKHE CANH should be on pin 4 of RJ-45
2011-11-10 - AKHE Rev B
2011-11-02 - AKHE Kontaktlist uppdaterad. Hål var 0.9 och för trånga. Nu 1.2 istället.

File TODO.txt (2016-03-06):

2014-03-23 AKHE - Enable 32 - bit floating bit format. CLASS=70

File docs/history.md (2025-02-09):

# Change Log for Accra

Change log for the module is at
[here](https://github.com/grodansparadis/can4vscp_paris/blob/master/HISTORY.txt)

| 250113 | akhe | Fixed some links |
| 220602 | akhe | Transferred to Markdown format |

[filename](./bottom-copyright.md ':include')

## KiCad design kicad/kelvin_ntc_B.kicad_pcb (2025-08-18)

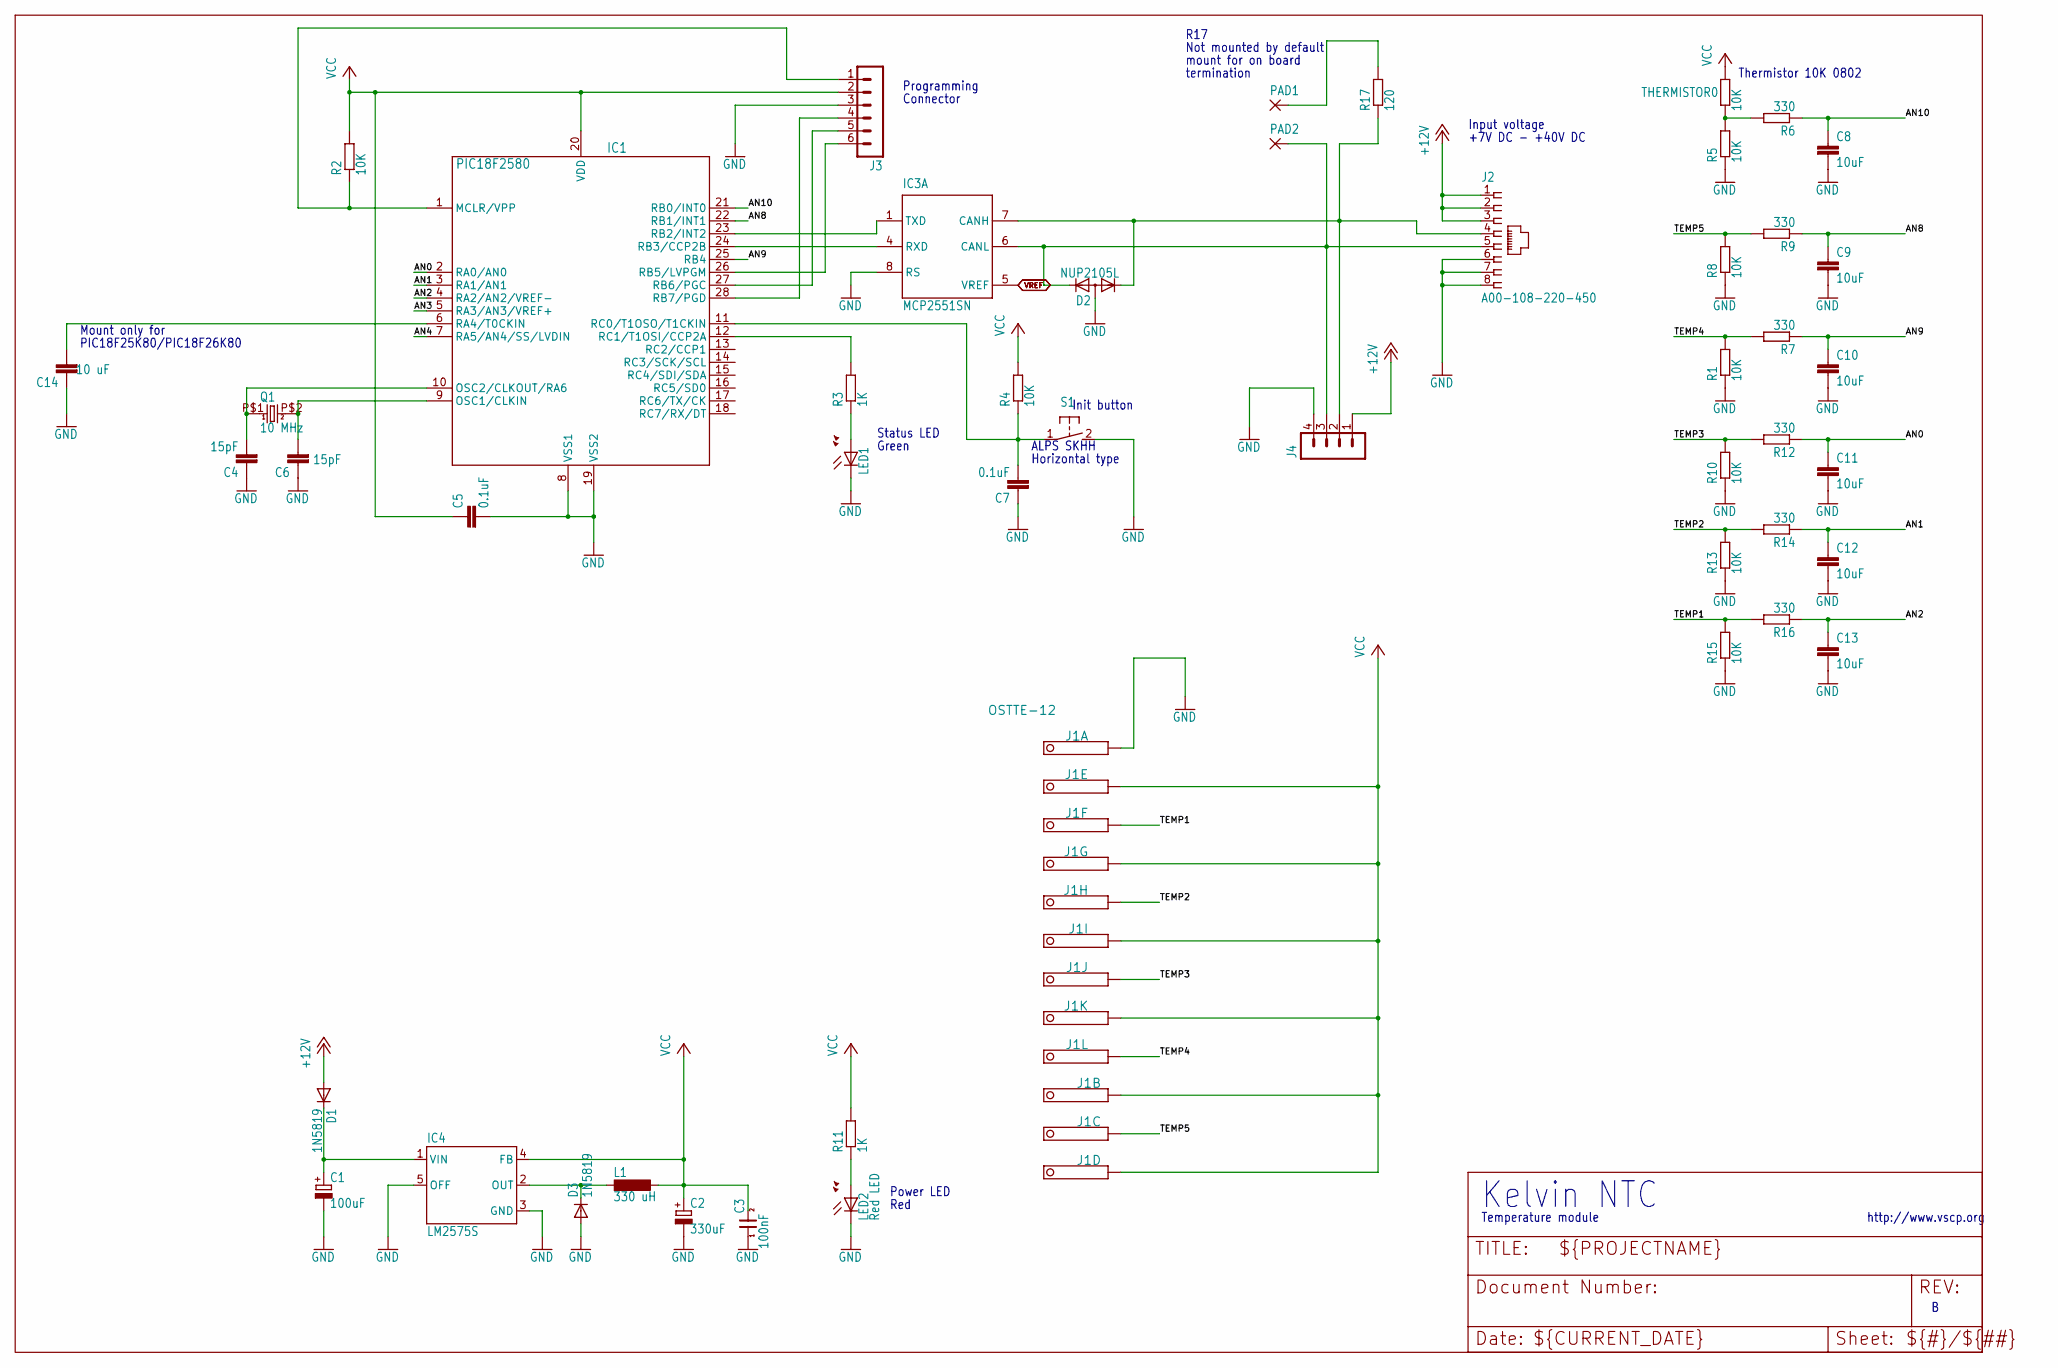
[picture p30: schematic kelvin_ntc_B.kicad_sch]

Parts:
C1: 100uF; PANASONIC_D
C2: 330uF; PANASONIC_D
C3: 100nF; 0805
C4, C6: 15pF; C0805
C5, C7: 0.1uF; C0805
C8, C9, C10, C11, C12, C13: 10uF; C0805
C14: 10 uF; C0805
D1, D3: 1N5819; SOD123
D2: NUP2105L; SOT23
IC1: PIC18F2580; SO28
IC3: MCP2551SN; SO-08
IC4: LM2575S; TO263-5
J1: OSTTE-12; PINHEAD-12
J2: A00-108-220-450; RJ-45
J3: MA06-1
J4: MA04-1
L1: 330 uH; DO3316P
LED1: LEDCHIP-LED0805; CHIP-LED0805
LED2: Red LED; CHIP-LED0805
PAD1, PAD2: 1,6/0,8; 1,6_0,8
Q1: 10 MHz; 9C
R1, R2, R4, R5, R8, R10, R13, R15: 10K; R0805
R3, R11: 1K; R0805
R6, R7, R9, R12, R14, R16: 330; R0805
R17: 120; R0805
S1: 31-XX; B3F-31XX
THERMISTOR0: 10K; R0805

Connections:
+12V: D1.A, J2.1, J2.2, J2.3, J4.1
AN0: C11.1, IC1.2 (RA0/AN0), R12.1
AN1: C12.1, IC1.3 (RA1/AN1), R14.1
AN2: C13.1, IC1.4 (RA2/AN2/VREF-), R16.1
AN3: IC1.5 (RA3/AN3/VREF+)
AN4: IC1.7 (RA5/AN4/SS/LVDIN)
AN8: C9.1, IC1.22 (RB1/INT1), R9.1
AN9: C10.1, IC1.25 (RB4), R7.1
AN10: C8.1, IC1.21 (RB0/INT0), R6.1
CANH: D2.1 (K1), IC3.7 (CANH), J2.4, J4.2, R17.1
CANL: D2.2 (K2), IC3.6 (CANL), J2.5, J4.3, PAD2.1
GND: C1.-, C2.-, C3.1, C4.1, C5.2, C6.1, C7.1, C8.2, C9.2, C10.2, C11.2, C12.2, C13.2, C14.1, D2.3 (A), D3.A, IC1.8 (VSS1), IC1.19 (VSS2), IC3.2 (VSS), IC3.8 (RS), IC4.3 (GND), IC4.5 (OFF), J1.1, J2.6, J2.7, J2.8, J3.3, J4.4, LED1.C, LED2.C, R1.1, R5.1, R8.1, R10.1, R13.1, R15.1, S1.2 (S)
unnamed: D3.C, IC4.2 (OUT), L1.1
unnamed: C4.2, IC1.10 (OSC2/CLKOUT/RA6), Q1.P$1 (1)
unnamed: C1.+, D1.C, IC4.1 (VIN)
unnamed: IC1.12 (RC1/T1OSI/CCP2A), R3.2
unnamed: LED1.A, R3.1
unnamed: C7.2, IC1.11 (RC0/T1OSO/T1CKIN), R4.1, S1.1
unnamed: C6.2, IC1.9 (OSC1/CLKIN), Q1.P$2 (2)
unnamed: R5.2, R6.2, THERMISTOR0.1
unnamed: C14.2, IC1.6 (RA4/T0CKIN)
unnamed: PAD1.1, R17.2
unnamed: IC1.1 (MCLR/VPP), J3.1, R2.1
unnamed: IC1.28 (RB7/PGD), J3.4
unnamed: IC1.27 (RB6/PGC), J3.5
unnamed: IC1.26 (RB5/LVPGM), J3.6
unnamed: LED2.A, R11.1
RXCAN: IC1.24 (RB3/CCP2B), IC3.4 (RXD)
TEMP1: J1.3, R15.2, R16.2
TEMP2: J1.5, R13.2, R14.2
TEMP3: J1.7, R10.2, R12.2
TEMP4: J1.9, R1.2, R7.2
TEMP5: J1.11, R8.2, R9.2
TXCAN: IC1.23 (RB2/INT2), IC3.1 (TXD)
VCC: C2.+, C3.2, C5.1, IC1.20 (VDD), IC3.3 (VDD), IC4.4 (FB), J1.2, J1.4, J1.6, J1.8, J1.10, J1.12, J3.2, L1.2, R2.2, R4.2, R11.2, THERMISTOR0.2
VREF: IC3.5 (VREF)

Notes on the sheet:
Init button
Connector
http://www.vscp.org
Mount only for
Input voltage
R17
Red
Thermistor 10K 0802
mount for on board
termination
Kelvin NTC
Horizontal type
Programming
Status LED
Not mounted by default
Power LED
+7V DC - +40V DC
Green
PIC18F25K80/PIC18F26K80
Temperature module
ALPS SKHH

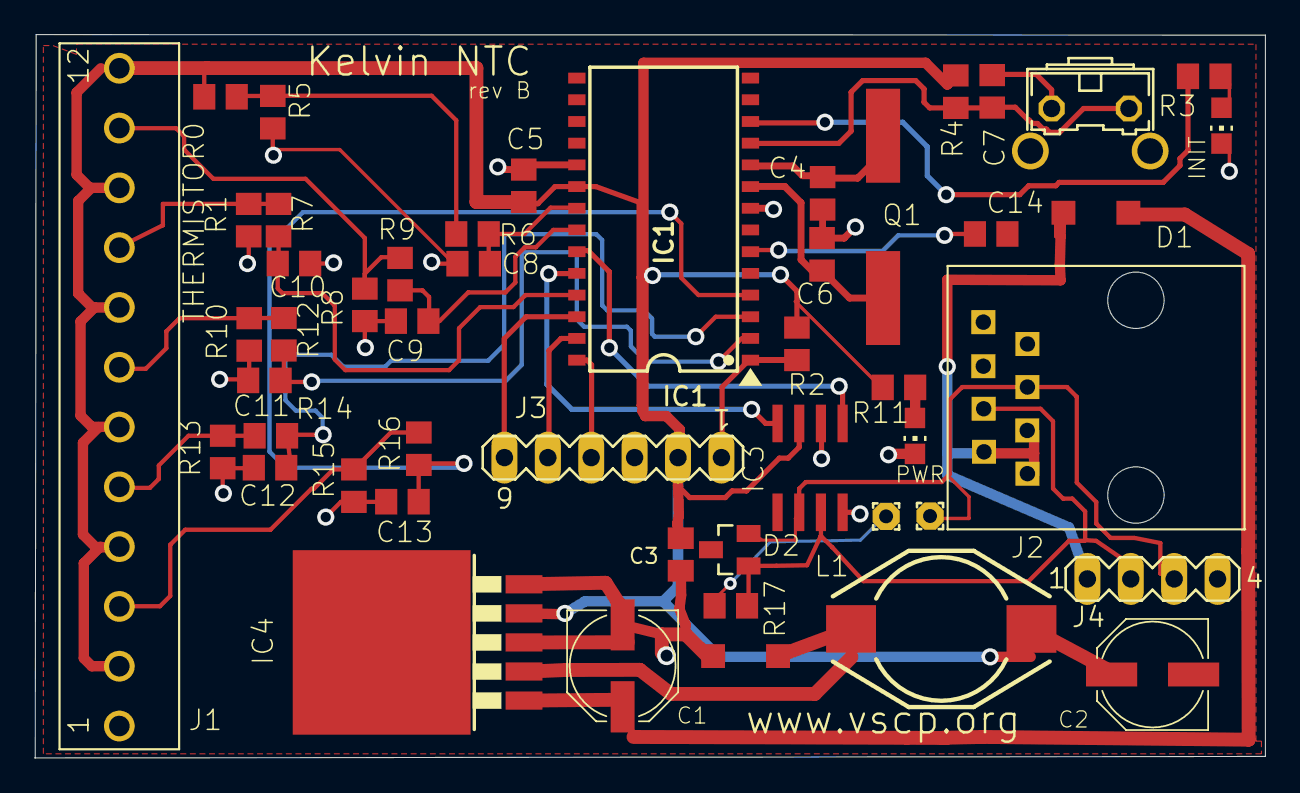
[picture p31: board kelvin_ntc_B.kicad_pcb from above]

Board: 6 copper layers, 72.0 x 42.3 mm, 49 parts (0 on the bottom side), 33 nets.

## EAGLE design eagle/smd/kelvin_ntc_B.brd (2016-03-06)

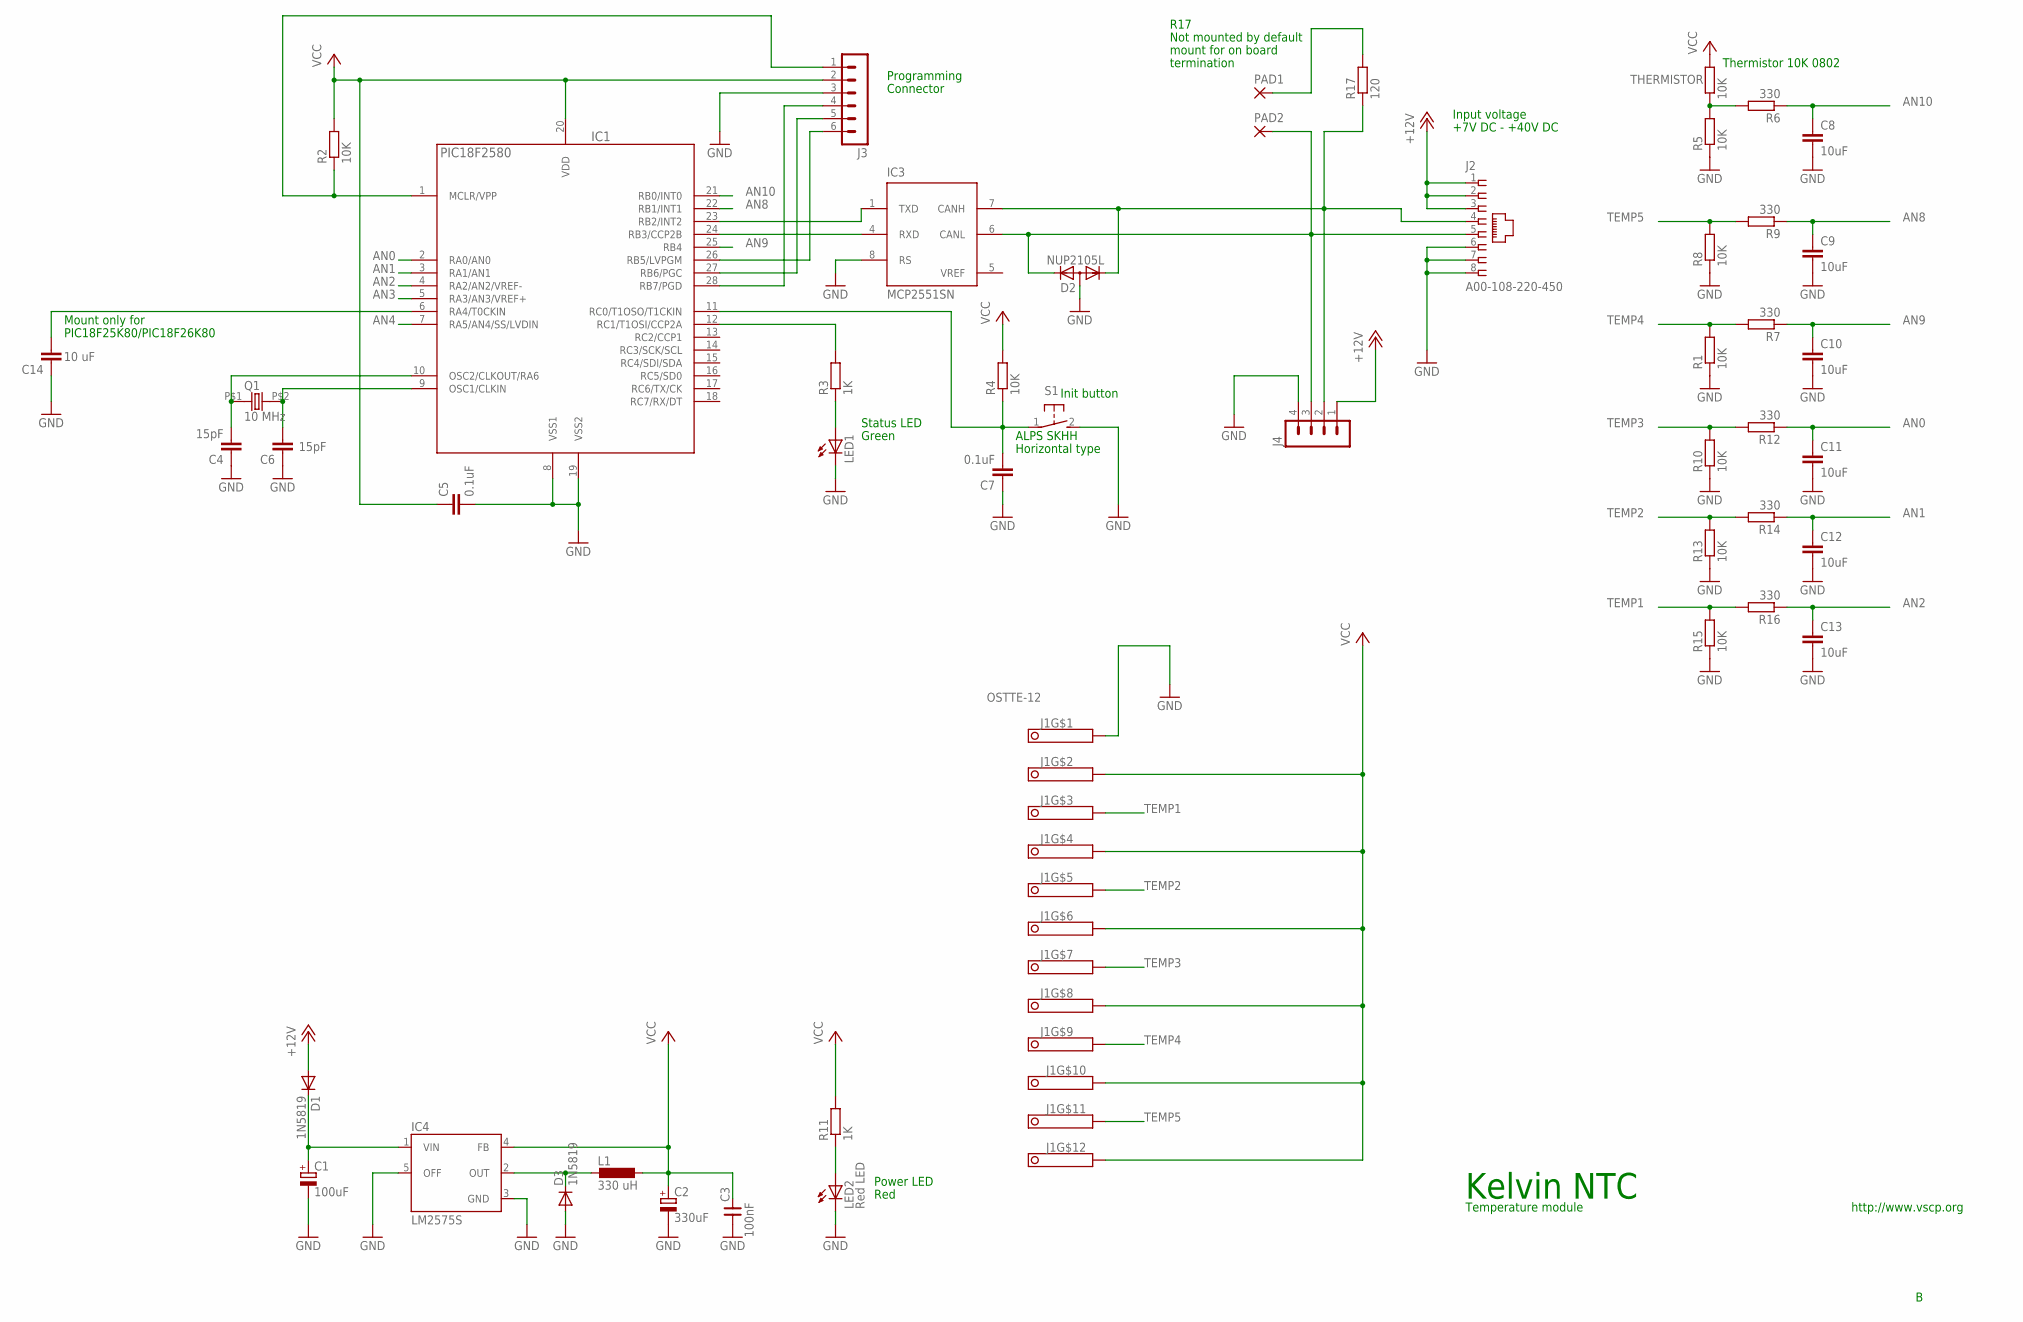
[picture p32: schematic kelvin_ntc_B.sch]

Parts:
C1: 100uF; PANASONIC_D
C2: 330uF; PANASONIC_D
C3: 100nF; 0805
C4, C6: 15pF; C0805
C5, C7: 0.1uF; C0805
C8, C9, C10, C11, C12, C13: 10uF; C0805
C14: 10 uF; C0805
D1, D3: 1N5819; SOD123
D2: NUP2105L; SOT23
IC1: PIC18F2580; SO28
IC3: MCP2551SN; SO-08
IC4: LM2575S; TO263-5
J1: OSTTE-12; PINHEAD-12
J2: A00-108-220-450; RJ-45
J3: MA06-1
J4: MA04-1
L1: 330 uH; DO3316P
LED1: LEDCHIP-LED0805; CHIP-LED0805
LED2: Red LED; CHIP-LED0805
PAD1, PAD2: 1,6/0,8
Q1: 10 MHz; 9C
R1, R2, R4, R5, R8, R10, R13, R15: 10K; R0805
R3, R11: 1K; R0805
R6, R7, R9, R12, R14, R16: 330; R0805
R17: 120; R0805
S1: 31-XX; B3F-31XX
THERMISTOR: 10K; R0805

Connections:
+12V: D1.A, J2.1, J2.2, J2.3, J4.1
AN0: C11.1, IC1.2 (RA0/AN0), R12.1
AN1: C12.1, IC1.3 (RA1/AN1), R14.1
AN2: C13.1, IC1.4 (RA2/AN2/VREF-), R16.1
AN3: IC1.5 (RA3/AN3/VREF+)
AN4: IC1.7 (RA5/AN4/SS/LVDIN)
AN8: C9.1, IC1.22 (RB1/INT1), R9.1
AN9: C10.1, IC1.25 (RB4), R7.1
AN10: C8.1, IC1.21 (RB0/INT0), R6.1
CANH: D2.1 (K1), IC3.7 (CANH), J2.4, J4.2, R17.1
CANL: D2.2 (K2), IC3.6 (CANL), J2.5, J4.3, PAD2.1
GND: C1.-, C2.-, C3.1, C4.1, C5.2, C6.1, C7.1, C8.2, C9.2, C10.2, C11.2, C12.2, C13.2, C14.1, D2.3 (A), D3.A, IC1.8 (VSS1), IC1.19 (VSS2), IC3.2 (VSS), IC3.8 (RS), IC4.3 (GND), IC4.5 (OFF), J1.1, J2.6, J2.7, J2.8, J3.3, J4.4, LED1.C, LED2.C, R1.1, R5.1, R8.1, R10.1, R13.1, R15.1, S1.2 (S)
unnamed: D3.C, IC4.2 (OUT), L1.1
unnamed: C4.2, IC1.10 (OSC2/CLKOUT/RA6), Q1.P$1 (1)
unnamed: C1.+, D1.C, IC4.1 (VIN)
unnamed: IC1.12 (RC1/T1OSI/CCP2A), R3.2
unnamed: LED1.A, R3.1
unnamed: C7.2, IC1.11 (RC0/T1OSO/T1CKIN), R4.1, S1.1
unnamed: C6.2, IC1.9 (OSC1/CLKIN), Q1.P$2 (2)
unnamed: R5.2, R6.2, THERMISTOR.1
unnamed: C14.2, IC1.6 (RA4/T0CKIN)
unnamed: PAD1.1, R17.2
unnamed: IC1.1 (MCLR/VPP), J3.1, R2.1
unnamed: IC1.28 (RB7/PGD), J3.4
unnamed: IC1.27 (RB6/PGC), J3.5
unnamed: IC1.26 (RB5/LVPGM), J3.6
unnamed: LED2.A, R11.1
RXCAN: IC1.24 (RB3/CCP2B), IC3.4 (RXD)
TEMP1: J1.3, R15.2, R16.2
TEMP2: J1.5, R13.2, R14.2
TEMP3: J1.7, R10.2, R12.2
TEMP4: J1.9, R1.2, R7.2
TEMP5: J1.11, R8.2, R9.2
TXCAN: IC1.23 (RB2/INT2), IC3.1 (TXD)
VCC: C2.+, C3.2, C5.1, IC1.20 (VDD), IC3.3 (VDD), IC4.4 (FB), J1.2, J1.4, J1.6, J1.8, J1.10, J1.12, J3.2, L1.2, R2.2, R4.2, R11.2, THERMISTOR.2
VREF: IC3.5 (VREF)

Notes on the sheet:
Init button
Status LED
Programming
Connector
ALPS SKHH
Horizontal type
Kelvin NTC
http://www.vscp.org
Temperature module
Input voltage
+7V DC - +40V DC
Power LED
Red
Green
Thermistor 10K 0802
Mount only for
PIC18F25K80/PIC18F26K80
Not mounted by default
mount for on board
termination
R17

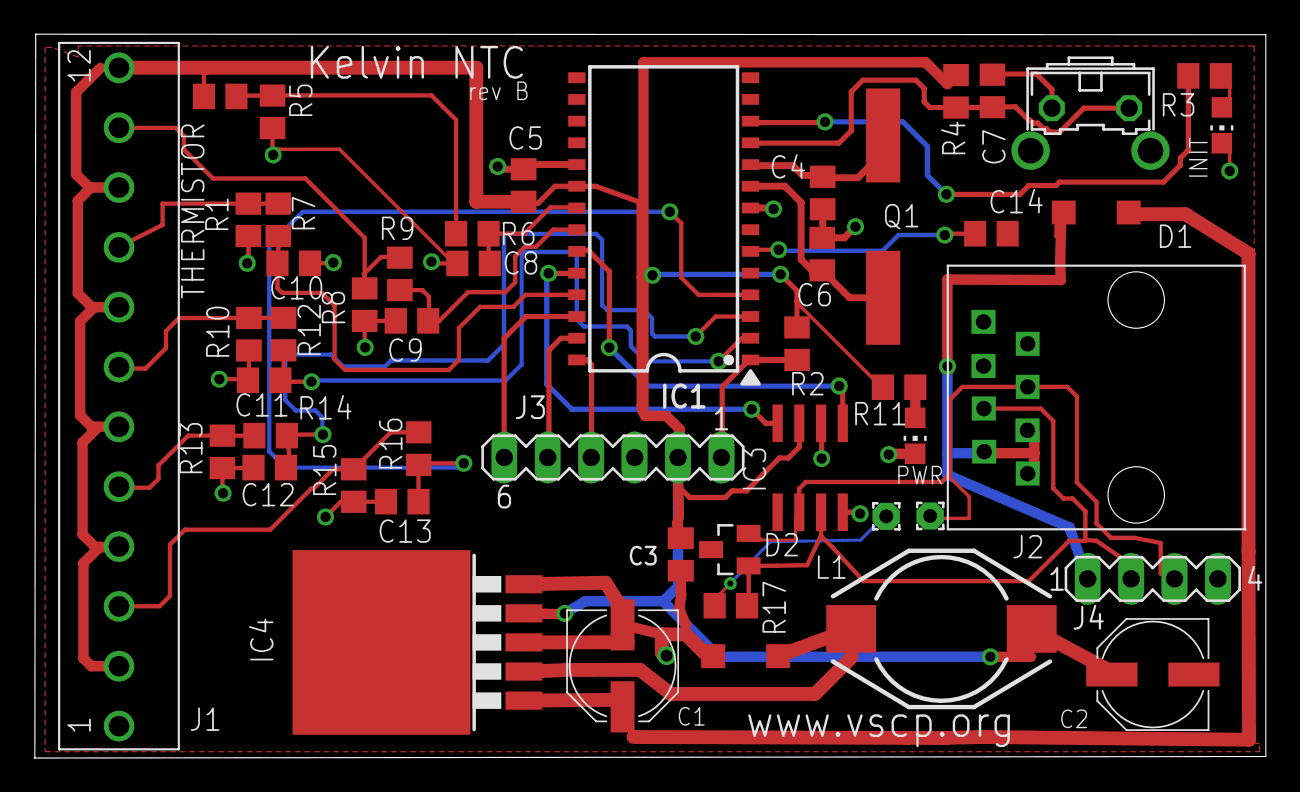
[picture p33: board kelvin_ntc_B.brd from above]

Board: 2 copper layers, 72.0 x 42.3 mm, 49 parts (0 on the bottom side), 33 nets.

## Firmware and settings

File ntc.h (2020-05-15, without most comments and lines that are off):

#define NTC_H
#include <vscp_inttypes.h>
#include "main.h"
#define NUMBER_OF_TEMP_SERIES               80
#define DEFAULT_CONTROL_REG                 0b00000001
#define MASK_CONTROL_UNIT                   0x03
#define MASK_CONTROL_LOW_ALARM              0x08
#define MASK_CONTROL_HIGH_ALARM             0x10
#define MASK_CONTROL_TURNX                  0x20
#define MASK_CONTROL_TURNX_INVERT           0x40
#define MASK_CONTROL_CONTINUOUS             0x80
#define DEFAULT_REPORT_INTERVAL_SENSOR0     30
#define DEFAULT_REPORT_INTERVAL             0
#define DEFAULT_B_CONSTANT_SENSOR0_MSB      0x0F
#define DEFAULT_B_CONSTANT_SENSOR0_LSB      0x68
#define DEFAULT_B_CONSTANT_MSB              0x0D
#define DEFAULT_B_CONSTANT_LSB              0x7F
#define DEFAULT_INTERNAL_COEFFICIENT_A1     4.524024725919526e-004
#define DEFAULT_INTERNAL_COEFFICIENT_A2     3.934722516618191e-004
#define DEFAULT_INTERNAL_COEFFICIENT_A3     -7.642331765196044e-006
#define DEFAULT_INTERNAL_COEFFICIENT_A4     4.048572707661904e-007
#define DEFAULT_EXTERNAL_COEFFICIENT_A1     4.524024725919526e-004
#define DEFAULT_EXTERNAL_COEFFICIENT_A2     3.934722516618191e-004
#define DEFAULT_EXTERNAL_COEFFICIENT_A3     -7.642331765196044e-006
#define DEFAULT_EXTERNAL_COEFFICIENT_A4     4.048572707661904e-007
#define DEFAULT_LOW_ALARM_MSB               0x80
#define DEFAULT_LOW_ALARM_LSB               0xff
#define DEFAULT_HIGH_ALARM_MSB              0x7f
#define DEFAULT_HIGH_ALARM_LSB              0xff
#define DEFAULT_SENSOR_ZONE                 0
#define DEFAULT_SENSOR_SUBZONE              0
#define DEFAULT_LOW_MSB                     0x7f
#define DEFAULT_LOW_LSB                     0xff
#define DEFAULT_HIGH_MSB                    0x80
#define DEFAULT_HIGH_LSB                    0x00
#define DEFAULT_HYSTERESIS                  2
#define DEFAULT_CALIBRATED_VOLTAGE_MSB      0xc3
#define DEFAULT_CALIBRATED_VOLTAGE_LSB      0x50
#define ERROR_GENERAL                       0x00
#define ERROR_SENSOR                        0x01
#define ERROR_MODULE                        0x02
#define TEMP_UNIT_KELVIN                    0
#define TEMP_UNIT_CELSIUS                   1
#define TEMP_UNIT_FAHRENHEIT                2
#define MODULE_LOW_ALARM                    1
#define MODULE_HIGH_ALARM                   2
#define CONFIG_ENABLE_LOW_ALARM             (1<<3)
#define CONFIG_ENABLE_HIGH_ALARM            (1<<4)
#define CONFIG_ENABLE_TURNX                 (1<<5)
#define CONFIG_ENABLE_TURNON_INVERT         (1<<6)
#define CONFIG_ENABLE_CONTINOUS_EVENTS      (1<<7)
#define EEPROM_ZONE                         0x41	// Zone node belongs to
#define EEPROM_SUBZONE                      0x42	// Sub zone node belongs to
#define EEPROM_CONTROLREG0                  0x43
#define EEPROM_CONTROLREG1                  0x44
#define EEPROM_CONTROLREG2                  0x45
#define EEPROM_CONTROLREG3                  0x46
#define EEPROM_CONTROLREG4                  0x47
#define EEPROM_CONTROLREG5                  0x48
#define EEPROM_REPORT_INTERVAL0             0x49
#define EEPROM_REPORT_INTERVAL1             0x4A
#define EEPROM_REPORT_INTERVAL2             0x4B
#define EEPROM_REPORT_INTERVAL3             0x4C
#define EEPROM_REPORT_INTERVAL4             0x4D
#define EEPROM_REPORT_INTERVAL5             0x4E
#define EEPROM_B_CONSTANT0_MSB              0x4F
#define EEPROM_B_CONSTANT0_LSB              0x50
#define EEPROM_B_CONSTANT1_MSB              0x51
#define EEPROM_B_CONSTANT1_LSB              0x52
#define EEPROM_B_CONSTANT2_MSB              0x53
#define EEPROM_B_CONSTANT2_LSB              0x54
#define EEPROM_B_CONSTANT3_MSB              0x55
#define EEPROM_B_CONSTANT3_LSB              0x56
#define EEPROM_B_CONSTANT4_MSB              0x57
#define EEPROM_B_CONSTANT4_LSB              0x58
#define EEPROM_B_CONSTANT5_MSB              0x59
#define EEPROM_B_CONSTANT5_LSB              0x5A
#define EEPROM_LOW_ALARM0_MSB               0x5B
#define EEPROM_LOW_ALARM0_LSB               0x5C
#define EEPROM_LOW_ALARM1_MSB               0x5D
#define EEPROM_LOW_ALARM1_LSB               0x5E
#define EEPROM_LOW_ALARM2_MSB               0x5F
#define EEPROM_LOW_ALARM2_LSB               0x60
#define EEPROM_LOW_ALARM3_MSB               0x61
#define EEPROM_LOW_ALARM3_LSB               0x62
#define EEPROM_LOW_ALARM4_MSB               0x63
#define EEPROM_LOW_ALARM4_LSB               0x64
#define EEPROM_LOW_ALARM5_MSB               0x65
#define EEPROM_LOW_ALARM5_LSB               0x66
#define EEPROM_HIGH_ALARM0_MSB              0x67
#define EEPROM_HIGH_ALARM0_LSB              0x68
#define EEPROM_HIGH_ALARM1_MSB              0x69
#define EEPROM_HIGH_ALARM1_LSB              0x6A
#define EEPROM_HIGH_ALARM2_MSB              0x6B
#define EEPROM_HIGH_ALARM2_LSB              0x6C
#define EEPROM_HIGH_ALARM3_MSB              0x6D
#define EEPROM_HIGH_ALARM3_LSB              0x6E
#define EEPROM_HIGH_ALARM4_MSB              0x6F
#define EEPROM_HIGH_ALARM4_LSB              0x70
#define EEPROM_HIGH_ALARM5_MSB              0x71
#define EEPROM_HIGH_ALARM5_LSB              0x72
#define EEPROM_SENSOR0_ZONE                 0x73
#define EEPROM_SENSOR0_SUBZONE              0x74
#define EEPROM_SENSOR1_ZONE                 0x75
#define EEPROM_SENSOR1_SUBZONE              0x76
#define EEPROM_SENSOR2_ZONE                 0x77
#define EEPROM_SENSOR2_SUBZONE              0x78
#define EEPROM_SENSOR3_ZONE                 0x79
#define EEPROM_SENSOR3_SUBZONE              0x7A
#define EEPROM_SENSOR4_ZONE                 0x7B
#define EEPROM_SENSOR4_SUBZONE              0x7C
#define EEPROM_SENSOR5_ZONE                 0x7D
#define EEPROM_SENSOR5_SUBZONE              0x7E
#define EEPROM_ABSOLUT_LOW0_MSB             0x7F
#define EEPROM_ABSOLUT_LOW0_LSB             0x80
#define EEPROM_ABSOLUT_LOW1_MSB             0x81
#define EEPROM_ABSOLUT_LOW1_LSB             0x82
#define EEPROM_ABSOLUT_LOW2_MSB             0x83
#define EEPROM_ABSOLUT_LOW2_LSB             0x84
#define EEPROM_ABSOLUT_LOW3_MSB             0x85
#define EEPROM_ABSOLUT_LOW3_LSB             0x86
#define EEPROM_ABSOLUT_LOW4_MSB             0x87
#define EEPROM_ABSOLUT_LOW4_LSB             0x88
#define EEPROM_ABSOLUT_LOW5_MSB             0x89
#define EEPROM_ABSOLUT_LOW5_LSB             0x8A
#define EEPROM_ABSOLUT_HIGH0_MSB            0x8B
#define EEPROM_ABSOLUT_HIGH0_LSB            0x8C
#define EEPROM_ABSOLUT_HIGH1_MSB            0x8D
#define EEPROM_ABSOLUT_HIGH1_LSB            0x8E
#define EEPROM_ABSOLUT_HIGH2_MSB            0x8F
#define EEPROM_ABSOLUT_HIGH2_LSB            0x90
#define EEPROM_ABSOLUT_HIGH3_MSB            0x91
#define EEPROM_ABSOLUT_HIGH3_LSB            0x92
#define EEPROM_ABSOLUT_HIGH4_MSB            0x93
#define EEPROM_ABSOLUT_HIGH4_LSB            0x94
#define EEPROM_ABSOLUT_HIGH5_MSB            0x95
#define EEPROM_ABSOLUT_HIGH5_LSB            0x96
#define EEPROM_HYSTERESIS_SENSOR0           0x97
#define EEPROM_HYSTERESIS_SENSOR1           0x98
#define EEPROM_HYSTERESIS_SENSOR2           0x99
#define EEPROM_HYSTERESIS_SENSOR3           0x9A
#define EEPROM_HYSTERESIS_SENSOR4           0x9B
#define EEPROM_HYSTERESIS_SENSOR5           0x9C
#define EEPROM_CALIBRATION_SENSOR0_MSB      0x9E
#define EEPROM_CALIBRATION_SENSOR0_LSB      0x9F
#define EEPROM_CALIBRATION_SENSOR1_MSB      0xA0
#define EEPROM_CALIBRATION_SENSOR1_LSB      0xA1
#define EEPROM_CALIBRATION_SENSOR2_MSB      0xA2
#define EEPROM_CALIBRATION_SENSOR2_LSB      0xA3
#define EEPROM_CALIBRATION_SENSOR3_MSB      0xA4
#define EEPROM_CALIBRATION_SENSOR3_LSB      0xA5
#define EEPROM_CALIBRATION_SENSOR4_MSB      0xA6
#define EEPROM_CALIBRATION_SENSOR4_LSB      0xA7
#define EEPROM_CALIBRATION_SENSOR5_MSB      0xA8
#define EEPROM_CALIBRATION_SENSOR5_LSB      0xA9
#define EEPROM_COEFFICIENT_A_SENSOR0_0      0xAA
#define EEPROM_COEFFICIENT_A_SENSOR0_1      0xAB
#define EEPROM_COEFFICIENT_A_SENSOR0_2      0xAC
#define EEPROM_COEFFICIENT_A_SENSOR0_3      0xAD
#define EEPROM_COEFFICIENT_B_SENSOR0_0      0xAE
#define EEPROM_COEFFICIENT_B_SENSOR0_1      0xAF
#define EEPROM_COEFFICIENT_B_SENSOR0_2      0xB0
#define EEPROM_COEFFICIENT_B_SENSOR0_3      0xB1
#define EEPROM_COEFFICIENT_C_SENSOR0_0      0xB2
#define EEPROM_COEFFICIENT_C_SENSOR0_1      0xB3
#define EEPROM_COEFFICIENT_C_SENSOR0_2      0xB4
#define EEPROM_COEFFICIENT_C_SENSOR0_3      0xB5
#define EEPROM_COEFFICIENT_A_SENSOR1_0      0xB6
#define EEPROM_COEFFICIENT_A_SENSOR1_1      0xB7
#define EEPROM_COEFFICIENT_A_SENSOR1_2      0xB8
#define EEPROM_COEFFICIENT_A_SENSOR1_3      0xB9
#define EEPROM_COEFFICIENT_B_SENSOR1_0      0xBA
#define EEPROM_COEFFICIENT_B_SENSOR1_1      0xBB
#define EEPROM_COEFFICIENT_B_SENSOR1_2      0xBC
#define EEPROM_COEFFICIENT_B_SENSOR1_3      0xBD
#define EEPROM_COEFFICIENT_C_SENSOR1_0      0xBE
#define EEPROM_COEFFICIENT_C_SENSOR1_1      0xBF
#define EEPROM_COEFFICIENT_C_SENSOR1_2      0xC0
#define EEPROM_COEFFICIENT_C_SENSOR1_3      0xC1
#define EEPROM_COEFFICIENT_A_SENSOR2_0      0xC2
#define EEPROM_COEFFICIENT_A_SENSOR2_1      0xC3
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

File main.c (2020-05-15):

/* ******************************************************************************
 * 	VSCP (Very Simple Control Protocol) 
 * 	http://www.vscp.org
 *
 *  Kelvin NTC10KA Module
 *  =====================
 *
 *  Copyright (C) 2000-2020 Ake Hedman, Grodans Paradis AB
 *                          http://www.grodansparadis.com
 *                          <akhe@grodansparadis.com>
 *
 *  This work is licensed under the Creative Common 
 *  Attribution-NonCommercial-ShareAlike 3.0 Unported license. The full
 *  license is available in the top folder of this project (LICENSE) or here
 *  http://creativecommons.org/licenses/by-nc-sa/3.0/legalcode
 *  It is also available in a human readable form here 
 *  http://creativecommons.org/licenses/by-nc-sa/3.0/
 * 
 *	This file is part of VSCP - Very Simple Control Protocol 	
 *	http://www.vscp.org
 *
 * ******************************************************************************
 */


#include "vscp_compiler.h"
#include "vscp_projdefs.h"

#include <p18cxxx.h>
#include <timers.h>
#include <adc.h>
#include <math.h>
#include <vscp_inttypes.h>
#include <ECAN.h>
#include <vscp-firmware.h>
#include <vscp_class.h>
#include <vscp_type.h>
#include "main.h" 
#include "version.h"
#include "ntc.h"


#if defined(_18F2580) 


#if defined(RELEASE)

#pragma config WDT = ON, WDTPS = 128
#pragma config OSC = HSPLL
#pragma config BOREN = BOACTIVE
#pragma config STVREN = ON
#pragma config BORV = 0			// 4.6V
#pragma config LVP = ON
#pragma config CPB = ON
#pragma config BBSIZ = 2048
#pragma config WRTD  = OFF

#pragma config EBTR0 = OFF
#pragma config EBTR1 = OFF
#pragma config EBTR2 = OFF
#pragma config EBTR3 = OFF

#pragma config EBTRB = OFF

#else

#pragma config WDT = OFF
#pragma config OSC = HSPLL
#pragma config PWRT = ON
#pragma config BOREN = BOACTIVE
#pragma config STVREN = ON
#pragma config BORV = 0			// 4.6V
#pragma config LVP = OFF
#pragma config CPB = OFF
#pragma config WRTD  = OFF

#pragma config EBTR0 = OFF
#pragma config EBTR1 = OFF
#pragma config EBTR2 = OFF
#pragma config EBTR3 = OFF

#pragma config EBTRB = OFF

#endif

#else if defined(_18F25K80) || defined(_18F26K80) || defined(_18F45K80) || defined(_18F46K80) || defined(_18F65K80) || defined(_18F66K80)


// CONFIG1L
#pragma config SOSCSEL = DIG    // RC0/RC is I/O
#pragma config RETEN = OFF      // Ultra low-power regulator is Disabled (Controlled by REGSLP bit).
#pragma config INTOSCSEL = HIGH // LF-INTOSC in High-power mode during Sleep.
#pragma config XINST = OFF      // No extended instruction set

// CONFIG1H
#pragma config FOSC = HS2       // Crystal 10 MHz
#pragma config PLLCFG = ON      // 4 x PLL

// CONFIG2H
#pragma config WDTPS = 1048576  // Watchdog prescaler
#pragma config BOREN = SBORDIS  // Brown out enabled
#pragma config BORV  = 0        // 3V

// CONFIG3H
#pragma config CANMX = PORTB    // ECAN TX and RX pins are located on RB2 and RB3, respectively.
#pragma config MSSPMSK = MSK7   // 7 Bit address masking mode.
#pragma config MCLRE = ON       // MCLR Enabled, RE3 Disabled.

// CONFIG4L
#pragma config STVREN = ON      // Stack Overflow Reset enabled
#pragma config BBSIZ = BB2K     // Boot block size 2K

#ifdef DEBUG
#pragma config WDTEN = OFF      // WDT disabled in hardware; SWDTEN bit disabled.
#else
#pragma config WDTEN = ON       // WDT enabled in hardware; 
#endif


#endif


// The device URL (max 32 characters including null termination)
const uint8_t vscp_deviceURL[] = "www.eurosource.se/ntc10KA_3.xml";

// Global Variable Declarations
int16_t current_temp[6]; // Current temperature

uint8_t adc[NUMBER_OF_TEMP_SERIES * 12];    // Current ADC values
uint8_t adc_conversion_flags;               // Bits to flag new ADC values
uint8_t adc_series_counter;                 // Series counter

volatile uint16_t sendTimer;                // Timer for CAN send
volatile uint32_t measurement_clock;        // Clock for measurements
volatile uint32_t timeout_clock;            // Clock used for timeouts

uint8_t seconds;                // counter for seconds

uint8_t seconds_temp[6];        // timers for temp event

// Alarm flag bits
uint8_t low_alarm;
uint8_t high_alarm;

// Thermistor coefficients
double sh_coefficients[6*3];    // 6 sensors each with 3 32-bit constants

///////////////////////////////////////////////////////////////////////////////
// Isr() 	- Interrupt Service Routine
//      	- Services Timer0 Overflow
//      	- Services GP3 Pin Change
//////////////////////////////////////////////////////////////////////////////

void interrupt low_priority interrupt_at_low_vector( void )
{
    // Check timer
    if (INTCONbits.TMR0IF) { // If A Timer0 Interrupt, Then

        // Reload value for 1 ms resolution
        WriteTimer0(TIMER0_RELOAD_VALUE);

        vscp_timer++;
        vscp_configtimer++;
        measurement_clock++;
        timeout_clock++;
        sendTimer++;

        // Check for init. button
        if (!(PORTC & 0x01)) {
            // Active
            vscp_initbtncnt++;
        }
        else {
            vscp_initbtncnt = 0;
        }

        // Status LED
        vscp_statuscnt++;
        if ( ( VSCP_LED_BLINK1 ==
                 vscp_initledfunc) && (vscp_statuscnt > 100)) {
            if ( PORTC & 0x02 ) {
                PORTC &= ~0x02;
            }
            else {
                PORTC |= 0x02;
            }
            vscp_statuscnt = 0;
        }
        else if (VSCP_LED_ON == vscp_initledfunc) {
            PORTC |= 0x02;
            vscp_statuscnt = 0;
        }
        else if (VSCP_LED_OFF == vscp_initledfunc) {
            PORTC &= ~0x02;
            vscp_statuscnt = 0;
        }

        INTCONbits.TMR0IF = 0; // Clear Timer0 Interrupt Flag

    } // Timer & button

    // Check ADC
    if ( PIR1bits.ADIF ) {

#if defined(_18F2580)        
        switch (0x3C & ADCON0) {
#else
        switch (0x7C & ADCON0) {   
#endif            

            case SELECT_ADC_TEMP0:
                
                // Read conversion
                adc[(12 * adc_series_counter) + 0] = ADRESH;
                adc[(12 * adc_series_counter) + 1] = ADRESL;
                
                // Start new conversion
                ADCON0 = SELECT_ADC_TEMP1 + 1;

                // Mark that a new adc value is available if a full series
                // has been completed.
                if ((NUMBER_OF_TEMP_SERIES - 1) == adc_series_counter) {
                    adc_conversion_flags |= 1;
                }
                break;

            case SELECT_ADC_TEMP1:
                
                // Read conversion
                adc[(12 * adc_series_counter) + 2] = ADRESH;
                adc[(12 * adc_series_counter) + 3] = ADRESL;

                // Start new conversion
                ADCON0 = SELECT_ADC_TEMP2 + 1;

                // Mark that a new adc value is available if a full series
                // has been completed.
                if ((NUMBER_OF_TEMP_SERIES - 1) == adc_series_counter) {
                    adc_conversion_flags |= 1 << 1;
                }
                break;

            case SELECT_ADC_TEMP2:
                
                // Read conversion
                adc[(12 * adc_series_counter) + 4] = ADRESH;
                adc[(12 * adc_series_counter) + 5] = ADRESL;

                // Start new conversion
                ADCON0 = SELECT_ADC_TEMP3 + 1;

                // Mark that a new adc value is available if a full series
                // has been completed.
                if ((NUMBER_OF_TEMP_SERIES - 1) == adc_series_counter) {
                    adc_conversion_flags |= 1 << 2;
                }
                break;

            case SELECT_ADC_TEMP3:
                
                // Read conversion
                adc[(12 * adc_series_counter) + 6] = ADRESH;
                adc[(12 * adc_series_counter) + 7] = ADRESL;
                
                // Start new conversion
                ADCON0 = SELECT_ADC_TEMP4 + 1;

                // Mark that a new adc value is available if a full series
                // has been completed.
                if ((NUMBER_OF_TEMP_SERIES - 1) == adc_series_counter) {
                    adc_conversion_flags |= 1 << 3;
                }
                break;

            case SELECT_ADC_TEMP4:
                
                // Read conversion
                adc[(12 * adc_series_counter) + 8] = ADRESH;
                adc[(12 * adc_series_counter) + 9] = ADRESL;
                
                // Start new conversion
                ADCON0 = SELECT_ADC_TEMP5 + 1;

                // Mark that a new adc value is available if a full series
                // has been completed.
                if ((NUMBER_OF_TEMP_SERIES - 1) == adc_series_counter) {
                    adc_conversion_flags |= 1 << 4;
                }
                break;

            case SELECT_ADC_TEMP5:
                
                // Read conversion
                adc[(12 * adc_series_counter) + 10] = ADRESH;
                adc[(12 * adc_series_counter) + 11] = ADRESL;
                
                // Start new conversion
                ADCON0 = SELECT_ADC_TEMP0 + 1;

                // Mark that a new adc value is available if a full series
                // has been completed.
                if ((NUMBER_OF_TEMP_SERIES - 1) == adc_series_counter) {
                    adc_conversion_flags |= 1 << 5;
                }

                // Fill next series
                adc_series_counter++;
                if (adc_series_counter >= NUMBER_OF_TEMP_SERIES) {
                    adc_series_counter = 0;
                }
                break;

            default:
                
                // Start new conversion
                ADCON0 = SELECT_ADC_TEMP0 + 1;
                adc_series_counter = 0;
                break;
                
        }

        // Start conversion
        ConvertADC();

        PIR1bits.ADIF = 0; // Reset interrupt flag

    } // ADC

    return;
}


//***************************************************************************
// Main() - Main Routine
//***************************************************************************

void main()
{
    uint32_t i;
    
    init();
    
    // Check VSCP persistent storage and
    // restore if needed
    if ( !vscp_check_pstorage() ) {

        // Spoiled or not initialised - reinitialise
        init_app_eeprom();

    }

    vscp_init(); // Initialise the VSCP functionality

    while (TRUE) { // Loop Forever

        ClrWdt(); // Feed the dog

        if ( ( vscp_initbtncnt > 2500 ) &&
             ( VSCP_STATE_INIT != vscp_node_state ) ) {

            // Init. button pressed
            vscp_nickname = VSCP_ADDRESS_FREE;
            eeprom_write(VSCP_EEPROM_NICKNAME, VSCP_ADDRESS_FREE);
            vscp_init();

        }


        // Check for a valid  event
        vscp_imsg.flags = 0;
        vscp_getEvent();


        switch (vscp_node_state) {

            case VSCP_STATE_STARTUP: // Cold/warm reset

                // Get nickname from EEPROM
                if (VSCP_ADDRESS_FREE == vscp_nickname) {
                    // new on segment need a nickname
                    vscp_node_state = VSCP_STATE_INIT;
                }
                else {
                    // been here before - go on
                    vscp_node_state = VSCP_STATE_ACTIVE;
                    vscp_goActiveState();
                }
                break;

            case VSCP_STATE_INIT: // Assigning nickname
                vscp_handleProbeState();
                break;

            case VSCP_STATE_PREACTIVE: // Waiting for host initialization
                vscp_goActiveState();
                break;

            case VSCP_STATE_ACTIVE: // The normal state

                // Check for incoming message?
                if (vscp_imsg.flags & VSCP_VALID_MSG) {

                    if ( VSCP_CLASS1_PROTOCOL == vscp_imsg.vscp_class ) {

                        // Handle protocol event
                        vscp_handleProtocolEvent();

                    }
                    else if ( ( VSCP_CLASS1_CONTROL == vscp_imsg.vscp_class ) &&
                                ( VSCP_TYPE_CONTROL_SYNC == vscp_imsg.vscp_type ) ) {
                        handle_sync();
                    }

                }
                break;

            case VSCP_STATE_ERROR: // Everything is *very* *very* bad.
                vscp_error();
                break;

            default: // Should not be here...
                vscp_node_state = VSCP_STATE_STARTUP;
                break;

        }


        // do a measurement if needed
        if ( measurement_clock > 1000 ) {

            measurement_clock = 0;
            doOneSecondWork();
            seconds++;

            // Temperature report timers are only updated if in active
            // state
            if (VSCP_STATE_ACTIVE == vscp_node_state) {
                for (i = 0; i < 6; i++) {
                    seconds_temp[i]++;
                }
            }

            if (seconds > 59) {
                seconds = 0;
            }

            // Do VSCP one second jobs
            // Check if alarm events should be sent
            if (VSCP_STATE_ACTIVE == vscp_node_state) {
                vscp_doOneSecondWork();
            }

            // Also do some work
            doWork();

	}

    } // while
}


///////////////////////////////////////////////////////////////////////////////
// doWork
//
// The actual work is done here.
//

void doWork(void)
{
    uint8_t i, j;
    uint16_t B;
    double avarage;
    double resistance;
    double Rinf;
    double temp;
    double v;
    double calVoltage;

    calVoltage = (double)construct_unsigned16( eeprom_read(EEPROM_CALIBRATED_VOLTAGE_MSB),
                                        eeprom_read(EEPROM_CALIBRATED_VOLTAGE_LSB) ) / 10000.0;

    // Check if there are new adc values to
    // convert to temperatures

    for (i = 0; i < 6; i++) {

        if (adc_conversion_flags & 1 << i) {

            // Calculate mean value for this adc
            avarage = 0;
            for (j = 0; j < NUMBER_OF_TEMP_SERIES; j++) {
                avarage +=  construct_unsigned16( adc[12 * j + 2 * i], 
                                                    adc[12 * j + 2 * i + 1] );
            }
            avarage = avarage / NUMBER_OF_TEMP_SERIES;

            if (1) {

                // Use B-constant
                // ==============
                // http://en.wikipedia.org/wiki/Thermistor
                // R1 = (R2V - R2V2) / V2  R2= 10K, V = 5V,  V2 = adc * voltage/1024
                // T = B / ln(r/Rinf)
                // Rinf = R0 e (-B/T0), R0=10K, T0 = 273.15 + 25 = 298.15

                B = construct_unsigned16( eeprom_read(2 * i + EEPROM_B_CONSTANT0_MSB ),
                                        eeprom_read(2 * i + EEPROM_B_CONSTANT0_LSB) );

                
                Rinf = 10000.0 * exp(B/-298.15);
                
#if defined(_18F2580)   
                // V2 = adc * voltage/1024
                v = calVoltage * (double)avarage/1024;
#else  
                // V2 = adc * voltage/4096
                v = calVoltage * (double)avarage/4096;
#endif                
                // R1 = (R2V - R2V2) / V2  R2= 10K, V = 5V,  V2 = adc * voltage/1024
                resistance = ( 10000.0*(calVoltage - v) ) / v;
                
                //itemp = r;
                temp = ((double) B) / log(resistance / Rinf);
                //itemp = log(r/Rinf);
                temp -= 273.15; // Convert Kelvin to Celsius
                
                //avarage = testadc;
                /*  https://learn.adafruit.com/thermistor/using-a-thermistor
                avarage = (1023/avarage) - 1;
                avarage = 10000 / avarage;      // Resistance of termistor
                //temp = avarage/10000;           // (R/Ro)
                temp = 10000/avarage;
                temp = log(temp);               // ln(R/Ro)
                temp /= B;                      // 1/B * ln(R/Ro)
                temp += 1.0 / (25 + 273.15);    // + (1/To)
                temp = 1.0 / temp;              // Invert
                temp -= 273.15;
                */
                current_temp[ i ] = ( current_temp[ i ] + ( (long)(temp * 100) + getCalibrationValue( i ) ) ) / 2;

            }
            else {

                // Use S-H equation
                // ================

                // Assuming a 10k Thermistor.  Calculation is actually: Resistance = (1024/ADC)
#if defined(_18F2580)                 
                resistance = ((10240000 / adc[2 * i + 1]) - 10000);
#else 
                // Assuming a 10k Thermistor.  Calculation is actually: Resistance = (4096/ADC)
                resistance = ((40960000 / adc[2 * i + 1]) - 10000);     
#endif                

                /********************************************************************/
                /* Utilises the Steinhart-Hart Thermistor Equation:					*/
                /*    Temperature in Kelvin = 1 / {A + B[ln(R)] + C[ln(R)]^3}		*/
                /********************************************************************/
                temp = log(resistance);
                temp = 1 / (sh_coefficients[i * 3] + (sh_coefficients[i * 3 + 1] * temp) +
                        (sh_coefficients[i * 3 + 2] * temp * temp * temp));
                temp = temp - 273.15; // Convert Kelvin to Celsius
                current_temp[ i ] = (current_temp[ i ] + ((long) (temp * 100) + getCalibrationValue(i))) / 2;

            }

            // Reset flag
            adc_conversion_flags &= ~(1 << i);

        }
    }

}

///////////////////////////////////////////////////////////////////////////////
// doOneSecondWork
//
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

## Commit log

2015-02-18 Moved calibration registers to page 1 and removed indexed storage
2015-02-18 Added default values to mdf. Calibration values are now stored flat
2015-02-18 Fixed error in absolute low/high value registers
    [main.c]
2015-03-03 Added missing update of vscp_configtimer
    [main.c]
2015-07-27 Fixed problem with send timeout
    [main.c]
2015-08-17 Released eagle design files
    [1-wire.sch, S&H.xls, ir_transmitter.sch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]
2015-09-09 Wrong (old) schema was previously uploaded. Fixed now.
    [10kThermistorTable.ods, 1k.xls, bom.ods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]
2015-09-12 Added missing files
    [kelvin_ntc_B.sch]
2015-09-28 Sensor is read wrongly in register view. Fixed
    [main.c]
2015-11-22 Color for abstraction low sensor alarm for sensor 0 corrected
    [main.c]
2015-11-26 Fixed problem with low/high limits with negative values. Also limits now are in degrees as is hysteresis as well.
    [main.c]
2015-12-17 Added images
    [bom.ods]
2016-02-04 Temperature calibration value was calulated in the wrong way.
    [mainboard_hole_din_pa3.drl]
2016-03-06 C14 should be 10K
    [kelvin_ntc_B.brd, kelvin_ntc_B.sch]
2016-03-23 Fixed bug in control byte write routine
    [main.c]
2016-03-23 Fixed XML build error
    [main.c]
2016-03-29 Raw A/D register values was displayed in wrong order. Fixed.
    [main.c]
2016-04-08 Fixed default value for unit
    [main.c]
2016-04-08 Fixed mdf bugs in control registors refering to sensor 0 on all
2016-04-08 Fixed reference to sensor 0 in low/hig registers
2016-04-19 RA4 set to input to prevent collision with VCAP circuits in PIC18F2580. Brown out raised to maximum (3V & 4.6V). Valuable input from Anders Forsgren, AJE Electronics AB.
    [main.c]
2020-05-04 Moved manual to docsify
    [configure.txt]
2020-05-15 init timer is now 2500 ms instead of 250 ms
2025-02-09 Added initial text for new manual
    [10kThermistorTable.ods, S&H.xls, configure.txt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]
2025-02-17 Updated README with correct links
    [configure.txt]
2025-08-18 Converted schema to kicad
    [kelvin_ntc_B.kicad_pcb, kelvin_ntc_B.kicad_sch]
2025-09-05 Retired old manual
    [configure.txt, diff.txt]

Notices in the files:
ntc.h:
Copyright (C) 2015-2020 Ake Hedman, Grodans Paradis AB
